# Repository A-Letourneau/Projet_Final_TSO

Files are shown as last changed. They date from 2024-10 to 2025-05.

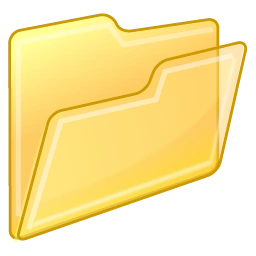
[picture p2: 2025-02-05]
Code/Mallette_GUI/Code de test/Folder.png

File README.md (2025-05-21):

# Projet de Mallette D'évasion 🎲🔐

Bienvenue dans notre projet de **jeu d'évasion** Pour le cours de *Planification de projet* de la *technique de système ordiné*! Ce jeu mettra à l'épreuve vos capacités de réflexion, de résolution d'énigmes,
et les matières vues en classe. Explorez une mallette remplit de mystère et découvrez des secrets pour vous échapper avant la fin du temps imparti !

---

## 🚀 Fonctionnalités principales
- **Scénarios immersifs** : Plongez dans des histoires captivantes, adaptées à tous les publics.
- **Énigmes variées** : Résolvez des casse-têtes mêlant logique, observation, et coordination.
- **Système de progression** : Sauvegardez votre progression et débloquez de nouveaux défis.
- **Grande Modularité** : Changez les énigmes ou encore provoquez des erreurs pour vos élèves.

---

## 🛠️ Technologies utilisées
- **Backend** : [Python3, C++]
- **Interface utilisateur** : Design intuitif avec [SimpleGUI]

---

## 📦 Installation

### Prérequis
- Les outils nécessaires : [Python, C++, SimpleGUI]
- Matériel physique : [Raspberry Pi4b, esp32C3 DevKit2, bouton, potentiomètre, switch]

---

📧 Contact
Pour toute question ou suggestion :

**Pour contacté Louis :**
- Email : A21.louis.boisvert@cegepsherbrooke.qc.ca
- GitHub : https://github.com/L3MMINGS

**Pour contacté Alexis :**
- Email : a22.alexis.letourneau@cegepsherbrooke.qc.ca
- GitHub : https://github.com/A-Letourneau

Bon jeu et amusez-vous à vous échapper ! 🚪✨

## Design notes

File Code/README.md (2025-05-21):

# 📂 Code

Ce dépôt regroupe 4 ensembles de fichiers essentiels pour le fonctionnement du prototype. 

## 📂 I2C et JSON pour ESP32  
Ce dossier contient le code en C++ chargé dans les ESP32.  
Il permet à ces derniers d’envoyer des messages JSON en I2C contenant l'état des objets interactifs au Raspberry PI.  

---

## 📂 Interface Graphique (Mallette GUI)  
Ce dossier contient :
- Le code Python nécessaire pour afficher les données i2c reçues sous forme de JSON dans une interface.  
- L’affichage à l’écran est réalisé à l’aide de la bibliothèque **PySimpleGUI**. 

---

## 📂 Clavier esp32
Ce dossier contient :  
- Le code "main.py" qui va dans un clavier esp32 qui utilise la librairie kmk_firmware .  

---

### 🛠️ Notes
Chaque dossier est structuré pour permettre une utilisation autonome des fonctionnalités qu’il contient. Consultez les fichiers README individuels dans chaque dossier pour plus de détails.

Correction

28 oct 5/5 

4 nov 5/5

11 nov 5/5 

24 nov 5/5 (Bravo pour le beau readme.md du dossier principal).

3 déc 5/5

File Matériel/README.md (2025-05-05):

# Dossier pour les schémas Altium
Ce document contient les schémas électriques et le schéma des PCB.

---
## 📂Fichier de fabrication 
Les fichiers de fabrication à envoyer au fabricant de PCB

## 📂PCB mallette Altium
Les fichier Altium pour le schéma électrique et le PCB

## 📂Fichier la clé du savoir logo
Les fichiers contenant l'espace de travail et quelques version du logo de la mallette.
Le logo à été fait par Alexis Desainde.

## Schema_MalletteDevasion_BOM REV 1.00 (BOM)
Liste des composants du PCB

## Plan de test PCB mallette
Les tests pour le bon fonctionnement du PCB et les améliorations possibles

## Équerre 2 inserts 
Fichier stl qui contient les supports pour tenir la vitre dans la mallette
---

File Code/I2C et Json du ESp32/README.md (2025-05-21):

# Programme de Communication I2C avec JSON pour ESP32

Ce fichier contient tous les codes fait en rapport avec les esp32 en c++

Les programmes de CODE_ESP32_POT, CODE_ESP32_SW et CODE_ESP32_CROCO permet d’envoyer les états des objets interactifs (interrupteur, potentiomètre et fils banane/croco) dans un JSON via communication I2C à un maître.  
Le maître utilisé dans notre projet est un **Raspberry Pi 4**.  
Les sub (esclaves) utilisés dans notre projet est le **esp32 c3 devkit 02**

## Configuration d’un Nouveau Module d’Énigme avec un ESP32  

Pour ajouter un nouveau module, suivez ces étapes :  

1. **Définir une adresse différente pour chaque module :**  
   Attribuez une valeur unique à **`SLAVE_ADDR`**, différente de celles des autres ESP32 connectés au Raspberry Pi.  

2. **Configurer les broches I2C (si nécessaire) :**  
   - Modifiez la ligne **`Wire.setPins()`** pour définir les broches I2C souhaitées.  
   - Si l’ESP32 utilise déjà des broches par défaut, cette ligne peut être supprimée.  
   - Les pattes arbitraires pour le i2c que nous avons choisi est le 6 pour SDA et 7 pour SCL.

3. **Personnaliser l’identifiant du module :**  
   Changez la valeur de la variable **`ESP32_NAME`** pour identifier le module.  

4. **Adapter le fichier `platformio.ini` :**  
   - Vérifiez que le fichier **`platformio.ini`** correspond à la carte ESP32 utilisée.  
   - Si vous utilisez une carte différente (par ex. **ESP32-WROOM** ou **ESP32C3 DevKit2**), adaptez les configurations en conséquence.  

---

### Remarque  
Assurez-vous que tous les modules sont correctement configurés pour éviter les conflits d’adresse sur le bus I2C.
Utilisez i2cdetect -i 0 sur le cmd du pi pour détecter les connections i2c

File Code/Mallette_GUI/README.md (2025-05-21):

# Dossier de Tests pour l'interface GUI du PI

Ce dossier contient plusieurs répertoire de test et un répertoire du prototype fonctionnel.

# Contient
- "Code de test" : Dossier de code de test pour développer l'interface 
- "Prototype Fonctionnel sur PI" : Les fichiers de code fonctionnel sur le PI

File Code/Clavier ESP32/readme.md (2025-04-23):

Pour entrer dans le mode programmation du clavier esp32 :
Appuyer sur le bouton RESET
En restant appuyé, appuyer sur le potentiomètre
Puis relacher le bouton RESET
Un répertoire devrait s'ouvrir sur l'ordinateur

Pour programmer votre clavier esp32:
Remplacer le fichier code.py dans le répertoire avec le fichier code.py sur le git
Le fichier important est code.py qui peut être modifié selon les informations sur : https://github.com/KMKfw/kmk_firmware

La souris est déjà configuré, mais voici comment configurer la souris avec le clavier esp32:
Dans le fichier code.py
1 - Ajouter la ligne "from kmk.modules.mouse_keys import MouseKeys" dans "# Keys"
2 - Ajouter la ligne "mouse = MouseKeys()" dans "#KEYBOARD SETUP"
3 - Ajouter "mouse" dans la liste de module "keyboard.modules = [encoder_handler, tapdance, mouse]"
Optionnel - mettre :
"mousekeys = MouseKeys(
    max_speed = 10,
    acc_interval = 20, # Delta ms to apply acceleration
    move_step = 1
)" pour ajuster la vitesse

La configuration actuelle des 12 touches:
[A]         [MS_UP]     [MS_UP]     [BSPACE]
[MS_LEFT]   [MB_LMB]    [MS_RIGHT]  ['+']
[MS_DOWN]   [MS_DOWN]   [keypad_3]  ['-']

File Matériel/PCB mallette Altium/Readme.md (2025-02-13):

# Mallette d'Évasion

## Description du Projet
La **Mallette d'Évasion** est un projet réalisé dans le cadre du cours **247-67P-SH Projet de fin d'études** en génie électrique. Il s'agit d'un système électronique basé sur un **Raspberry Pi 4** et plusieurs **ESP32-C3**, intégrant divers capteurs et composants pour résoudre des énigmes interactives.

## Concepteurs
- **Louis Boisvert**
- **Alexis Letourneau**

## Date
- **30 janvier 2025**

## Technologies Utilisées
- **Raspberry Pi 4 Model B (4GB)**
- **ESP32-C3-DEVKITC-02**
- **I2C (SDA/SCL)**
- **Boutons et interrupteurs**
- **Bandes de DEL**
- **Potentiomètres**
- **Pinces crocodiles**
- **PCB personnalisé**

## Schémas Principaux
1. **Raspberry_Pi** : Gestion centrale du système
2. **Schéma_Bloc** : Vue d'ensemble des connexions
3. **Énigme1_Interrupteur** : Activation d'un mécanisme via interrupteurs
4. **Énigme2_Pince_Banane** : Détection de contacts avec pinces crocodiles
5. **Énigme3_Potentiomètre** : Réglage d'une valeur par potentiomètres

## Fonctionnalités
- **Communication entre Raspberry Pi et ESP32 via I2C**
- **Gestion des entrées/sorties GPIO pour les énigmes**
- **Alimentation 3.3V et 5V pour les composants**
- **Intégration de multiples résistances et condensateurs pour stabilisation**
- **Utilisation de buffers 74HC1G125GV pour sécuriser les signaux**

## Instructions d'Utilisation
1. **Alimenter le système** : Assurez-vous que le Raspberry Pi et les ESP32 sont correctement branchés.
2. **Vérifier les connexions I2C** : Assurez-vous que les broches SDA et SCL sont bien connectées.
3. **Démarrer les énigmes** : Interagir avec les boutons, interrupteurs, pinces et potentiomètres pour progresser.

## Développement et Déploiement
- **Code source** : À stocker sur le Raspberry Pi
- **Configuration des GPIO** : À vérifier dans le script de contrôle
- **Tests** : Vérifier chaque énigme séparément avant l'intégration complète

## Améliorations Possibles
- Ajout d'un affichage LCD ou OLED pour des indices visuels
- Intégration de modules audio pour une meilleure immersion
- Optimisation du code pour améliorer la réactivité

## Licence
Ce projet est réalisé dans le cadre académique et son utilisation est limitée à des fins éducatives.

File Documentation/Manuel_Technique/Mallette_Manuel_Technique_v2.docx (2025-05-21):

Louis Boisvert

Alexis Létourneau

Groupe : 2317

La clé du savoir

Manuel technique présenté à :

Benoit Beaulieu

Nicolas Huppé

Louis-Philippe Gauthier

Étienne Desbiens

Département du génie électrique

Pour le cours :

247-67P-SH PROJET DE FIN D'ÉTUDES

Cégep de Sherbrooke

Mai 2025

# 1 Description générale du projet:

InXtremis est un centre d'évasion situé au cœur du centre-ville de Sherbrooke, dirigé par un ancien étudiant en Technologie de Systèmes Ordinés (TSO). Le propriétaire aspire à concevoir une nouvelle salle intégrant des éléments interactifs électronique grâce à des dispositifs électroniques dissimulés dans les énigmes. Plusieurs de ses salles actuelles utilisent déjà un ou deux dispositifs électroniques permettant d'ouvrir des portes et de suivre le progrès des joueurs. Cependant, il souhaite aller encore plus loin en créant une salle entièrement interconnectée, sans cadenas pour rythmer la progression.

Si les mécanismes simples, comme l'ouverture d'une énigme après la résolution de la précédente, sont faciles à mettre en place, le propriétaire ambitionne d'offrir une expérience encore plus impressionnante avec une énigme finale particulièrement spectaculaire. Pour concrétiser cette vision, il fait appel aux finissants du programme TSO.

L'objectif est de concevoir un module sous la forme d’une mallette renfermant une série de plusieurs énigmes. Le temps nécessaire pour résoudre ces énigmes devra être compris entre 5 et 10 minutes. Le module devra également offrir une remise en court pour accueillir rapidement la prochaine équipe.

La mallette devra être robuste pour résister à une mauvaise manipulation ou à une utilisation intensive. Le circuit électronique devra être facilement accessible pour les interventions de maintenance, de dépannage ou de démonstration. De plus, il devra pouvoir communiquer avec les autres éléments de la salle pour suivre la progression des joueurs et détecter des problèmes éventuels, comme la tentative de contourner une énigme.

Voici une photo de la mallette assemblée :

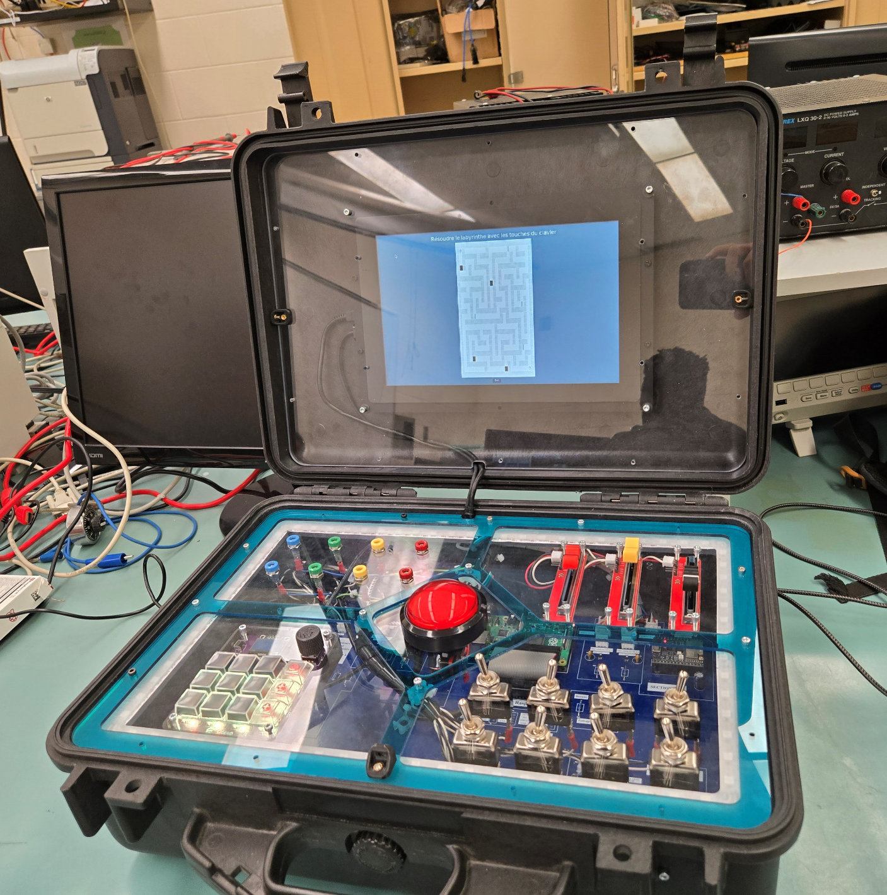
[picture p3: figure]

Figure 1 : Mallette assemblée

# 2 Fonctionnement de la mallette:

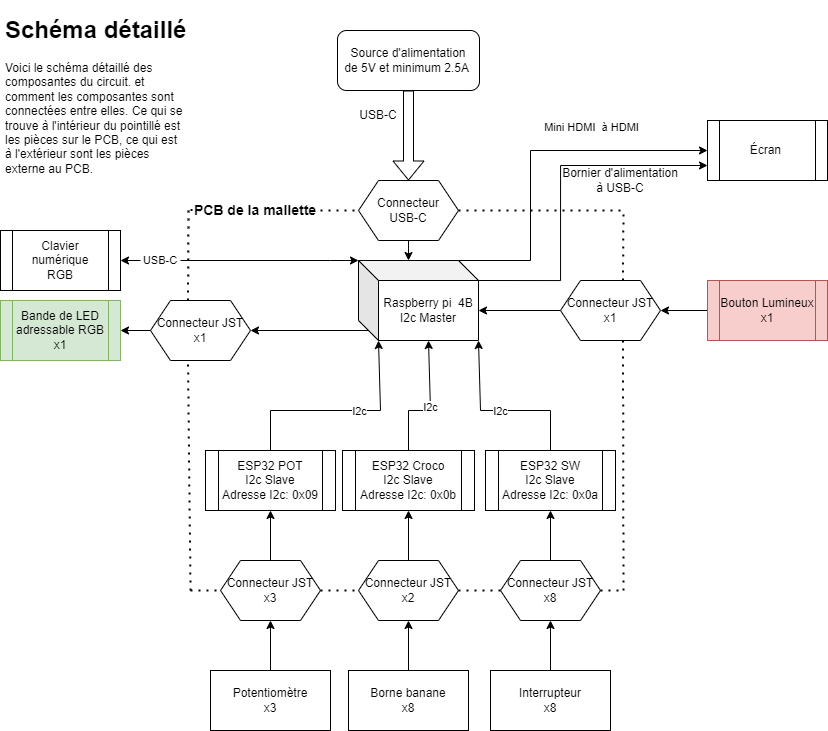
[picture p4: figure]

3.5 A

Figure 2 : Schéma de connections des composantes

## 2.1 Descriptions générales du schéma :

La mallette est composée d’un Raspberry Pi connecté en I2C en «Main» avec 3 esp32 en mode «Sub» et d’un clavier esp32 connecté au port USB du Pi. Les 3 esp32 sont connectés à des « éléments interactifs » comme des boutons, des interrupteurs, des potentiomètres et des bornes bananes avec des connecteurs JST.

Présentement, un des esp32 est connecté avec 8 interrupteurs, un autre esp32 avec 3 potentiomètres coulissant et un esp32 avec 8 bornes bananes. Dans cette architecture, le Pi fait des requêtes I2C au esp32 à chaque intervalle en secondes fixé dans le code et reçoit un JSON contenant les valeurs des éléments interactifs des esp32. Ces valeurs sont ensuite intégrées dans une énigme créée en python qui s’affiche sur un mini écran connecté au Pi.

Le clavier esp32 utilise une librairie spéciale qui permet de s’en servir en clavier et en souris. Le clavier esp32 vient pré assemblé avec 12 touches programmables.

Le PI contrôle aussi des bandes de DEL adressable pour illuminer la mallette et indiquer la réussite des énigmes.

Le PI est aussi connecté à un bouton lumineux. Le Pi détecte l’état du bouton et peut contrôler sa DEL interne.

Comme un des buts principales de la mallette est d’être modulable, elle n’a pas de programmation prédéterminée, par exemple : Le bouton lumineux pourrait tant allumer les bandes de DEL qu’être un élément de réponse dans une des énigmes. Les bandes de DEL pourrait illuminer la mallette, être un indice ou indiquer le temps avec des clignotements de plus en plus rapidement. Cependant, la mallette contient un exemple d’une série de d’énigme en python qui utilise tous les éléments interactifs de la mallette.

## 2.2 Raspberry Pi :

- Le Pi est le « Main » dans la communication I2C et envoie des requêtes d’informations au ESP32 très fréquemment (50 ms de base). Il reçoit un JSON comportant le nom du esp32 et l’état de ses éléments interactifs.
- Le Pi reçoit ces informations et intègre ces informations dans des énigmes. Les énigmes sont affichées sur une interface utilisateur qui utilise la librairie PySimpleGUI. Chaque énigme intègre différents éléments interactifs.
- Lors du démarrage du Pi, le programme « autostart » ouvre automatiquement le programme de série d’énigme.
- Le Pi prend en charge un clavier esp32 qui se connecte sur un port USB pour contrôler des lettres et la souris
- Le Pi reçoit l’état d’un bouton lumineux et peut faire allumer sa DEL.

## 2.3 Esp32 :

- Chaque ESP32 lit l’état des éléments interactifs et l’envoi en JSON au Pi via i2c. Les ESP32 sont des « Sub » attendant les requêtes du Raspberry Pi.
- Voici un exemple de JSON envoyé au PI :

{ «NomEsp32 »: « I2C _SW », « JsonData » : {« SW1 »: « 0 » , « SW2 »: « 1 » , « SW3 »: « 0 » } }

Dans ce cas, le nom du esp32 est le « I2C _SW », donc celui avec des interrupteurs, et le Pi reçoit que le bouton numéro 2 est appuyé. Le JsonData pourrait aussi contenir des valeurs analogues comme avec le esp32 « I2C _POT » qui s’occupe des potentiomètres.

- Le code de chaque esp32 est en c++ Arduino.
- Chaque esp32 est codé avec un « battement de cœur » sur sa DEL Neopixel qui montre que le esp32 est actif au démarrage et durant la communication I2C entre le esp32 et le Pi.

## 2.4 Connecteurs JST :

- Les connecteurs JST permettent de faire la connexion rapide et interchangeable entre la carte électrique (PCB) et le matériel externe tel que les éléments interactifs et les bandes de DEL.

## 2.5 Mini écran :

- Le mini écran est le moniteur du Pi et affiche la série l’énigmes.
- Le mini écran peut aussi servir à offrir des indices, un message de fin et de début ainsi qu’une mise en situation.
- Le mini écran possède aussi des haut-parleurs intégrés permettant de jouer différents sons selon les actions effectuées par l’utilisateur. Cependant cette fonctionnalité n’est pas utilisée.

## 2.6 Bandes de DEL adressable :

- Les bandes de DEL adressable permettent d’ajouter un élément visuel à la mallette.
- Les bandes de DEL adressable sont contrôlées par le Raspberry Pi et permettre présentement de signaler à l’utilisateur la réussite d’une énigme par la couleur verte ou l’échec de l’énigme par la couleur rouge. Les bandes de DEL adressable pourrait aussi illuminer la mallette, être un indice ou indiquer le temps qui découle avec des clignotement de plus en plus rapidement.

## 2.7 Rôle du bouton lumineux :

- Le Pi détecte l’état du bouton lumineux et peut contrôler la DEL interne bouton lumineux .
- Le bouton lumineux pourrait permettre d’arrêter le décompte mettant fin à la série d’énigmes. Pour l’instant, il active uniquement la fonction Rainbow() des DEL.

## 2.8 Alimentation :

- Un bloc d’alimentation murale fournira une tension de 5V par USB-C au circuit électrique (PCB). Il sera possible de connecter un chargeur portatif (pile de 5V avec prise USB-C) au lieu de le brancher au mur lors de démonstration où les prises murales ne sont pas facilement accessibles.
- Avec un mesureur de courant USB, nous avons déterminé que le courant maximale de toute la mallette est de 3.2 ampères.
- Les esp32 et le Raspberry Pi, seront alimentés par le circuit électrique (PCB).
- Le mini écran ne peut pas être alimenté par le Raspberry Pi, car le Pi ne peut pas sortir assez de courant pour alimenter l’écran et tout le reste du PCB. Le mini écran par le bloc d’alimentation murale directement via un dédoubleur de câble USB-C.

# 3 Procédure d’installation et d’opération :

## 3.1 Procédures pour installer

1 Brancher une source d'alimentation sur le port USB extérieur à l’arrière de la mallette. Vous pouvez prendre un bloc d'alimentation ou une batterie.

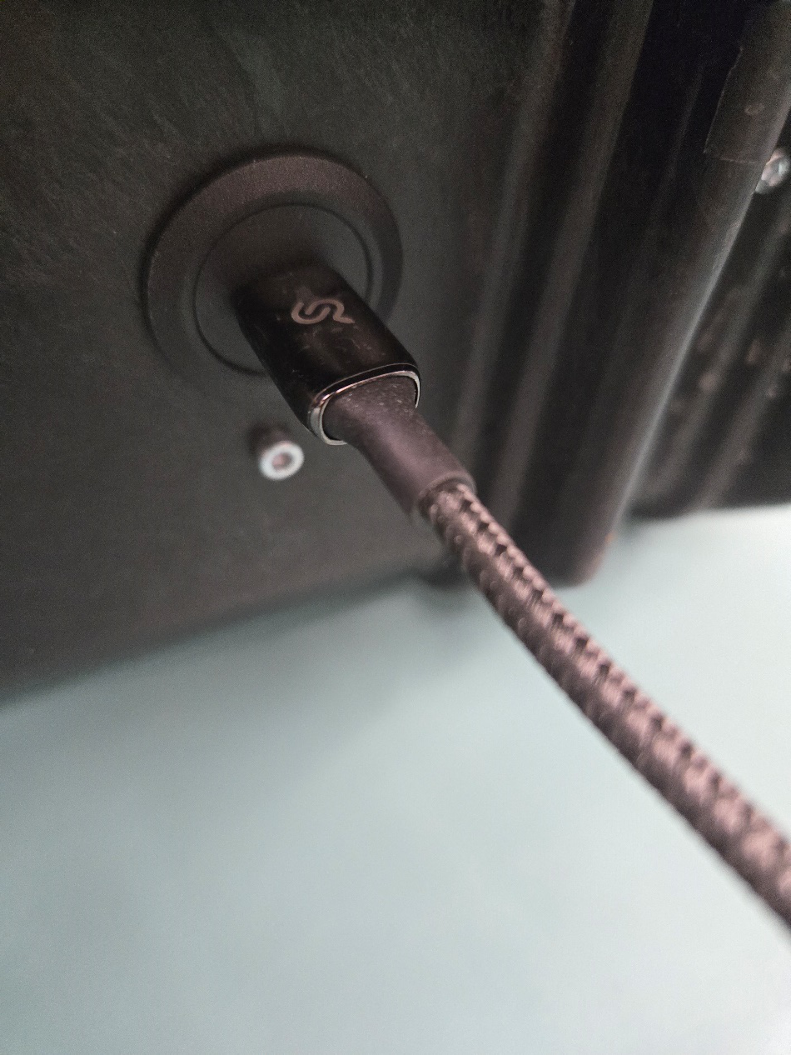
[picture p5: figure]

Figure 3 Connection alimentation USB-C

2 Attendre que l'ordinateur s'ouvre

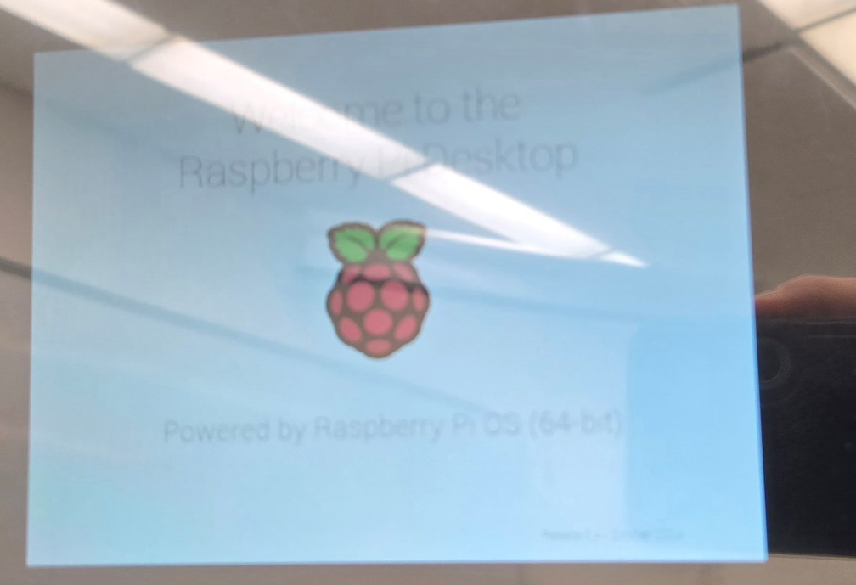
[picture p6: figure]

Figure 4 Écran de démarrage

3 Vous devriez voir le programme d'énigme s'ouvrir automatiquement sur une des énigmes.

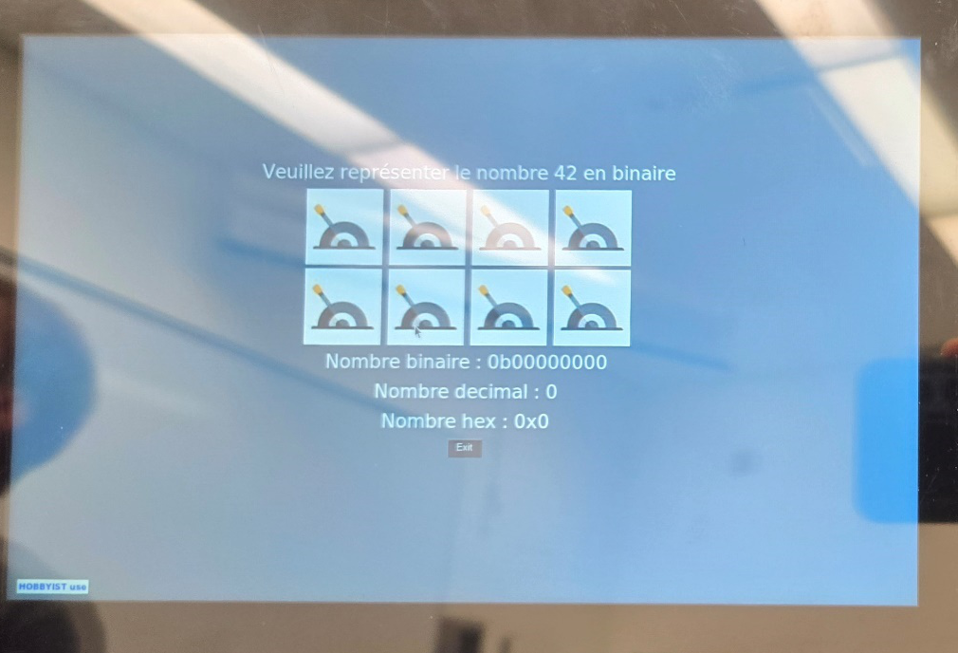
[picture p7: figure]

Figure 5 Énigme des interrupteurs

Pour recommencer la série d’énigme, il faut débrancher la mallette et la rebrancher.

# 4 Mise en route, validation du fonctionnement, dépannage :

Si tout est bien configuré, lors du démarrage de la mallette, une fenêtre devrait s’ouvrir sur le mini écran vous permettant de sélectionner une énigme. Les trois énigmes devraient fonctionner comme dans la section « fonctionnement de la mallette ».

## 4.1 Bug et dépannage

Si l’énigme se ferme automatiquement, alors une exception est arrivée. Pour avoir plus d’information sur l’exception, il faut faire exécuter le code manuellement dans Thonny comme décrit plus haut et essayer de répéter les mêmes étapes qui ont mené à l’exception.

Si le titre d’une énigme devient rouge et qu’elle ne répond plus, cela veut dire que la communication I2C a été interrompu. Vérifier que le esp32 est bien branché selon les indications sur le silkscreen. Vous pouvez utiliser un multimètre en mode résistance pour vous assurer de la connexion entre les pattes I2C du esp32 et du Pi.

# 5 Contenu matériel :

## 5.1 Énigme interrupteur:

Chaque interrupteur est connecté à une GPIO d’un esp32 en mode entrée et sont tous équipés de pull-up. Les GPIO 6 et 7 sont le SDA et le SCL respectivement pour la communication i2c. La patte de reset du esp32 est connecté au Pi pour pouvoir commencer la communication i2c lors du démarrage du programme.

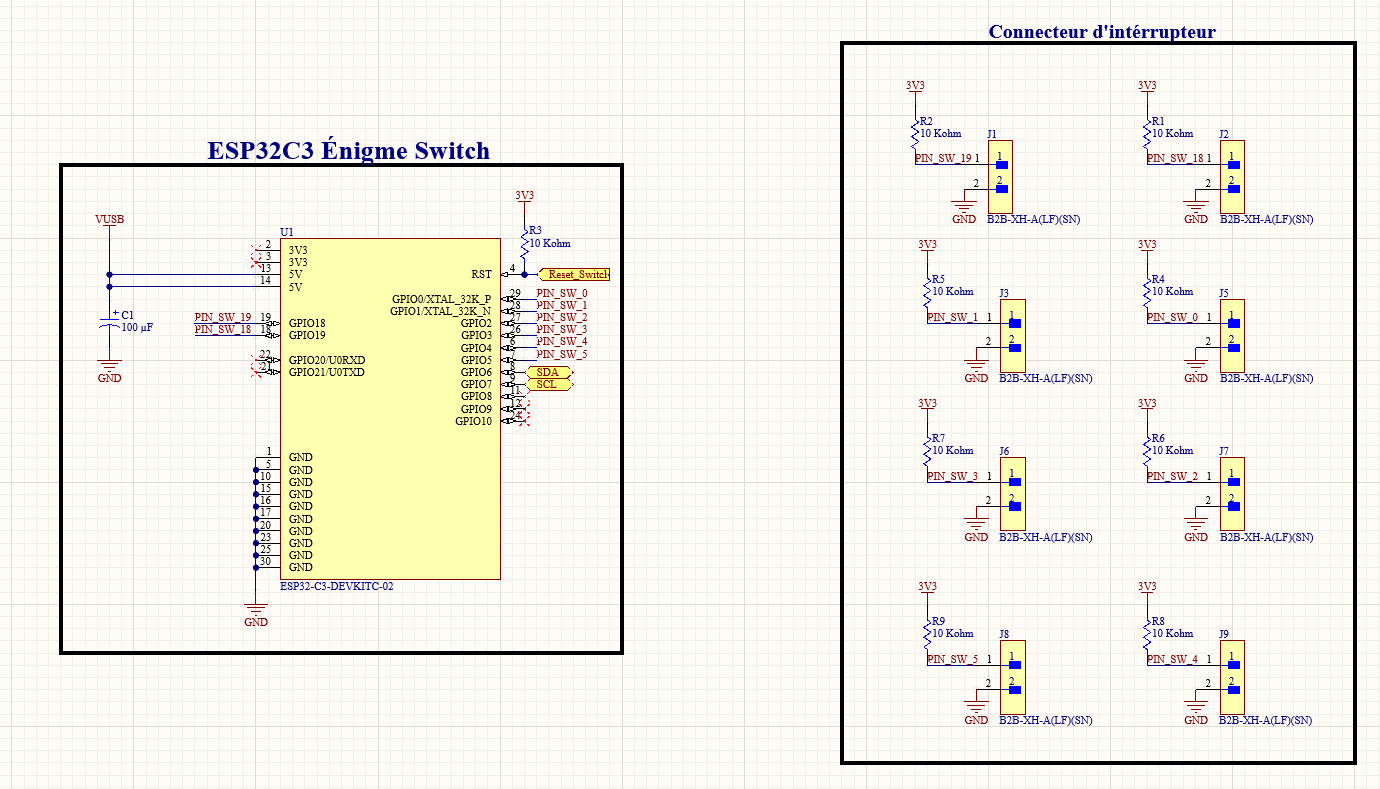
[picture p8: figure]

Figure 6 : Schéma électrique interrupteur

## 5.2 Énigme bananes:

Chaque bornes bananes est connecté à une GPIO d’un esp32. Cela permet le changement rapide entre entrée pull-down qui écoute pour un signal haut et sortie qui envoi le signal haut, dans le but de savoir quelle bornes sont interconnectées. Les GPIO 6 et 7 sont le SDA et le SCL respectivement pour la communication i2c. La patte de reset du esp32 est connecté au Pi pour pouvoir commencer la communication i2c lorsque le Pi est prêt à initier la communication.

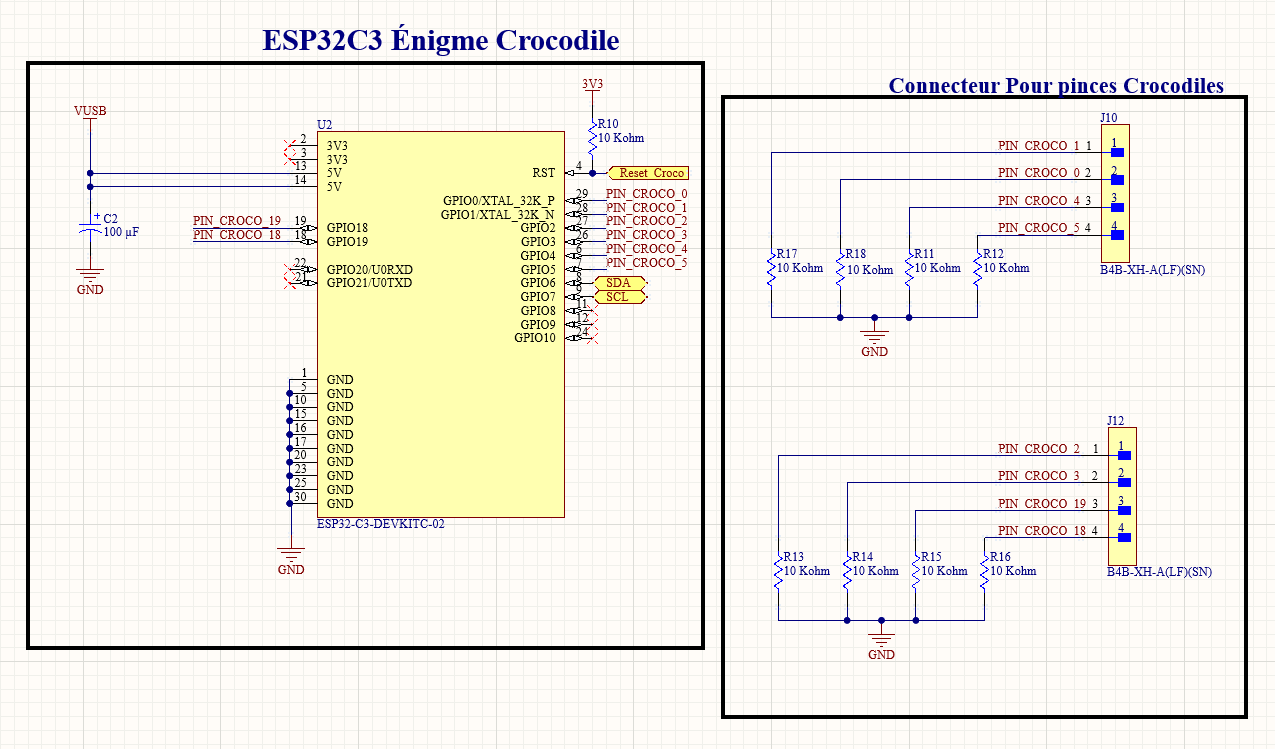
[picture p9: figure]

Figure 7 : Schéma électrique banane

## 5.3 Énigme Potentiomètre:

Chaque potentiomètre est connecté à une GPIO du esp32 en mode entrée analogique et sont tous équipés avec une pull-down. Les GPIO 6 et 7 sont le SDA et le SCL respectivement pour la communication i2c. La patte de reset du esp32 est connecté au Pi pour pouvoir commencer la communication i2c lorsque le Pi est prêt à initier la communication.

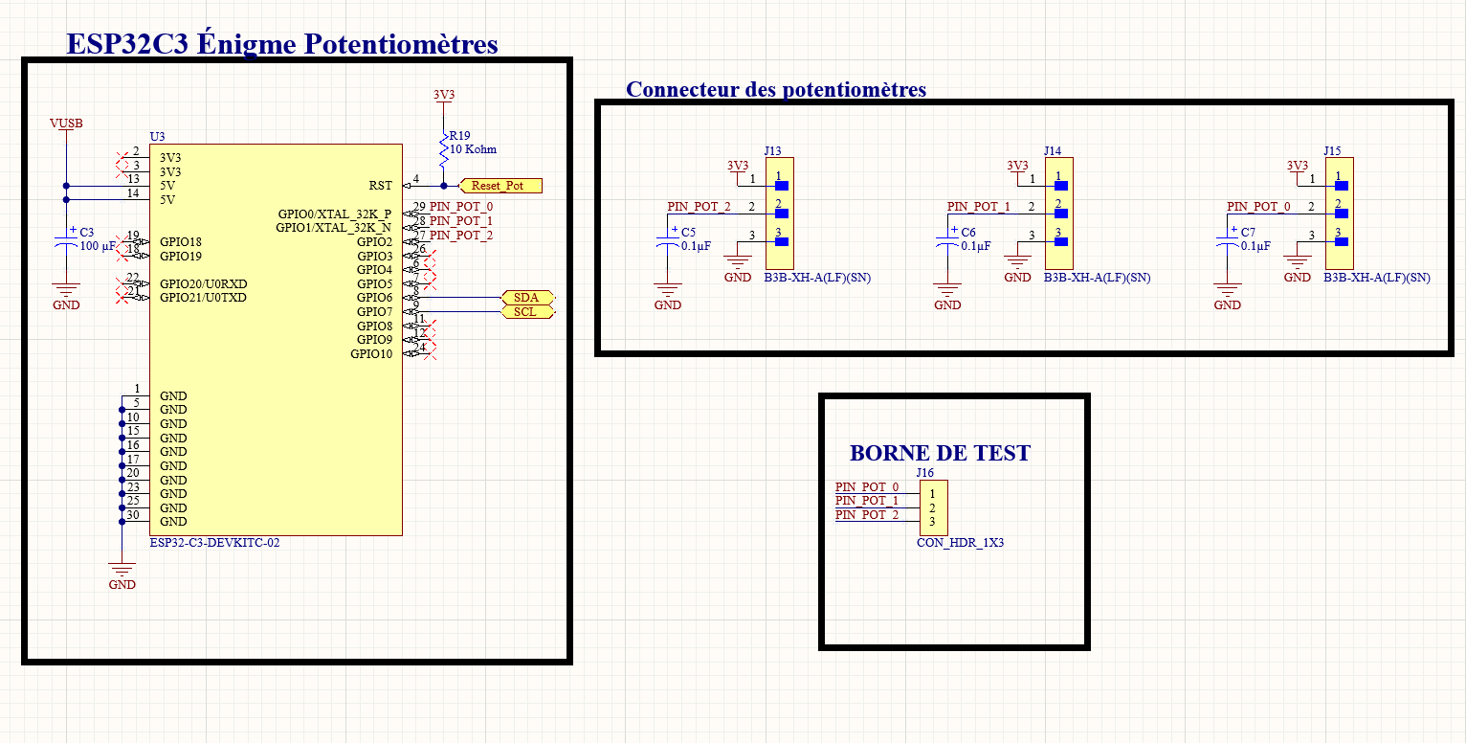
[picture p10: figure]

Figure 8 : Schéma électrique potentiomètre

## 5.4 Bouton lumineux :

Le bouton lumineux a deux fonctions contrôlées par le Pi. Il allume une DEL au centre du bouton et il donne l’état du bouton normalement ouvert.

Les pattes 1 est la cathode et la patte 2 est l’anode de la DEL. Lorsque PIN_PI_26 est haut, la DEL est éteinte, Lorsque PIN_PI_26 est bas, la DEL est allumée.

Les pattes 3 et 4 sont pour l’interrupteur, PIN_PI_5 est en entrée avec une pull-up.

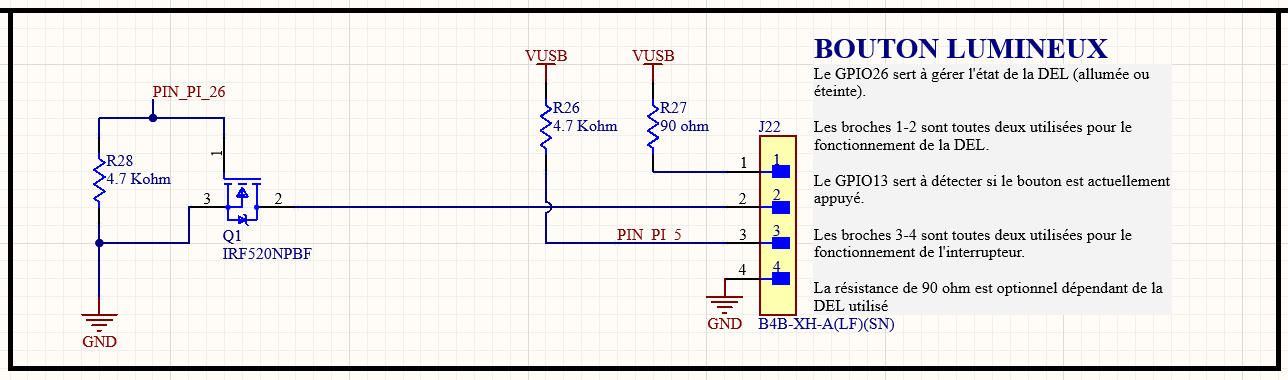
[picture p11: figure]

Figure 9 : Schéma électrique bouton lumineux

Les pattes du connecteur JST sont dans l’ordre suivant.

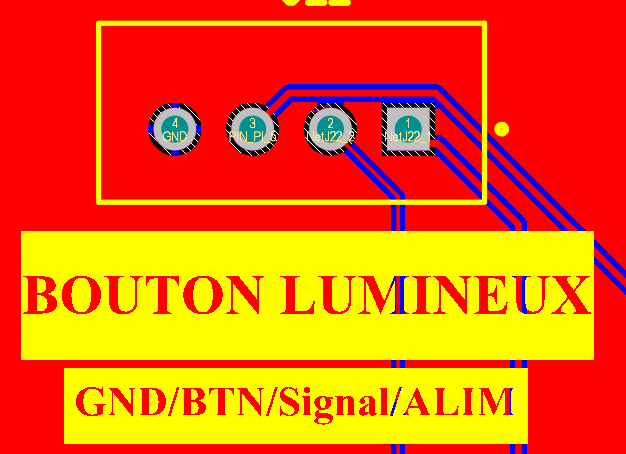
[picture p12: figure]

Figure 10 Ordre des patte du JST du bouton lumineux

## 5.5 Connecteur pour les bandes de DEL adressable:

Comme on utilise une bande de DEL adressable alimenté à 5v, on utilise un level-shifter pour envoyer une signal de 5v sur la patte de signal de la bande de DEL au lieu de 3.3v du Pi.

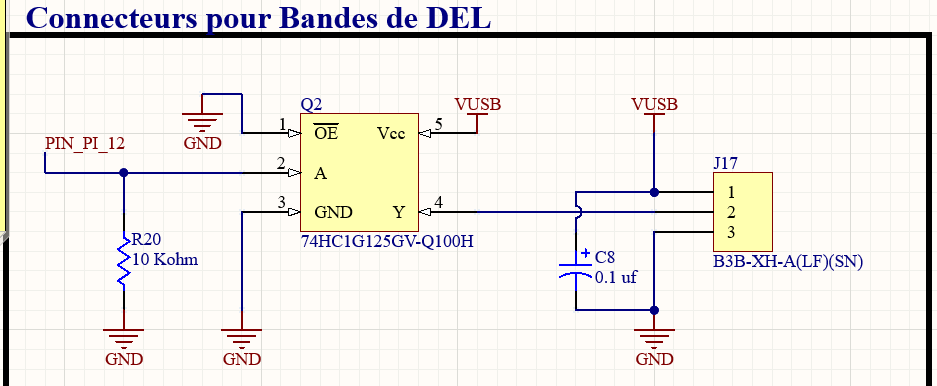
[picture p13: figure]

Figure 11 : Schéma électrique bande de DEL ADR

# 6 Contenu logiciel :

Liens vers le GitHub qui contient tous les codes commentés et autres composants nécessaires au fonctionnement de la mallette:

https://github.com/A-Letourneau/Projet_Final_TSO

Veuillez-vous référer à tous les Readme.md sur GitHub pour plus d’information

## 6.1 Programme de série d’énigme de base:

- La mallette contient un programme en python qui part lors du démarrage du PI. Ce programme reçoit les états des objets interactifs dans un JSON via i2c puis l’intègre dans une énigme.
- Le programme affiche sur le mini écran l’énigme avec la librairie PySimpleGUI.
- Le programme contrôle les bandes de DEL adressable et le bouton lumineux.
- Le programme est constitué de plusieurs fichiers :
- « main.py » est le point d’entrée du programme qui permet de démarrer les énigmes dans les autres modules ci-dessous.
- « Class_Croco.py » contient une énigme qui demande à l’utilisateur de connecter des bornes bananes numérotées ensemble pour compléter une équation. Exemple, la borne numéro 2 et la borne numéro 6 sont connectées ensemble et le programme veut une multiplication de deux chiffres qui égale 12, dans ce cas l’énigme est réussie car 12 = 2 x 6.
- « Class_POT.py » contient une énigme qui demande à l’utilisateur de manipuler des potentiomètres pour changer les paramètres d’amplitude, de période et de position en y d’un sinus dans le but de recopier un autre sinus généré aléatoirement.
- « Class_SW.py » contient une fenêtre de débogage qui affiche l’état des interrupteurs.
- « I2c_Comm.py » contient la communication i2c.
- Voici l’ordinogramme de « main.py », « Class_Croco.py » et « Class_POT.py » :

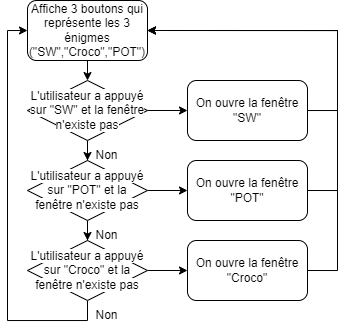
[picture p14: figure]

Figure 12 Ordinogramme du main.py

- Figure 13 Ordinogramme énigme équation

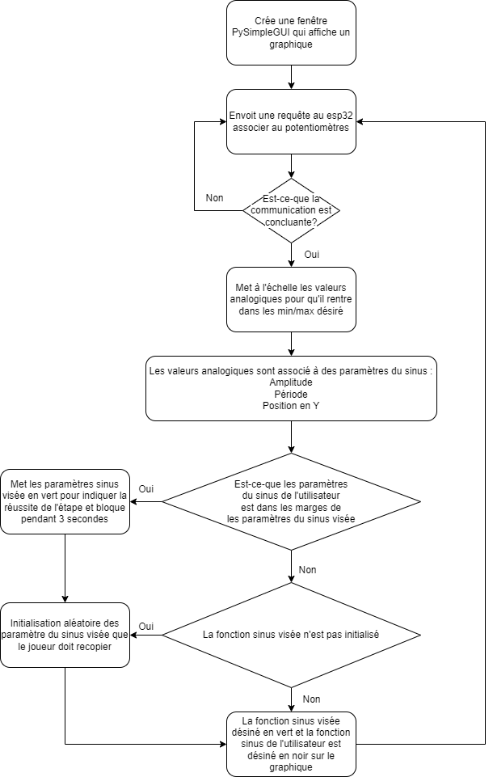
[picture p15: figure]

Figure 14 Ordinogramme énigme Sinus

# 7 Procédure de développement :

## 7.1 Branchement du PCB :

Brancher un bloc d’alimentation murale sur le port USB-C à l’extérieur de la mallette. Ce port USB-C extérieur est connecté au port USB-C vertical du PCB qui alimente le circuit. Ce même port USB-C extérieur sert à alimenter le mini écran. Les esp32 et le Pi sont alimenté par le port USB-C vertical via le PCB.

Ensuite, connecter le port micro-HDMI du Pi au port HDMI du mini écran.

Ensuite, il faut connecter les connecteurs JST des éléments interactifs, des bandes de DEL adressable et du bouton lumineux sur le PCB. Les indications sur le PCB indiquent où mettre chaque composant. Veuillez mettre un indicateur à chaque bout des fils JST, cela facilitera le débogage quand tous les fils seront en couette.

## 7.2 Initialisation du Raspberry PI :

### 7.2.1 Initialisation d'une nouvelle carte microSD pour un Raspberry Pi :

Veuillez initialiser votre Raspberry Pi avec le système d’opération Raspbian avec la documentation officiel suivante : https://www.raspberrypi.com/documentation/computers/getting-started.html

### 7.2.2 Créer, initialiser et utiliser l’environnement virtuel sur le Pi :

Un environnement virtuel permet d’installer seulement les librairies pythons nécessaire au projet et de le rendre exclusif au fichier. L’alternative est de les installer de manière Global, mais certaine librairies peuvent rentrer en conflit.

Vous pouvez prendre l’environnement virtuel déjà fait disponible sur le GitHub dans la section « \Code\Mallette_GUI\Proto_Fonct_PI » du projet, mais si vous voulez faire votre propre environnement virtuel voici la procédure :

1. Créez votre environnement virtuel avec la commande « python3 -m venv votre/chemin/de/fichier ».
2. Activez votre environnement virtuel avec la commande « source ./venv/bin/activate »
3. Ajouter des librairies avec la commande « python3 -m pip install XYZ ». XYZ est le nom de librairies voulu, voici la liste des librairies du projet :
- 'smbus2' Pour la communication I2C .
- 'PySimpleGUI' Pour l’interface utilisateur.
- 'rpi_ws281x' Pour la communication avec les DEL adressable.
- 'Adafruit-Blinka' Pour pouvoir accéder au GPIO du Pi.
- Les autres librairies sont installées par défaut.

À des fins de débogage, si vous voulez exécuter le programme des énigmes, il faut activer l’environnement virtuel dans votre éditeur de code Python. L’éditeur de python de base dans Raspbian est Thonny, pour activer l’environnement virtuel, appuyer sur « Configure interpreter » et sélectionner le fichier « venv/bin/python3 » dans votre environnement virtuel.

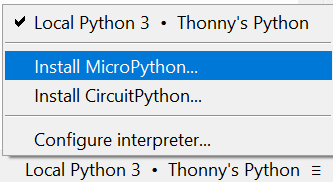
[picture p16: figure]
Getting started with Raspberry Pi Pico

Figure 15 Configurer l'interpréteur python

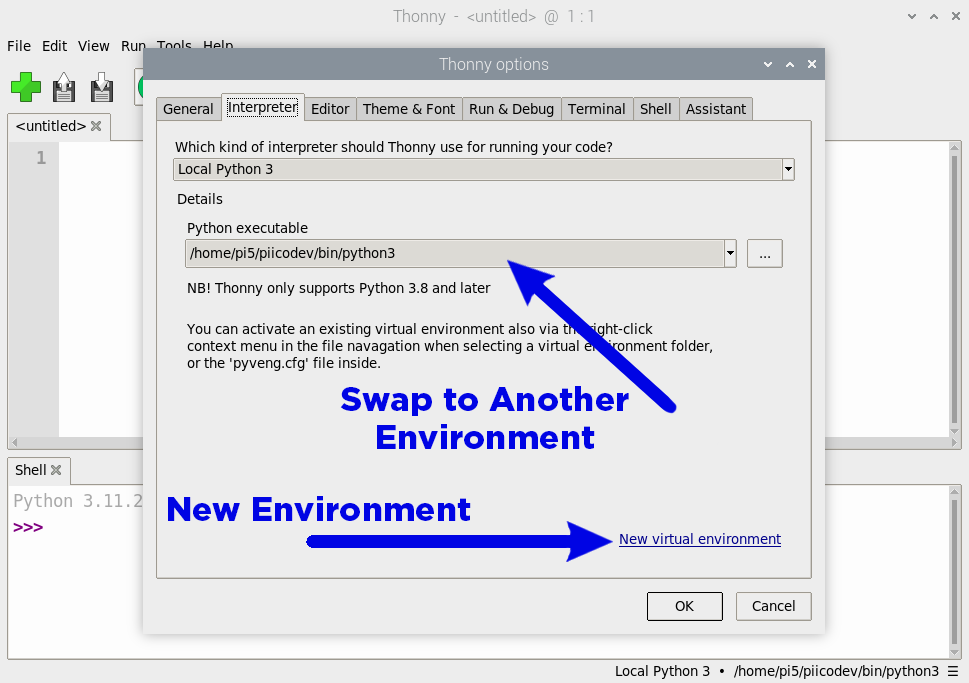
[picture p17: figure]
Using Virtual Environments in Thonny on a Raspberry Pi - Tutorial Australia

Figure 16 Configurer l'interpréteur python

### 7.2.3 Les fichiers et l’exécution du programme de série d’énigme de base :

Tous les fichiers pour le programme de série d’énigme de base sont sur le GitHub dans le fichier CODE_POUR_PI_FONCTIONNEL. Veuillez sélectionner tous les fichiers et le mettre dans un répertoire de votre Pi. Assurez-vous que les 4 librairies spécifiques au projet soit installé dans le même répertoire que le fichier main.py.

Pour exécuter le programme manuellement, il faut démarrer Thonny en mode administrateur avec la ligne « sudo Thonny » dans le CMD. La librairie pour les DEL adressables demande une autorisation administrateur pour accéder à la puce qui peut contrôler les DEL adressables.

### 7.2.4 Activer le « autostart » d’un programme :

Pour activer le départ automatique d’un programme dans le Pi, le Pi à besoin d’un fichier de configuration .desktop dans le répertoire /etc/xdg/autostart/.

Dans la section \Code\Mallette_GUI\Proto_Fonct_PI du GitHub, vous avez un fichier nommé monautostart.desktop qui va dans le répertoire /etc/xdg/autostart/.

Voici le contenu du fichier :

[Desktop Entry]

Name=monautostart

Exec=sudo /home/Pi/path/to/venv/bin/python3 /home/Pi/Desktop/Git/Projet_Final_TSO/Code/Mallette_GUI/Prototype_Fonctionnel_sur_PI/main.py

Type=Application

X-GNOME-Autostart-enabled=true

La partie importante est la ligne « Exec » :

« Sudo » est pour mettre le programme en administrateur pour la librairie qui contrôle les bande de DEL adressables.

« /home/Pi/path/to/venv/bin/python3 » doit changer selon l’emplacement de votre environnement virtuel.

« /home/Pi/Desktop/Git/Projet_Final_TSO/Code/Mallette_GUI/Prototype_Fonctionnel_sur_PI/main.py » doit changer selon le chemin absolu de votre programme de série d’énigme python.

### 7.2.5 Activer la communication I2C du Pi :

- Exécutez sudo raspi-config.
- Utilisez la flèche vers le bas pour sélectionner « 5 Interfacing Options».
- Utilisez la flèche vers le bas pour sélectionner « P5 I2C ».
- Sélectionnez « yes » lorsque l'option « I2C » est demandée.
- Sélectionnez également « Oui » si l'option « Chargement automatique du module du noyau » est demandée.
- Utilisez la flèche vers la droite pour sélectionner le bouton « Finish».
- Sélectionnez « yes » lorsque l'option « Redémarrer » est demandée.

Pour des image de l’activation: https://learn.sparkfun.com/tutorials/raspberry-Pi-spi-and-I2C -tutorial/all

Pour détecter la présence d’une communication I2C, il faut exécuter la ligne i2cdetect -y 1 dans le CMD, ce qui devra vous donner le résultat suivant :

Si vous n’avez pas les 3 adresses, assurez-vous d’avoir bien téléchargé les code des esp32 dans la section « \Code\I2C et Json du ESp32 » du GitHub dans les esp32 et de les avoir redémarrés avec leurs bouton « reset ».

## 7.3 Configurer les esp32 :

Pour configurer les esp32 il faut ouvrir un des dossier CODE_ESP32_XYZ dans la section « \Code\I2C et Json du ESp32 » du GitHub dans vscode. Il faut s’assurer d’avoir l’extensions c++ et platform.io. Pour les installer, dans vscode, aller dans l’onglet extension et chercher les extensions dans la barre de recherche.

Connectez votre ordinateur et un des esp32 avec un fil USB-C puis upload le main.cpp de chaque CODE_ESP32_XYZ dans le esp32 correspondant.

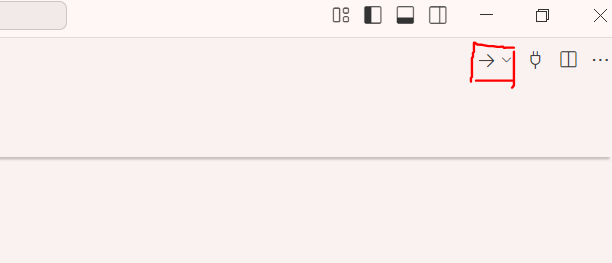
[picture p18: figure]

Figure 17 Téléchargement d'une code dans platform.io

Si le téléchargement est réussi, vous devriez voir ceci :

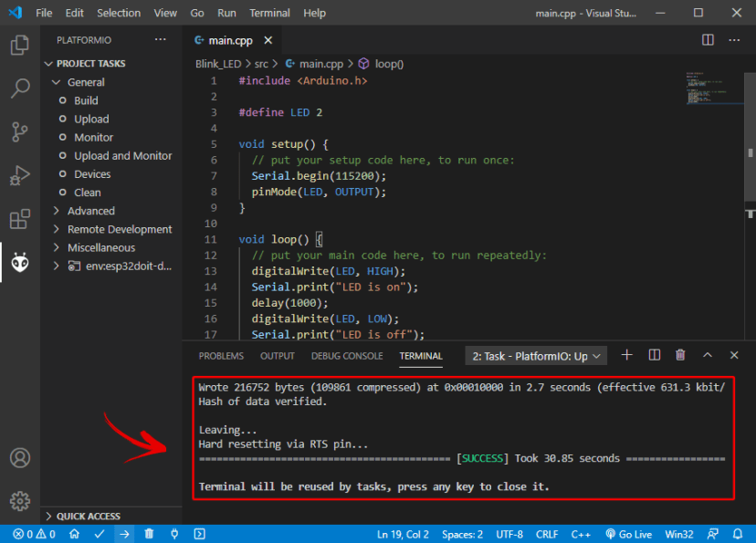
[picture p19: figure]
Upload Code to ESP32 PlatformIO VS Code Success

Figure 18 Téléchargement réussi du code

## 7.4 Mode programmation du clavier:

Le clavier esp32 agit comme un clavier et une souris, mais il ne contient que 12 touches. Il se connecte en USB directement au Pi. Pour modifier son fonctionnement, veuillez le connecter à votre ordinateur et entrer en mode programmation :

- Appuyer sur le bouton RESET
- En restant appuyé, appuyer sur le potentiomètre
- Puis relâcher le bouton RESET
- Un répertoire devrait s'ouvrir sur l'ordinateur contenant des fichiers.

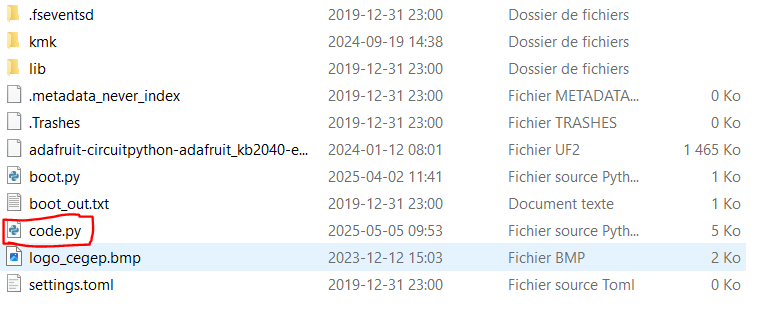
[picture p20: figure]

Figure 19 Répertoire du clavier esp32

Le fichier important est code.py qui peut être modifié selon les informations sur : https://github.com/KMKfw/kmk_firmware, mais vous pouvez prendre le code.py dans la section « \Code\Clavier ESP32 » du GitHub.

Voici la partie à modifier pour changer le fonctionnement des touches.

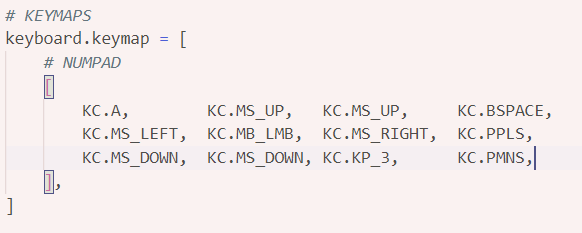
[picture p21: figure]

Figure 20 keymap du clavier esp32

## 7.5 Ajout d’un module esp32 en c++ :

Prenez un des CODE_ESP32_XYZ et modifier les éléments suivants selon vos besoins.

1. Choisir une adresse I2C unique au esp32.
2. Associer les pattes et le noms des esp32 à vos éléments interactifs et initialiser les entrée des esp32.

La liste des pattes des éléments interactifs.

L’initialisation des éléments interactifs en entrée.

3. Dans « loop() », récolter les données de vos éléments interactifs.

Dans le cas d’un élément interactif avec une sortie digital :

Dans le cas d’un élément interactif avec un sortie analogue :

Il est possible que la récolte de donnée soit plus complexe, comme avec notre module esp32 de bornes bananes qui détecte l’interconnexion entre chaque bornes:

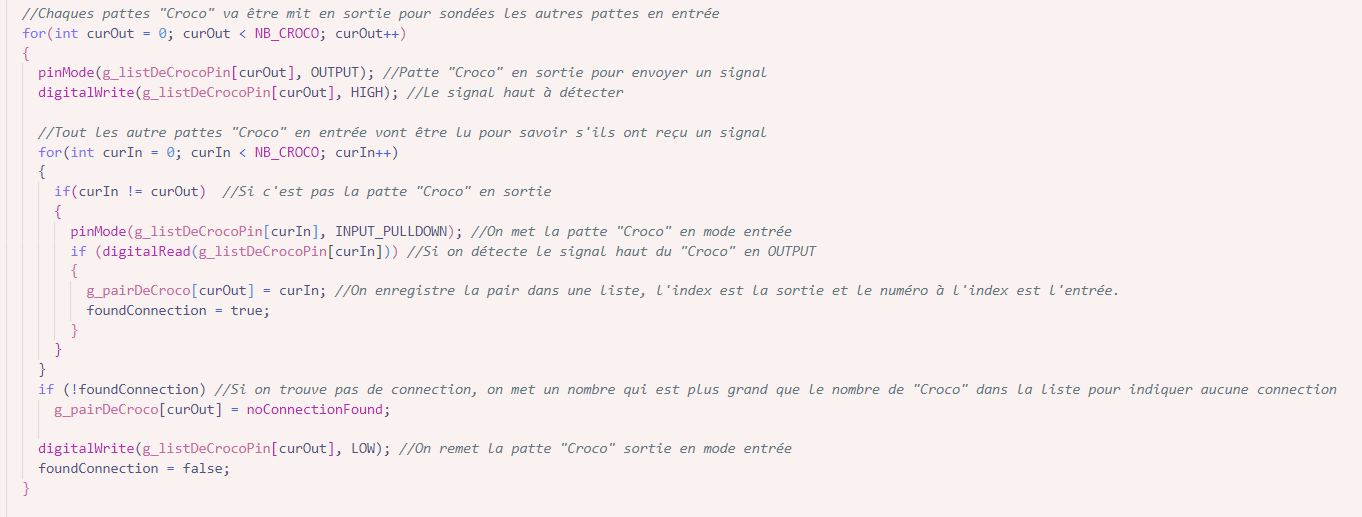
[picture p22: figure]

L’important est de mettre les données dans une liste ordonné pour la prochaine étape

4. Mettre les données dans un JSON :

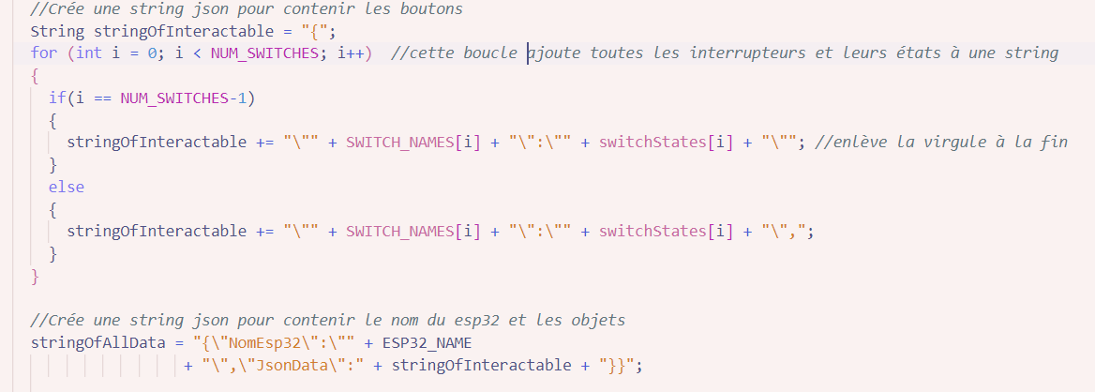
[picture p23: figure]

Noter que le JSON ne doit pas dépasser 125 caractères,

Dans ce cas, le JSON résultant est :

{ «NomEsp32 »: « I2C _SW », « JsonData » : {« SW1 »: « 0 » , « SW2 »: « 0 » … « SW8 : « 0 » } }

Votre JSON doit suivre la même logique :

{ «NomEsp32 »: NOM_DU_ESP32 « JsonData » : { NOM_DE_L’ÉLÉMENT : VALEUR_EN STRING, …} }

## 7.6 Création d’une énigme en python :

Nos énigmes sont mises dans des classe pour faciliter leurs intégrations

Voici un schéma simplifié d’une classe énigme :

Figure 21 Schéma simplifié d'une énigme

La première étape de chaque énigme est d’ouvrir une fenêtre d’interface utilisateur, avec PySimpleGUI dans notre cas, pour afficher l’énigme.

La deuxième étape est de faire la communication i2c entre le Pi et le esp32 correspondant à l’énigme. Vous pourriez faire des requêtes pour plus qu’un esp32 si votre énigme demande plusieurs éléments interactifs différents.

Noter que vous devez avoir un système de prévention d’exception sinon une mauvaise communication i2c va faire planter le code.

Finalement, vous devez intégrer les états des objets interactifs dans une énigme. Vous pouvez vous inspirer de nos énigmes dans le GitHub.

Si vous voulez continuer avec PySimpleGUI, nous vous conseillons de lire le PySimpleGUI cookbook pour mieux comprendre comment cette librairie fonctionne.

https://docs.pysimplegui.com/en/latest/cookbook/original/

## 7.7 Ajout d’une énigme en python :

Maintenant que la classe contenant l’énigme est créé, il faut l’importer dans main.py avec la ligne « from NOM_DU_MODULE import NOM_DE_LA_CLASSE » au début du fichier.

Premièrement, initialiser votre classe dans le main avec les paramètres nécessaires, exemple :

my_Croco = Croco(SLAVE_ADDRESS_Croco, LIST_OPERATIVE, DEBUG, strip1)

Deuxièmement, ajouter un « sg.Button("NOM_DE_L’ÉNIGME") » dans le « layout_winSelect », cela rajoute un événement qui permettra de démarrer votre énigme.

Troisièmement, ajouter un événement après :

qui démarre votre énigme lorsque le bouton est appuyé. Exemple :

Et un événement qui détecte que la fenêtre a été fermé.

# 8 Listes de matériel et coûts :

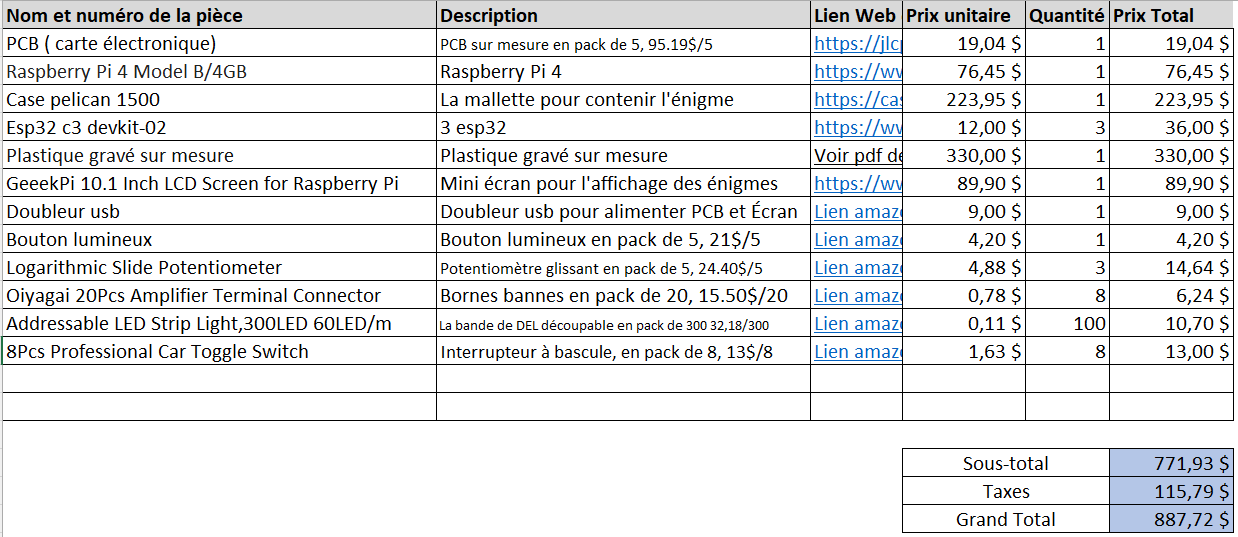
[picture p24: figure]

Figure 22 : Liste des coût de la mallette

Le fichier excel est dans le répertoire \Documentation\Manuel_Technique du GitHub.

# 9 Modifications et améliorations :

## 9.1 Modification :

Pour faire fonctionner la v1, il faut faire les modification suivante :

Percer un trou dans les points de montage du port USB-C.

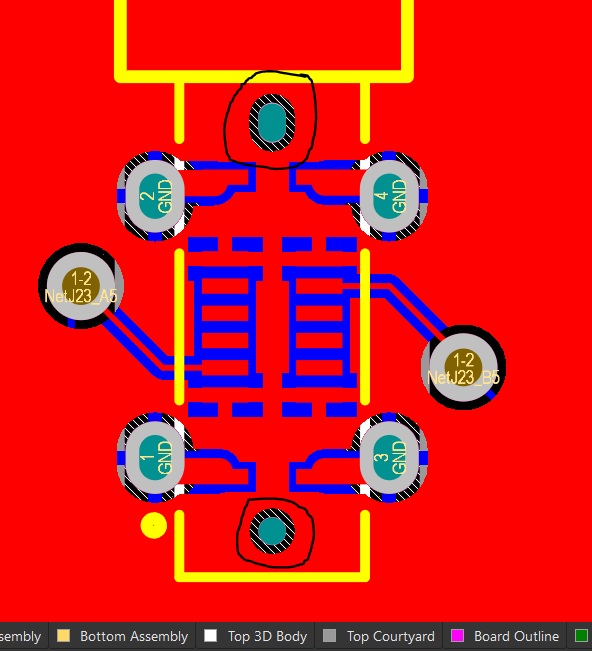
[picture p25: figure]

Souder des fils entre les pattes GPIO 9 et 0, les pattes GPIO 8 et 1, les pattes GPIO 5 et 2 du esp32 des potentiomètres.

## 9.2 Amélioration :

Ajouter une dead zone autour des points de montage du port USB-C, car il cause un court-circuit.

Spécifier au fabricant d'ajouter l'espace vide dans le PCB pour servir de poignée ergonomique.

Les patte GPIO 9, GPIO 8 et GPIO 5 du esp32 POT devrait être au gpio0, gpio1 et gpio2 car ces pattes ont un port analogue.

Changer le connecteur USB-C surface mount pour un câble plus facile à souder.

Les GPIO 12 et 18 tout comme 13 et 19, partage le même PWM, ce qui provoque que les bandes de DEL vont avoir exactement le même signal. Il est donc uniquement possible d'avoir 3 bandes de DEL différentes en même temps.

Il serait plus simple d’utiliser une seule bande de DEL adressable au lieu de 4.

Le pi n'a pas assez de courant pour alimenter tous et l'écran avec les ports USB-C du pi, il faut donc ajouter un dédoubleur de fils USB-C pour alimenter le mini écran directement avec la prise mural.

Les l’identification des résistance sur le silkscreen des SW ne sont pas dans le bon ordre, ils sont dans l'ordre 2,1,4,3,6,5,8,7 au lieu de 1,2,3,4,5,6,7,8.

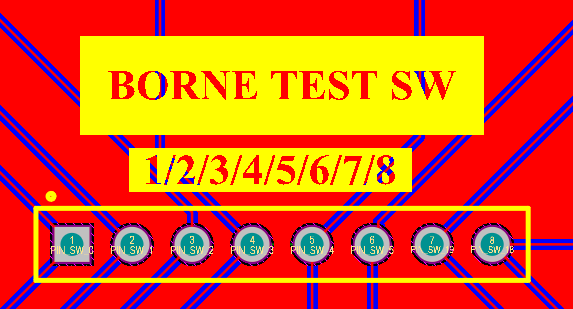
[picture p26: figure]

Figure 23 Ordre corrigé des pattes du connecteur JST

# 11 Annexe

## 11.1 Schéma

La clé du savoir Manuel Technique

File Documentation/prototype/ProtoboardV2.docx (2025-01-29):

Documentation Protoboard Version 2


# Alimentation du circuit :

## Alimentation Raspberry Pi :

- Pour ce qui est de l’alimentation du Raspberry Pi, il a été décidé qu’il sera alimenté par son port USB-C

## Alimentation circuits :

- L’alimentation du circuit sera alimentée à l’externe via leur PIN 5V, leur connecteurs USB standard seront accessible uniquement pour la programmation des ESP32-C3-Devkit-2.

## Alimentation Clavier numérique :

- Je n’ai personnellement pas assez d’information sur ce module présentement, donc j’estime qu’il sera alimenté par son port USB-C aussi

# Usage des ESP32 :


## ESP32 Orange :

Le ESP32 dans le rectangle Orange est celui qui va s’occuper de l’énigme des potentiomètres coulissant. L’énigme devrait marcher comme ceci : l’utilisateur glisse les potentiomètres jusqu’à une certaine valeurs, puis appuie sur le bouton (à ajouter) pour confirmer leurs choix.

GPIO utilisé:

- GPIO 4 (fil bleu) et 5 (fil mauve) sont présentement utilisé pour le « même » potentiomètre
- GPIO (non définit) est présentement utilisé pour le bouton

## ESP32 Vert :

Le ESP32 dans le rectangle Vert est celui qui va s’occuper de l’énigme des fils bananes. L’énigme devrait marcher comme ceci : l’utilisateur branche des bornes ensembles grâce à des fils bananes, puis le ESP32 va ensuite vérifier les fils associés avant de le comparé avec sa solution.

GPIO utilisé:

- GPIO 9 est le fil de couleur brun qui est brancher à la borne rouge
- GPIO 8 est le fil de couleur gris qui est brancher à la borne Jaune
- GPIO 5 est le fil de couleur mauve qui est brancher à la borne noire
- GPIO 4 est le fil de couleur bleu qui est brancher à la borne verte

## ESP32 Rose :

Le ESP32 dans le rectangle Rose est celui qui va s’occuper de l’énigme des interrupteurs. L’énigme devrait marcher comme ceci : l’utilisateur change les états des interrupteurs jusqu’à une certaine valeurs, puis appuie sur le bouton (à ajouter) lorsqu’il est certain de sa réponse.

GPIO utilisé:

- GPIO 19 est le fil orange
- GPIO 18 est le fil gris sur l’interrupteur jaune
- GPIO 9 est le fil Jaune
- GPIO 8 est le fil gris sur l’interrupteur noir
- GPIO 5 est le fil mauve
- GPIO 4 est le fil bleu
- GPIO 3 est le fil brun
- GPIO 2 est le fil vert
- GPIO 1 n’est pas encore définit
- PIN 0 n’est pas encore définit (probablement bouton)

# Communication I2C


La communication I2C sur le Raspberry Pi sera par les pins suivantes :

- SDA orange (Pi: GPIO2 pin3 ESP32: GPIO 7 couleur jaune)
- SCL rouge (Pi: GPIO3 pin5 ESP32: GPIO 6 couleur vert)

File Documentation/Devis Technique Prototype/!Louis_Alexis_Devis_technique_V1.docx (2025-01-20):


Louis Boisvert

Alexis Letourneau

Groupe : 2317

Devis technique du projet

de jeu d’évasion pédagogique

Devis technique présenté à :

Benoit Beaulieu

Département du génie électrique

Pour le cours

Planification de projet

Cégep de Sherbrooke

2024-12-09

## Mise en situation

InXtremis est un centre d'évasion situé au cœur du centre-ville de Sherbrooke, dirigé par un ancien étudiant en Technologie des Systèmes Ordinés (TSO). Le propriétaire aspire à concevoir une nouvelle salle intégrant des éléments interactifs grâce à des dispositifs électroniques dissimulés dans les énigmes. Plusieurs de ses salles actuelles utilisent déjà un ou deux dispositifs électroniques permettant d'ouvrir des portes et de suivre le progrès des joueurs. Cependant, il souhaite aller encore plus loin en créant une salle entièrement interconnectée, sans cadenas pour rythmer la progression.

Si les mécanismes simples, comme l'ouverture d'une énigme après la résolution de la précédente, sont faciles à mettre en place, le propriétaire ambitionne d'offrir une expérience encore plus impressionnante avec une énigme finale particulièrement spectaculaire. Pour concrétiser cette vision, il fait appel aux finissants du programme TSO.

L'objectif est de concevoir un module sous la forme d’une mallette renfermant une série de quatre énigmes. Le temps nécessaire pour résoudre ces énigmes devra être compris entre 5 et 10 minutes. Le module devra également offrir une remise en état quasi-instantanée (temps de réinitialisation de 5 à 10 secondes) pour accueillir rapidement la prochaine équipe.

La mallette devra être robuste pour résister à une mauvaise manipulation ou à une utilisation intensive. Le circuit électronique devra être facilement accessible pour les interventions de maintenance, de dépannage ou de démonstration. De plus, il devra pouvoir communiquer avec les autres éléments de la salle pour suivre la progression des joueurs et détecter des problèmes éventuels, comme la tentative de contourner une énigme.

## Schéma synoptique


Figure 1 : Schéma synoptique

Le projet consiste à développer une mallette interactive contenant 4 à 6 énigmes, dotée d’un écran et d’un temps de réinitialisation réduit à moins de 5 secondes. Si l'idée semble simple en théorie, sa réalisation pratique demande une intégration soignée des technologies embarquées. Chaque ESP32 doit être correctement alimentés et capable de communiquer via le protocole I2C avec un Raspberry Pi, qui centralise les informations et affiche ces informations sur une interface usagée. Le Raspberry Pi analyse les données reçues des ESP32 et les transmet à une base de données SQLite via MQTT, permettant un suivi précis de la progression des joueurs dans les énigmes. Cette architecture garantit une expérience fluide tout en offrant un système robuste et réactif. Voici leurs fonctionnalités plus en détail :

Rôles des Esp32 :

- Chaque ESP32 reçoit les actions que l’utilisateurs effectues sur sa propre énigme. Donc l’état des boutons, des interrupteurs et les valeurs des potentiomètres.
- Les ESP32 utilises une communication I2c pour envoyer leurs données au Raspberry Pi, dans ce type de communication, les ESP32 sont des « Sub» écoutant les demandes du Raspberry Pi.

Rôles du Raspberry Pi :

- Le PI est le « Main » dans la communication I2c et envoie des demandes d’informations au ESP32. Il reçoit un JSON comportant toutes les informations du ESP32 telle que son nom et l’état de ses capteurs.
- Le PI décrypte les JSON et établie son nombre d’essai, l’étape auquel il est rendu et si l’étape est réussie.

Écran :

- Interface usagée pour afficher les énigmes et l’état des capteurs, boutons et potentiomètre.
- Interface usagée peut aussi servir à offrir des indices, un message de fin et de début ainsi qu’une mise en situation.

Alimentation :

- Un bloc d’alimentation connecté au 120V ou 240V fournira une tension de 5V par USB-C au Raspberry Pi et à l’écran. Il sera possible de connecter un chargeur portatif au lieu de le brancher au mur lors de démonstration où les prises murales de 120V à 240V ne sont pas facilement accessibles.
- Les ESP32, seront alimentés par le Raspberry Pi

## Schéma électrique du prototype de jeu d’évasion


Figure 2 : Schéma électrique du prototype de jeu d’évasion

## Interface usagée


Figure 3 : affichages des pièces physiques

L’interface usagée que l’on va utiliser pour le déverminage et les tests va ressembler à celle-ci. Chaque fenêtre comportera les informations d’une énigme. Par exemple dans la figure 3, il est montré 2 énigmes. La première est une qui possède 2 interrupteurs et 3 potentiomètres ce qui est démontré par une image possédant 2 états et des barres se remplissant selon les valeurs actuelles des potentiomètres. Dans ce cas, ce qui serait montré à l’usager serait une onde sinusoïdale où les interrupteurs effectueraient un grand décalage et déphasage fixe, tandis que les potentiomètres permettraient d’effectuer des changements plus minces sur l’amplitude, le décalage et le déphasage.

## Échéancier


Figure 5 : Échéancier

## Évaluation des coûts


Figure 6 : Coûts

Jeux d’évasion devis technique

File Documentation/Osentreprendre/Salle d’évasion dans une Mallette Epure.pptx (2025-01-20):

## Salle d’évasion dans une Mallette

Par Alexis Létourneau et Louis Boisvert

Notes: Louis

## Résumé du projet

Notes: -Louis

## Notre client

- La compagnie de salle d’évasion inXtremis
- Compagnie locale ici à Sherbrooke
- Étienne Desbiens, le patron est un ancien de TSO
- En partenariat avec Benoit Beaulieu et Louis-Philippe Gauthier


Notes: Louis

## Le projet


- Une mallette qui contient l’équivalent d’une salle d’évasion.
- Portable
- Modulaire
- Qui marche à batterie
- Similaire à ceux en ligne mais avec un écran

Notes: Louis

## Le prototype


- Présentement avec deux modules énigmes
- Le esp32 communique ses prises de données en i2c au PI
- Le PI communique cette prise de donnée en MQTT pour la collecte de données
- Le PI affiche ces données avec un interface PySimpleGUI
- Un ordinateur reçoit les données MQTT, ajoute des données utiles et le met dans une base de données SQL
- On peut voir ces données avec Grafana

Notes: Louis

## Interface PySimpleGUI


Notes: Louis

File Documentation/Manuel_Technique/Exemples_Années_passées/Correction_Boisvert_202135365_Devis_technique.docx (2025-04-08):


Louis Boisvert

Alexis Letourneau

Groupe : 2317

Devis technique du projet

de jeu d’évasion pédagogique

Devis technique présenté à :

Benoit Beaulieu

Département du génie électrique

Pour le cours

Planification de projet

Cégep de Sherbrooke

2024-12-09

Présentation, propreté, mise en page (respect des normes méthodologiques, numérotation, images, alignement, page titre, table des matières, etc.) | 4,5 | 5
Qualité de l'expression française (orthographe, structure de l'écriture, cohérence de l'écriture) | 8 | 10
Mise en contexte | 10 | 10
Schéma synoptique et explications | 33 | 35
Schéma électrique | 5 | 5
Interface usagé | 13 | 15
Échéancier | 8 | 10
Évaluation des coûts | 9 | 10
Total: | 90,5 | 100

## Mise en situation

InXtremis est un centre d'évasion situé au cœur du centre-ville de Sherbrooke, dirigé par un ancien étudiant en Technologie des Systèmes Ordinés (TSO). Le propriétaire aspire à concevoir une nouvelle salle intégrant des éléments interactifs grâce à des dispositifs électroniques dissimulés dans les énigmes. Plusieurs de ses salles actuelles utilisent déjà un ou deux dispositifs électroniques permettant d'ouvrir des portes et de suivre le progrès des joueurs. Cependant, il souhaite aller encore plus loin en créant une salle entièrement interconnectée, sans cadenas pour rythmer la progression.

Si les mécanismes simples, comme l'ouverture d'une énigme après la résolution de la précédente, sont faciles à mettre en place, le propriétaire ambitionne d'offrir une expérience encore plus impressionnante avec une énigme finale particulièrement spectaculaire. Pour concrétiser cette vision, il fait appel aux finissants du programme TSO.

L'objectif est de concevoir un module sous la forme d’une mallette renfermant une série de quatre énigmes. Le temps nécessaire pour résoudre ces énigmes devra être compris entre 5 et 10 minutes. Le module devra également offrir une remise en état quasi-instantanée (temps de réinitialisation de 5 à 10 secondes) pour accueillir rapidement la prochaine équipe.

La mallette devra être robuste pour résister à une mauvaise manipulation ou à une utilisation intensive. Le circuit électronique devra être facilement accessible pour les interventions de maintenance, de dépannage ou de démonstration. De plus, il devra pouvoir communiquer avec les autres éléments de la salle pour suivre la progression des joueurs et détecter des problèmes éventuels, comme la tentative de contourner une énigme.

## Schéma synoptique


Figure 1 : Schéma synoptique

Le projet consiste à développer une mallette interactive contenant 4 à 6 énigmes, dotée d’un écran et d’un temps de réinitialisation réduit à moins de 5 secondes. Si l'idée semble simple en théorie, sa réalisation pratique demande une intégration soignée des technologies embarquées. Chaque ESP32 doit être correctement alimentés et capable de communiquer via le protocole I2C avec un Raspberry Pi, qui centralise les informations et affiche ces informations sur un interface usagé. Le Raspberry Pi analyse les données reçues des ESP32 et les transmettent à une base de données SQLite via MQTT, permettant un suivi précis de la progression des joueurs dans les énigmes. Cette architecture garantit une expérience fluide tout en offrant un système robuste et réactif. Voici leurs fonctionnalités plus en détail :

Rôles des Esp32 :

- Chaque ESP32 reçoit les actions que l’utilisateurs effectues sur sa propre énigme. Donc l’état des boutons, des interrupteurs et les valeurs des potentiomètres.
- Les ESP32 utilises une communication I2c pour envoyer leurs données au Raspberry Pi, dans ce type de communication, les ESP32 sont des « Sub» écoutant les demandes du Raspberry Pi.

Rôles du Raspberry Pi :

- Le PI est le « Main » dans la communication I2c et envoie des demandes d’informations au ESP32. Il reçoit un JSON comportant toutes les informations du ESP32 telle que son nom et l’état de ses capteurs.
- Le PI décrypte les JSON et établie son nombre d’essai, l’étape auquel il est rendu et si l’étape est réussie.

Écran :

- Interface usagée pour afficher les énigmes et l’état des capteurs, boutons et potentiomètre.
- Interface usagée peut aussi servir à offrir des indices, un message de fin et de début ainsi qu’une mise en situation.

Alimentation :

- Un bloc d’alimentation connecté au 120V ou 240V fournira une tension de 5V par USB-C au Raspberry Pi et à l’écran. Il sera possible de connecter un chargeur portatif au lieu de le brancher au mur lors de démonstration où les prises murales de 120V à 240V ne sont pas facilement accessibles.
- Les ESP32, seront alimentés par le Raspberry Pi

## Schéma électrique du prototype de jeu d’évasion


Figure 2 : Schéma électrique du prototype de jeu d’évasion

## Interface usagée


Figure 3 : affichages des pièces physiques

L’interface usagée que l’on va utiliser pour le déverminage et les tests va ressembler à celle-ci. Chaque fenêtre comportera les informations d’une énigme. Par exemple dans la figure 3, il est montré 2 énigmes. La première est une qui possède 2 interrupteurs et 3 potentiomètres ce qui est démontré par une image possédant 2 états et des barres se remplissant selon les valeurs actuelles des potentiomètres. Dans ce cas, ce qui serait montré à l’usager serait une onde sinusoïdale où les interrupteurs effectueraient un grand décalage et déphasage fixe, tandis que les potentiomètres permettraient d’effectuer des changements plus minces sur l’amplitude, le décalage et le déphasage.

## Échéancier


Figure 5 : Échéancier

## Évaluation des coûts


Figure 6 : Coûts

Jeux d’évasion devis technique

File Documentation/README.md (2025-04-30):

# Collection des Documentations Pertinentes  

Les fichiers présents dans ce dossier ne contiennent pas de code, mais restent des éléments importants pour la poursuite du projet.  

## 📂 Osentreprendre  
Ce dossier regroupe les documents nécessaires pour soumettre notre participation à la compétition **Osentreprendre**.  
Il contient principalement des fichiers texte décrivant les raisons pour lesquelles nous avons choisi de réaliser ce projet.  

---
## 📂 Devis Technique Prototype
Ce dossier contient : 
    - Le devis technique est le plan de base que nous avons suivi pour faire le projet. 

## 📂 Fiche technique 
Ce dossier contient : 
    - Une collection de fichier technique pour les composants de la mallette.

## 📂 Manuel_Technique
Ce dossier contient :  
    - Le manuel technique contient les informations pertinent pour le fonctionnment et la continuation du projet.

## 📂 Prototype  
Ce dossier contient :  
- Des images illustrant les débuts du projet.  
- Certaines idées initiales qui n’ont pas été retenues dans les versions ultérieures du prototype.  

---

### 🛠️ Notes  
Bien que ces dossiers ne soient pas essentiels au fonctionnement technique du projet, ils seront précieux pour les rapports finaux et la documentation du processus.

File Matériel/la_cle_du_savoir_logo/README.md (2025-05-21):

# Environnement de travail du logo
Fait par: Alexis Desainde

Liens vers sont portfoillo: https://www.behance.net/alexisdesainde
---

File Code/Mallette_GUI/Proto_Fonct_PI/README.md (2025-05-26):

# Dossier de Tests pour le Prototype Modulable  

Ce dossier contient les fichiers de code python pour faire fonctionner les énigmes de la mallette avec la librairie PySimpleGUI. 
Pour faire fonctionner le programme, il faut activer l'application de programmation python 'thonny' en mode sudo avec la commande 'sudo thonny', puis faire rouler le fichier 'main.py'. 
Le fichier 'main.py' dépend des librairies dans l'environnement virtuel de 'venv'.

Voici comment créer cette environnement virtuel et ajouter les librairies:

Créer un environnement virtuel avec la commande 'python3 -m venv path/to/venv.'
Activé l'environnement virtuel avec la commande 'source .venv/bin/activate' dans CMD
Ajouter une librairie à l'environnement virtuel avec la commande 'python3 -m pip install XYZ' dans CMD (XYZ est la librairie désiré)
Répéter la commande précédente avec la liste de librairie suivante :

'smbus2'

'rpi_ws281x'

'Adafruit-Blinka'

pour l'installation de la dernière version de PysimpleGUI : 'python -m pip install --upgrade --extra-index-url https://PysimpleGUI.net/install PySimpleGUI'

Le reste des import du main.py est des librairie de base ou des librairie fait par nous.
Voici la liste des librairies custom qui faut mettre dans le même répertoire de main.py :
'moduleDEL'
'Class_Croco'
'Class_SW'
'Class_POT'
'MazeModule'

# Contient
- 'venv' l'environnement virtuel
- 'Class_Croco.py' le module d'énigme d'équation
- 'Class_SW.py' le module d'affichage de l'état des switches
- 'Class_POT.py' le module d'énigme de sine wave
- 'I2c_COMM.py' le module de communication i2c entre le pi et le esp32
- 'main.py' le programme principale (On choisit les différentes fenêtres d'énigmes comme on veut (avec la souris)
- 'suiteEnigmes.py' programme principale de la démo finale lors de l'Expotech.
- 'MazeModule.py' le module d'énigme du labyrinthe (NON FONCTIONNEL)
- 'moduleDEL.py' le module de controle des DEL
- 'monautostart.desktop' fichier qui permet l'ouverture du programme lors du boot, doit être placé dans /etc/xdg/autostart/
- 'README.md'

# Création d'un fichier exécutable
Activer votre environnement virtuel si ce n'est pas déjà fait :

'source path/to/venv/bin/activate'

Assurez-vous que votre environnement virtuel est à jour :

'sudo apt update'
'sudo apt install python3-venv'

Essayez d’installer PyInstaller :

'pip install -U pyinstaller'

Installer les bibliothèques nécessaires :

- 'pip install zmq flask requests'
- 'pip install paho-mqtt'
- 'pip install pyzmq'

Créer l'exécutable pour chacun des programmes que vous voulez compiler :

- 'pyinstaller --onefile mon_programme.py'

Note 1 : Si vous avez oublié d’ajouter une librairie, il suffit de l’installer puis de relancer la commande pyinstaller --onefile.

Note 2 : il est à noter qu'après que le fichier exécutable soit créer, il peut être placer à n'importe quel endroit et encore être fonctionnel. Ceci peut aider si les chemins sont trop longs.

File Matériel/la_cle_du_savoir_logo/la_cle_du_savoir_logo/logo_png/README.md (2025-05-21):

# logo_png
ce dossier comprend deux formats supplémentaires, cmjn et rvb.
- cmjn (fichier pnj idéale pour la production)
- rvb (fichier pnj pour afficher à l'écran)

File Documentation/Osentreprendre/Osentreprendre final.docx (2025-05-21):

InXtremis est un centre de salle d’évasion situé au centre-ville de Sherbrooke, dont le propriétaire est un ancien de technique de Technologie en Système Ordiné (TSO). Il cherche à créer une nouvelle salle avec des éléments interactifs à l’aide d’électronique cachés dans ses énigmes. Plusieurs de ses salles utilisent déjà une ou deux éléments électronique qui lui permette d’ouvrir des portes et de suivre le progrès de ses joueurs. Cependant, il désire pousser cette vision jusqu’au bout avec une salle qui est complétement interconnecté sans cadenas pour dicter la progression. Les éléments les plus simples comme ouvrir une énigme après que la précédente fut complété est simple, mais pour une énigme finale particulièrement épatante, le propriétaire cherche l’aide des finissant en TSO.

Notre équipe est composée de deux étudiants finissant en TSO qui veulent fournir le propriétaire d’inXtremis une mallette contenant un écran et différentes petites énigmes modulaires selon les besoins du client. Cette mallette servira de point culminant à la salle d’évasion en utilisant un mixte entre l’électronique et les éléments réels de la salle.

Dans un premier temps, nous développons un prototype avec les éléments hors de la mallette pour tester les différentes fonctionnalités et améliorer l’expérience des joueurs. Le but est de peaufiner les problèmes qui pourraient sur survenir avant de créer le système complet de la mallette. En plus, nous voulons rajouter un système de récolte de donnée pour chaque interaction de la mallette. Cela permettra de collecter le temps moyen de résolution des énigmes et quels boutons ont été appuyés dans le but de déterminer la difficulté des énigmes.

Par ailleurs, l’écran nous sert d’interface graphique pour bonifier l’expérience des joueurs et du client. L’écran permet ainsi de faciliter le débogage lors de panne et en facilitant la programmation pour changer les énigmes selon les besoins du client.

De plus, la modularité de la mallette permet la réparation et la modification de la mallette. Les différentes énigmes seront dans des caisses rectangulaires imprimées en 3D et pourront être insérées et enlevées librement, que ce soit pour remplacer une énigme brisée ou remplacée une énigme complètement.

Ensuite, la mallette au complet est complétement libre d’accès pour le client. Le hardware des énigmes ainsi que leurs programmations peuvent être changé sans problème. La mallette appartient complétement au client.

Parallèlement, nous pouvons aller plus loin avec la mallette. Nos professeurs de TSO veulent intégrer un côté d’apprentissage actif dans leur cours avec l’introduction de la mallette et d’énigme personnalisé selon le cours. Un cours d’interface pourrait simuler une panne de site web, un cours de réseautique pourrait simuler des problèmes de communication entre deux appareils, etc.

Il y a beaucoup de « mallettes d’évasion » sur le marché, mais 4 éléments nous distinguent des compétiteurs. L’interface graphique que procure l’écran, la collecte de données pour une meilleure gestion, la modularité des énigmes et le libre d’accès de la mallette, tout ça dans un emballage compact et durable. La plupart des autres « mallettes d’évasions » sur le marché contiennent une seule série d’énigme inchangeable, n’incluent pas d’écran et sont généralement juste une série de documents papier. Notre mallette permet une infinité d’énigmes ainsi qu’une fusion du monde électronique et du monde réel de la salle d’évasion.

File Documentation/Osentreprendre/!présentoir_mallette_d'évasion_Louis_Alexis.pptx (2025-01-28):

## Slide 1


Malette d’évasion

- Un jeu d’évasion modulable à but pédagogique

Louis
Boisvert


Alexis Letourneau


Clavier


Microcontrôleur


victoire


Interrupteur


En collaboration avec :


potentiomètre


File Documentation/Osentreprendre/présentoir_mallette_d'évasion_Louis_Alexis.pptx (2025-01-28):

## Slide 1


Malette d’évasion

- Un jeu d’évasion modulable à but pédagogique

Louis
Boisvert


Alexis Letourneau


Énigmes


Microcontrôleur


victoire


En collaboration avec :


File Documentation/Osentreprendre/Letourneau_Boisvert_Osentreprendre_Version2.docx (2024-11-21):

Alexis Létourneau et Louis Boisvert : Un jeu d’évasion Pédagogique

InXtremis est un centre de salle d’évasion situé au centre-ville de Sherbrooke, dont le propriétaire est un finissant de la technique de Technologie de Systèmes Ordinés (TSO). Nous lui avons demandés de l’aide pour la conception des énigmes dans l’objectif de créer un module de jeux d’évasion pédagogique. En effet, des professeurs de génie électrique désirs un jeu d’évasion modulaire pouvant servir à l’apprentissage, à des buts publicitaires et à la création d’une nouvelle salle chez InXtremis. Ce défit de taille est ce qui nous as fait choisir ce projet pour conclure nos études dans le programme.

Notre équipe est composée de deux étudiants finissant en TSO qui veulent fournir au propriétaire d’inXtremis et au département de génie électrique, une mallette contenant un écran montrant la question à une énigme, une horloge montrant le temps restant et différentes petites énigmes modulaires selon les besoins du client ou du cours. Cette mallette servira de point culminant à la salle d’évasion D’InXtremis en utilisant un mixte entre l’électronique et les éléments réels de la salle. Aussi, elle permettra d’attirer l’attention sur le programme lors des portes ouvertes et de matériel pédagogique offrant de la pratique dans la théorie

Commençons par l’utilisations de la mallette dans un objectif pédagogique. Soyez honnête, qui n’a jamais eu envie de dormir lors d’un cours tôt le matin où la seule action présente est les monotones paroles d’un enseignant? Maintenant imaginé si votre cours était remplacé par un jeu d’évasion où vous êtes en compétition avec le temps d’une autre classe, ne serait-ce pas merveilleux? Peut importe la matière, la mallette pourra être modifier pour respecter les critères voulus. Que ce soit les nombres complexes en mathématique, la modification de code pour les cours de programmation ou encore la réparation de système électrique pour les cours de dépannage de système ordiné.

Ensuite, l’utilisation de la mallette en but publicitaire. La meilleure façon d’attirer l’intérêt d’autrui est de présenté un jeu au lieu d’un bout de papier. Donc pour des évènements tel que les portes ouvertes ou les présentations dans les écoles secondaires, apporter une mallette interactive, puis montrer son fonctionnement interne permettrait de remplir une partie de la curiosité de tous ceux qui ont déjà briser une calculatrice pour voir son fonctionnement.

Enfin, l’utilisation de la mallette pour les énigmes d’InXtremis peut apporter une nouvelle dimension à l’expérience des participants. L’idée est de proposer des énigmes qui ne se contentent pas d’être ludiques, mais qui demandent également des compétences en résolution de problèmes et en logique, tout en intégrant des éléments interactifs et technologiques. Par exemple, une énigme pourrait nécessiter de reprogrammer un microcontrôleur pour ouvrir une serrure, ou encore de déchiffrer un code binaire pour désactiver un piège fictif. Ces concepts ajoutent une profondeur supplémentaire, attirant une clientèle curieuse et passionnée par la technologie, tout en offrant une expérience unique qui se démarque des autres salles d’évasion traditionnelles.

En conclusion, Ce projet de mallette d’évasion pédagogique et publicitaire représente une convergence réussie entre l’éducation, la technologie et le divertissement. Grâce à la collaboration entre notre équipe et InXtremis, nous avons pu concevoir une solution innovante, à la fois utile et captivante, qui répond aux besoins variés des enseignants, des étudiants et des amateurs de salles d’évasion. Nous espérons que cette initiative inspirera d’autres projets similaires et continuera de démontrer comment la technologie peut être utilisée pour transformer des expériences éducatives en moments mémorables et enrichissants.

Correction : 15/20

De l’idée au projet : L’histoire ou le projet se démarque. Le projet est clairement défini et vise à répondre avec pertinence à un besoin ou un enjeu d’une (ou de) clientèle(s) distincte(s) des personnes qui initient le projet.

3536 caractères / 4000 permis

3839 caractères / 4000 permis

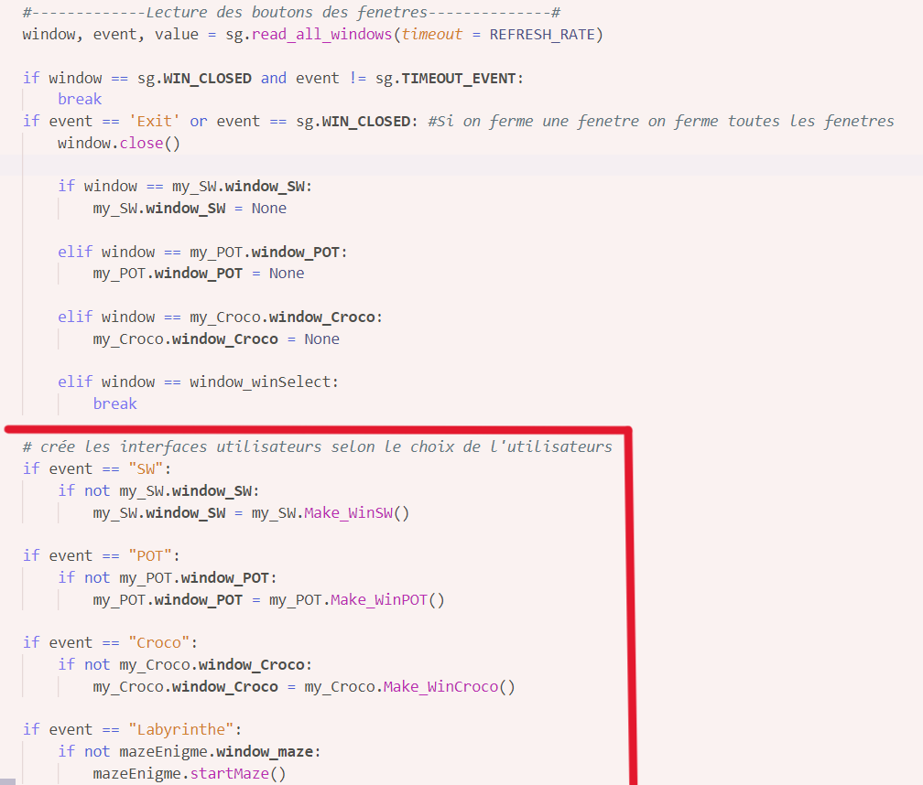
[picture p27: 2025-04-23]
Documentation/Manuel_Technique/mallette PIC/windowManagementCreateWindow.PNG

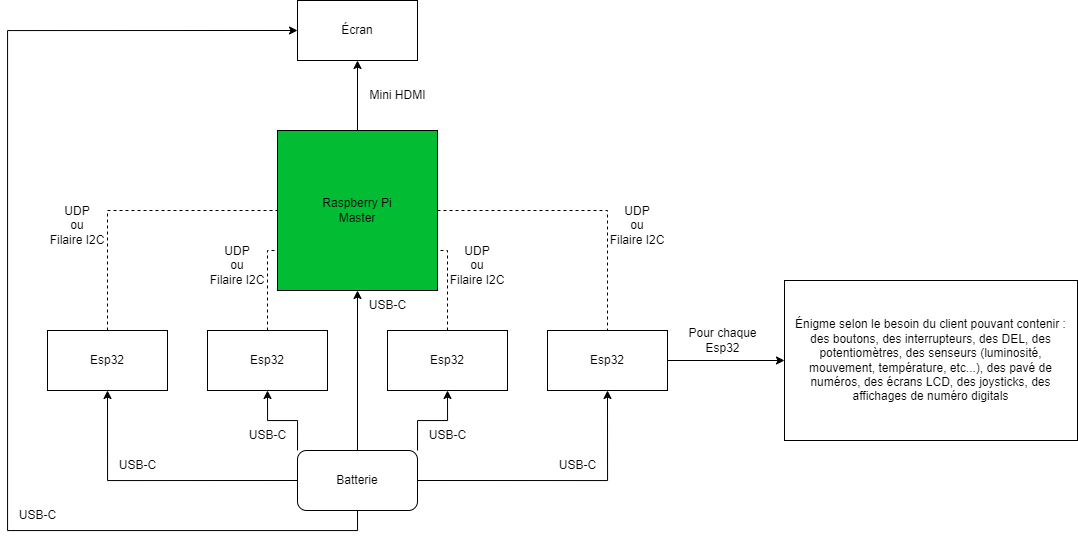
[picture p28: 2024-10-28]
Documentation/prototype/Schema du prototype.png

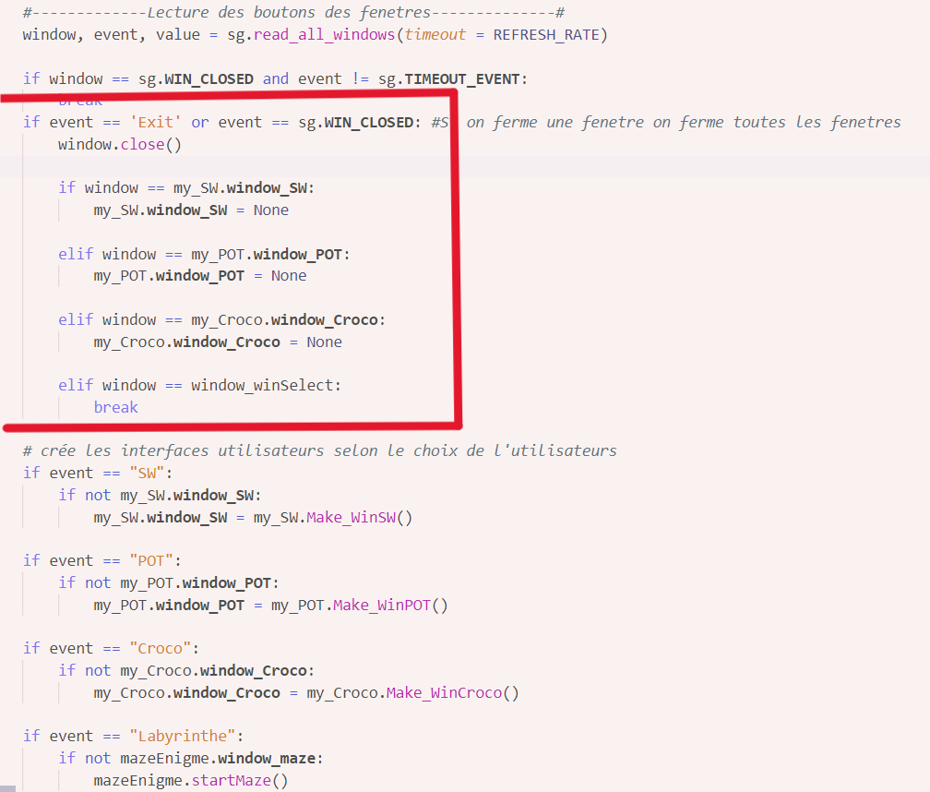
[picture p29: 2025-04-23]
Documentation/Manuel_Technique/mallette PIC/windowManagementDeleteWin.PNG

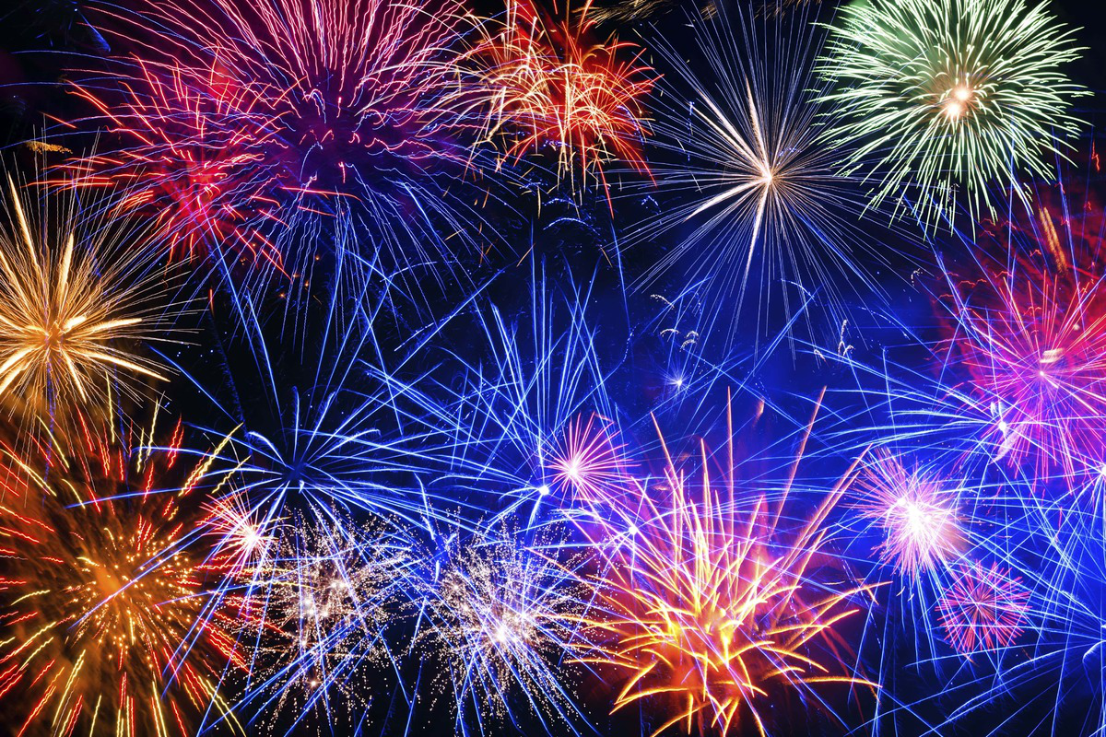
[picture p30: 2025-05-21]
Code/Mallette_GUI/Proto_Fonct_PI/Fireworks.png

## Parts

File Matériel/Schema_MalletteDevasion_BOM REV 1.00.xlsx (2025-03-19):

Designator | Description | Comment | Package / Case | Quantity | Layer | Supplier 1 | Supplier Part Number 1 | Note
C1, C2, C3 | CAP ALUM 100UF 20% 50V RADIAL | 100 µF | Radial, Can | 3 | Top | DigiKey | 732-8861-1-ND
C4 | CAP ALUM POLY 470UF 20% 25V T/H | 470 µF |  | 1 | Top | DigiKey | 399-A759MS477M1EAAE020-ND
C5, C6, C7 | CAP ALUM 0.1UF 10% 100V RADIAL | 0.1µF | Radial, Can | 3 | Top | DigiKey | 493-16876-ND
C8, C9, C10, C11 | ALUMINUM CAPACITOR | 0.1 uf |  | 4 | Top | DigiKey | 565-APSG160ELL152MH20S-ND
J1, J2, J3, J5, J6, J7, J8, J9 | CONN HEADER VERT 2POS 2.5MM | B2B-XH-A(LF)(SN) |  | 8 | Top
J4, J11 | CON - Header 1X8 pins, 100Mils - TH-8 | CON_HDR_1X8 |  | 2 | Top
J10, J12, J22, J24, J25, J26, J27, J28 | CONN HEADER VERT 4POS 2.5MM | B4B-XH-A(LF)(SN) |  | 8 | Top
J13, J14, J15, J17, J18, J20, J21 | CONN HEADER VERT 3POS 2.5MM | B3B-XH-A(LF)(SN) |  | 7 | Top | [NoParam], DigiKey | [NoParam], 455-2248-ND
J16 | CON - Header 1x3 pins-100Mils - TH | CON_HDR_1X3 |  | 1 | Top
J19 | CONN HEADER VERT 4POS 2.54MM | 0022272041 |  | 1 | Top
J23 | USB4120-03-C 16 Position 48 VDC USB Type C Vertical USB 2.0 Receptacle Connector | USB4120-03-C |  | 1 | Top
J29 |  | TSW-120-25-G-D |  | 1 | Top
Q1 | MOSFET N-CH 100V 9.7A TO-220AB | IRF520NPBF |  | 1 | Top
Q2, Q3, Q4, Q5 | Bus Driver, HC/UH Series, 1-Func, 1-Bit, True Output, CMOS, PDSO5 | 74HC1G125GV-Q100H |  | 4 | Top
R1, R2, R4, R5, R6, R7, R8, R9, | Resistor | Switch 10k |  | 8 | Top
R3, R10, R19 | Resistor | Reset 10k |  | 3 | Top
R11, R12, R13, R14, R15, R16, R17, R18 | Resistor | Banane 10k |  | 8 | Top
R20, R21, R24, R25 | Resistor | DEL 10k |  | 4 | Top
R26 | Resistor | Pull up SW 4,7k |  | 1 | Top
R27 | Resistor | Alim DEL 90ohm |  | 1 | Top
R28 | Resistor | Pull down 4,7k |  | 1 | Top
R22, R23 | Resistor | I2C 4,7k |  | 2 | Top
R29, R30 | Resistor | 5,1k |  | 2 | Top
U1, U2, U3 | Development Boards & Kits - Wireless (Engineering Samples) ESP32-C3 General-Purpose Development Board, embeds ESP32-C3-WROOM-02, 4 MB Flash, with Pin Header | ESP32-C3-DEVKITC-02 |  | 3 | Top

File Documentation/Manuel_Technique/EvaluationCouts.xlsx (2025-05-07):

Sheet: Liste
Nom et numéro de la pièce | Description | Lien Web chez le fournisseur | Prix unitaire | Quantité | Prix Total
PCB ( carte électronique) | PCB sur mesure en pack de 5, 95.19$/5 | https://jlcpcb.com/ | 19.04 $ | 1 | 19.04 $
Raspberry Pi 4 Model B/4GB | Raspberry Pi 4 | https://www.pishop.ca/product/raspberry-pi-4-model-b-4gb/ | 76.45 $ | 1 | 76.45 $
Case pelican 1500 | La mallette pour contenir l'énigme | https://caseplace.ca/products/pelican-1500-case | 223.95 $ | 1 | 223.95 $
Esp32 c3 devkit-02 | 3 esp32 | https://www.mouser.ca/ProductDetail/Espressif-Systems/ESP32-C3-DevKitC-02?qs=stqOd1AaK7%2F1Q62ysr4CMA%3D%3D | 12.00 $ | 3 | 36.00 $
Plastique gravé sur mesure | Plastique gravé sur mesure | Voir pdf de commision | 330.00 $ | 1 | 330.00 $
GeeekPi 10.1 Inch LCD Screen for Raspberry Pi | Mini écran pour l'affichage des énigmes | https://www.amazon.ca/-/fr/GeeekPi-Raspberry-moniteur-portable-gratuit/dp/B0CPLYD5GD?th=1 | 89.90 $ | 1 | 89.90 $
Doubleur usb | Doubleur usb pour alimenter PCB et Écran | Lien amazon (https://www.amazon.ca/Splitter-MOGOOD-Extension-Charging-Transfer/dp/B098L7WJ4C) | 9.00 $ | 1 | 9.00 $
Bouton lumineux | Bouton lumineux en pack de 5, 21$/5 | Lien amazon (https://www.amazon.ca/EG-STARTS-Illuminated-Buttons-Operated/dp/B01M7PNCO9) | 4.20 $ | 1 | 4.20 $
Logarithmic Slide Potentiometer | Potentiomètre glissant en pack de 5, 24.40$/5 | Lien amazon (https://www.amazon.ca/DAOKI-Logarithmic-Potentiometer-Arduino-Electronic/dp/B08SLPV4VD) | 4.88 $ | 3 | 14.64 $
Oiyagai 20Pcs Amplifier Terminal Connector | Bornes bannes en pack de 20, 15.50$/20 | Lien amazon (https://www.amazon.ca/Oiyagai-Amplifier-Terminal-Connector-Binding/dp/B07D3MMBJH) | 0.78 $ | 8 | 6.24 $
Addressable LED Strip Light,300LED 60LED/m | La bande de DEL découpable en pack de 300 32,18/300 | Lien amazon (https://www.amazon.ca/LOAMLIN-WS2812B-Individually-Addressable-Waterproof/dp/B09573HX4X) | 0.11 $ | 100 | 10.70 $
8Pcs Professional Car Toggle Switch | Interrupteur à bascule, en pack de 8, 13$/8 | Lien amazon (https://www.amazon.ca/FULARR-Professional-Toggle-Switch-Position/dp/B07M8WCTF5) | 1.62 $ | 8 | 13.00 $
 |  |  | Sous-total |  | 771.93 $
 |  |  | Taxes |  | 115.79 $
 |  |  | Grand Total |  | 887.72 $

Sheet: Infos
Les cellules en bleues doivent se calculer automatiquement (utiliser une formule).
Dans l'évaluation des coûts, ne pas oublier:
Les cartes de développements
Les PCB (prévoir 50$ comme frais de livraisons)
Les connecteurs
Les câbles ou fils si longues distances
Les boîtiers
Ne pas mettre les composants discrets (résistances, condensateurs, etc) de moins de $2.00

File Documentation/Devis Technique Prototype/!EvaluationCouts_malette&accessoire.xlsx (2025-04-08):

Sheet: Liste
Nom et numéro de la pièce | Description | Lien Web chez le fournisseur | Prix unitaire | Quantité | Transport | Total
pcb 2 couche | circuit imprimer | https://jlcpcb.com/?from=VGPCB2&utm_content&adgroupid&gad_source=1 | 18.80 $ | 2 | 24.94 | 62.54 $
910S-010SV-0A0 | mallette contenant le jeu d'évasion | https://nanukcases.ca/fr/products/nanuk-910?variant=38294651109557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 | 107.95 $ | 1 | 0 | 107.95 $
R16-503 | bouton lumineux | https://a.co/d/gLQzJxG | 60.50 $ | 1 | 5.54 | 66.04 $
DPDT 2 positions | Interrupteur | https://a.co/d/1r08j27 | 16.99 $ | 1 | 0 | 16.99 $
RV24YN20S | potentiomètre | https://a.co/d/3zwPCMx | 18.99 $ | 1 | 0 | 18.99 $
Lot de 32 connecteurs de fils à levier, assortiment de mini connecteurs électriques compacts pour 24-12 AWG | Borniers simples | https://a.co/d/gQmGtzr | 24.98 $ | 1 | 5.54 | 30.52 $
Module de carte de dérivation ultra-petit RPi GPIO LED et bornier pour Raspberry Pi | Borniers Raspberry Pi | https://a.co/d/j0eCrPj | 32.27 $ | 1 | 5.12 | 37.39 $
ESP32-C3-DevKitC-02 Development Board | ESP32 | https://a.co/d/2R5FRob | 8.00 $ | 1 | 10.52 | 18.52 $
Raspberry Pi 4 Model B/4GB | Raspberry Pi 4 | https://www.pishop.ca/product/raspberry-pi-4-model-b-4gb/ | 76.45 $ | 1 | 17.12 | 93.57 $
Écran tactile portable 7" HD 1024 x 600 - Petit moniteur double port HDMI - Mini moniteur pour Raspberry Pi ordinateur portable PC Xbox PS4/5 Switch haut-parleurs intégrés | Mini moniteur pour Raspberry Pi | https://a.co/d/8YKHyw0 | 78.99 $ | 1 | 0 | 78.99 $
 |  |  |  |  |  | 0.00 $
 |  |  | Sous-total |  |  | 531.50 $
 |  |  | Taxes |  |  | 79.59 $
 |  |  | Grand Total |  |  | 611.09 $

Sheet: Infos
Les cellules en bleues doivent se calculer automatiquement (utiliser une formule).
Dans l'évaluation des coûts, ne pas oublier:
Les cartes de développements
Les PCB (prévoir 50$ comme frais de livraisons)
Les connecteurs
Les câbles ou fils si longues distances
Les boîtiers
Ne pas mettre les composants discrets (résistances, condensateurs, etc) de moins de $2.00

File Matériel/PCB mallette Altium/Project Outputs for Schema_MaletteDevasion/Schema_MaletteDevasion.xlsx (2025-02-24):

Bill of Material
Board | Mallette d'évasion |  | Concepteur Principal |  | Louis Boisvert |  |  | 1
Cours | Cours: 247-67P-SH PROJET DE FIN D'ÉTUDES |  | Date du projet |  | 2025-01-30 |  |  | 00
Département | Technologies du génie électrique |  | Date de génération du BOM |  | 2025-02-22
Révision | 1.00 |  | Heure de génération du BOM |  | 14:28
Nombre de PCB | 1 |  | Variant |  | None
Item Number | Designator | #Column Name Error:' Layer | Description | Comment | Package / Case | Supplier 1 | Supplier Part Number 1 | Quantity | Quantity Total | Note
 | C1, C2, C3 |  | CAP ALUM 100UF 20% 50V RADIAL | 100 µF | Radial, Can | DigiKey | 732-8861-1-ND | 3 | 3
 | C5, C6, C7 |  | CAP ALUM 0.1UF 10% 100V RADIAL | 0.1µF | Radial, Can | DigiKey | 493-16876-ND | 3 | 3
 | J1, J2, J3, J5, J6, J7, J8, J9 |  | CONN HEADER VERT 2POS 2.5MM | B2B-XH-A(LF)(SN) |  |  |  | 8 | 8
 | J4, J11 |  | CON - Header 1X8 pins, 100Mils - TH-8 | CON_HDR_1X8 |  |  |  | 2 | 2
 | J10, J12, J22 |  | CONN HEADER VERT 4POS 2.5MM | B4B-XH-A(LF)(SN) |  |  |  | 3 | 3
 | J13, J14, J15 |  | CONN HEADER VERT 3POS 2.5MM | B3B-XH-A(LF)(SN) |  |  |  | 3 | 3
 | J16 |  | CON - Header 1x3 pins-100Mils - TH | CON_HDR_1X3 |  |  |  | 1 | 1
 | J17, J18, J20, J21 |  | CONN HEADER VERT 3POS 2.5MM | B3B-XH-A(LF)(SN) |  | DigiKey | 455-2248-ND | 4 | 4
 | J19 |  | CONN HEADER VERT 4POS 2.54MM | 22272041 |  |  |  | 1 | 1
 | J23 |  | CONN RCP USB2.0 TYP C 24P SMD RA | DX07S016JA1R1500 |  |  |  | 1 | 1
 | J24, J25, J26, J27, J28 |  | TERM BLK 4P SIDE ENT 2.54MM PCB | 282834-4 |  | DigiKey | A98335-ND | 5 | 5
 | M1, M2, M3, M4 |  | Bus Driver, HC/UH Series, 1-Func, 1-Bit, True Output, CMOS, PDSO5 | 74HC1G125GV-Q100H |  |  |  | 4 | 4
 | Q1 |  | MOSFET N-CH 100V 9.7A TO-220AB | IRF520NPBF |  |  |  | 1 | 1
 | R1, R2, R3, R4, R5, R6, R7, R8, R9, R10, R11, R12, R13, R14, R15, R16, R17, R18, R19, R20, R21, R24, R25 |  | Custom Semiconductor Resistor | 10 Kohm |  |  |  | 23 | 23
 | R22, R23, R26, R28 |  | Custom Semiconductor Resistor | 4.7 Kohm |  |  |  | 4 | 4
 | R27 |  | Custom Semiconductor Resistor | 90 ohm |  |  |  | 1 | 1
 | R29, R30 |  | Custom Semiconductor Resistor | 5.1 Kohm |  |  |  | 2 | 2
 | U1, U2, U3 |  | Development Boards & Kits - Wireless (Engineering Samples) ESP32-C3 General-Purpose Development Board, embeds ESP32-C3-WROOM-02, 4 MB Flash, with Pin Header | ESP32-C3-DEVKITC-02 |  |  |  | 3 | 3
 | U4 |  | BCM2711 Raspberry Pi 4 Model B 4GB - ARMÂ® CortexÂ®-A72 MPU Embedded Evaluation Board | RASPBERRY_PI_4B_4GB |  |  |  | 1 | 1
Commentaires ou instruction spécialies

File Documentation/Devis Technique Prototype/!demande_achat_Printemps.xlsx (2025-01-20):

Titre du projet
Projet TSO: Jeu d'évasion
Demandeur(s) : Prof responsabe et étudiants
Benoit Beaulieu, Louis Boisvert
Moment où le matériel est NÉCESSAIRE
d'ici la semaine de relache et d'encadrement
Identification des cours qui sont impactés
247-575-SH
Lien(s) vers document de soumission (si applicable)
Liste des éléments associés
Description | Prix unitaire | Taux change (1 par défaut $Can) | Quantité demandée | Total item | Fournisseur | # Modèle pour commande | Hyperlien pour commande (si disponible) ou soumission | Commentaires et/ou autres informations | Colonne réservée pour suivi des commandes
mallette contenant le jeu d'évasion? | 107.95 $ | 1.00 | 1 | 107.95 $ | Nanuk | 910S-010SV-0A0 | https://nanukcases.ca/fr/products/nanuk-910?variant=38294651109557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
bouton lumineux | 15.69 $ | 1.00 | 1 | 15.69 $ | Amazon ESUPPORT | R16-503 16mm | https://a.co/d/gLQzJxG
Interrupteur | 16.99 $ | 1.00 | 1 | 16.99 $ | Amazon Twidec | MTS-202 | https://a.co/d/1r08j27
potentiomètre | 18.99 $ | 1.00 | 2 | 37.98 $ | amazon Taiss | RV24YN20S | https://a.co/d/3zwPCMx | besoin de gros potentiomètre, car il faut que les utilisateurs puisse le tourner sans avoir besoin de tournevis ( ceci peut être une drôle d'énigme)
Borniers simples | 24.98 $ | 1.00 | 1 | 24.98 $ | amazon XALXMAW | connecteurs de fils à levier | https://a.co/d/gQmGtzr
Borniers Raspberry Pi | 32.27 $ | 1.00 | 1 | 32.27 $ | amazon OONO | carte de dérivation | https://a.co/d/1AAymhc
mini écran | 77.99 $ | 1.00 | 1 | 77.99 $ | amazon Kenowa | Écran tactile portable 7" HD 1024 x 600 | https://a.co/d/9c7FX2c
 |  |  | Total sans taxes | 313.85 $
 |  |  | Taxe 7% | 21.97 $
 |  |  | Total avec taxes | 335.82 $

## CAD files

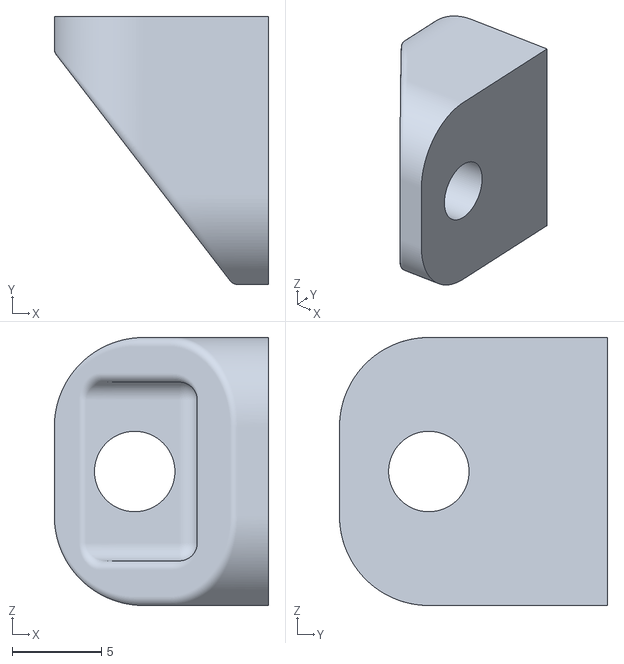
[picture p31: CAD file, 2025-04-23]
Matériel/Equerre_2_inserts.stl
12.0 x 15.0 x 15.0

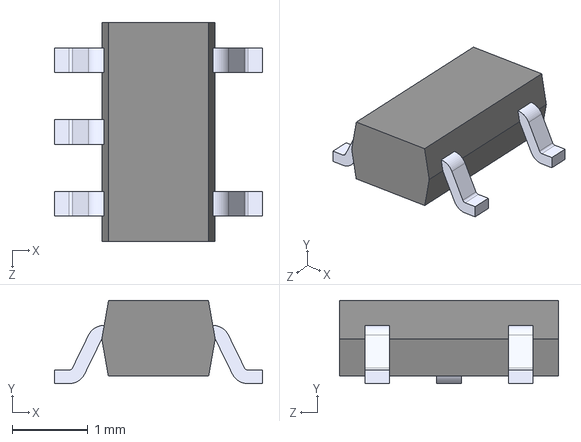
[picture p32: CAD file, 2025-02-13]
Matériel/PCB mallette Altium/74HC1G125GV-Q100H.STEP
2.75 x 1.10 x 2.90 mm

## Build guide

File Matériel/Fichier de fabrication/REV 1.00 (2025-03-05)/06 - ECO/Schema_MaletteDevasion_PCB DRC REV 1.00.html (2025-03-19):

Altium

# Design Rule Verification Report

Date: | | 2025-03-05
Time: | | 11:20:05
Elapsed Time: | | 00:00:02
Filename: | | C:\Users\mario\AppData\Local\TempReleases\Snapshot\3\MalletteV2_PCB_2L.PcbDoc

Warnings: | | 0
Rule Violations: | | 0
Waived Violations: | | 4

## Summary

Warnings | Count
Total | 0

Rule Violations | Count
Clearance Constraint (Gap=0.152mm) (All),(All) | 0
Short-Circuit Constraint (Allowed=No) (All),(All) | 0
Un-Routed Net Constraint ( (All) ) | 0
Modified Polygon (Allow modified: No), (Allow shelved: No) | 0
Width Constraint (Min=0.127mm) (Max=25.4mm) (Preferred=0.152mm) (All) | 0
Power Plane Connect Rule(Relief Connect )(Expansion=0.508mm) (Conductor Width=0.254mm) (Air Gap=0.254mm) (Entries=4) (All) | 0
Minimum Annular Ring (Minimum=0.1mm) (All) | 0
Hole Size Constraint (Min=0.3mm) (Max=6.3mm) (All) | 0
Hole To Hole Clearance (Gap=0.5mm) (All),(All) | 0
Minimum Solder Mask Sliver (Gap=0.1mm) (All),(All) | 0
Net Antennae (Tolerance=0mm) (All) | 0
Board Clearance Constraint (Gap=0mm) (All) | 0
Height Constraint (Min=0mm) (Max=25.4mm) (Prefered=12.7mm) (All) | 0
Total | 0

Waived Violations | Count
Short-Circuit Constraint (Allowed=No) (All),(All) | 4
Total | 4

## Rule Violations

## Waived Violations

Short-Circuit Constraint (Allowed=No) (All),(All)

Short-Circuit Constraint: Between Pad J23-(159.95mm,159.385mm) on Multi-Layer And Polygon Region (318 hole(s)) Top Location : [X = 0mm][Y = 0mm]
Waived by Alexis Létourneau at 2025-03-05 11:07:39
Probleme de silkcreen

Short-Circuit Constraint: Between Pad J23-(159.95mm,159.385mm) on Multi-Layer And Polygon Region (499 hole(s)) Bottom Location : [X = 0mm][Y = 0mm]
Waived by Alexis Létourneau at 2025-03-05 11:07:39
Probleme de silkcreen

Short-Circuit Constraint: Between Pad J23-(159.95mm,166.885mm) on Multi-Layer And Polygon Region (318 hole(s)) Top Location : [X = 0mm][Y = 0mm]
Waived by Alexis Létourneau at 2025-03-05 11:07:39
Probleme de silkcreen

Short-Circuit Constraint: Between Pad J23-(159.95mm,166.885mm) on Multi-Layer And Polygon Region (499 hole(s)) Bottom Location : [X = 0mm][Y = 0mm]
Waived by Alexis Létourneau at 2025-03-05 11:07:39
Probleme de silkcreen

Back to top

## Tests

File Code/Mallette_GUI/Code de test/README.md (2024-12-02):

# Dossier de Tests pour le Prototype Modulable  

Ce dossier contient plusieurs codes de test permettant de vérifier les fonctionnalités du circuit. Ces tests ont été conçus pour développer un prototype modulable.  

## Tests Disponibles  

1. **Test de bouton simple :**  
   Vérifie le fonctionnement de base des boutons.  

2. **Test de bouton avec contrôle utilisateur :**  
   Ignore les clics rapides ou involontaires pour donner un contrôle exclusif à l’utilisateur.  

3. **Test d’affichage de LED virtuel selon la position d’un interrupteur :**  
   Simule l’état d’une LED en fonction de la position d’un interrupteur virtuel.  

4. **Test d’affichage de LED virtuel selon la position réelle des interrupteurs :**  
   Affiche l’état des LEDs en fonction des positions physiques des interrupteurs connectés au circuit.  

5. **Code finale de l'interface graphique en pysimplegui et de la communication I2C et mqtt dans le pi**
---

### Remarque  
Ces tests permettent de valider et d’affiner les différents modules du prototype avant leur intégration finale.

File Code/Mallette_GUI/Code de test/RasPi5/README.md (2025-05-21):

# GPIO Init Library (Prototype) – Raspberry Pi 5

⚠️ **Les codes suivants sont des prototypes non fonctionnel.**

## IO_test.py
le code suivant est le code qui réussit à ce rendre le plus loin avant de donner une erreur.

## ouput_test.py 
le code suivant est un code pris d'un site internet, il n'est pas fonctionnel, mais est le plus prometteurs parmis les examples qui existe présentement sur internet.

## à savoir...
comme décris dans le pdf suivant "https://datasheets.raspberrypi.com/rp1/rp1-peripherals.pdf", le raspberry pi 5 possède une architecture différente des versions précédentes. il possède une chip gère toutes les entrés et sorties du board en même temps. ce qui est différent des versions précédentes qui possèdait 2 chip avec des configurations définit. Ce changement détruit le fonctionnement des libraries qui étaient typiquement utilisées.

## NE PAS FAIRE CONFIANCE AUX INTELLIGENCES ARTIFICIELS

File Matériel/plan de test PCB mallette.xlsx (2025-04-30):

 | Plan de tests
Nom du PCB | PCB mallette | Préparé par | Alexis Létourneau
Cours | 247-67P-SH PROJET DE FIN D'ÉTUDES | Testeur | Alexis Létourneau et Louis Boisvert
Département | Technologies du génie électrique | date | 2025-03-11
Révision | 1.00
Fonction | Test | Résultat | Commentaires
Alimentation | Tester pour les court-circuits avec un multimètre en mode résistance sur les pattes 5v et mise à terre | Échec | il y a un short-circuit entre le VUSB et le GND au niveau des via de support du connecteur usb-c. Problèeme réglé en perçant un trou dans le via dans les PCB.
Alimentation | Tester la résistance entre les pattes des composants énergivores avec un multimètre en mode résistance sur les pattes 5v et la patte des pattes des Vin des composantes pour éviter les court-circuit. | Réussi
Mécanique | Tester l'ergonomique de la poignée. Verifier s'il y a des angles coupants | Échec | Le fabricant n'a pas mis de poignée comme désigné sur le PCB. La poignée est bien là sur Altium. Une plainte a été lancé.
Position des trous de montage du PCB | En plaçant le PCB dans la mallette, voire si les trous de montage ne passe pas a travers les supports du dessous. | Réussi
Connecteur USB-C | Le PCB est fonctionnel du bon coté selon l'indication sur le silkcreen | Réussi
Dimension de la mallette et du PCB | Tester pour voir si le PCB rentre au fond de la mallette avec un peu d'espace entre les bords. | Réussi
Position des trous de montage pour le Raspberry pi 4 | Voir si les trou de montage du PI rentre dans les trous de montage du PCB | Réussi
Position des connecteurs | Tester s'il est possible d'ajouter et de retirer des fils facilements même si tous les autres connecteurs sont connectés. | Réussi
Alimentation des esp32 | Vérifier que les esp32 sont alimenté lorsqu'ils sont connecté au circuit et que le cable USB-C est connecté | Réussi
Communication i2c | Tester avec cmd sur le PI s'il voit les périphériques i2c (esp32) , quand ils sont connectés, avec la commande "i2cdetect -y 1" | Échec | Il faut que les esp32 boot après le PI pour activer le i2c des esp32
Mini écran | Tester la connection HDMI du mini écran avec le PI | Réussi
Alimentation intégrale | Tester si le câble USB-C fournit toute la puissance nécessaire | Échec | L'écran demande trop de courant si on l'alimente à l'aide du PI
Intégration | Avec le programme python "integrationTotal" vérifier que tout les esp32 et leurs objets interactifs transmettent leurs donnèes et les affichent sur le mini écran. | Échec | Les pots sont non fonctionnel. La DEL adressable au pin 10 est non fonctionnel. L'écran demande trop de courant si on l'alimente à l'aide du PI
Modifications / commentaires pour une deuxième version du PCB
1 | Ajouter une dead zone autour des points de montage du port USB-C, car il cause un court-circuit sinon
2 | Spécificier au fabricant d'ajouter l'espace vide dans le pcb pour servir de poigner permettant de prendre et de l'enlever sans difficultée ou blessure
3 | Les patte gpio 9, gpio 8 et gpio 5 du esp32 POT devrait être au gpio0, gpio1 et gpio2
4 | Changer le connecteur USB-C pour un cable plus facile a souder
5 | Utiliser une seule bande de DEL adressable au lieu de 4
6 | Le pi n'a pas assez de courant pour alimenter tous et l'écran avec les ports USB-C du pi
7 | Les resistance des SW ne sont pas dans le bon ordre, ils sont dans l'ordre 2,1,4,3,6,5,8,7 au lieu de 1,2,3,4,5,6,7,8
8 | Les GPIO 12 et 18 tout comme 13 et 19, partage le même PWM, ce qui provoque que les strip de dels vont avoir exactement le même signal. Il est donc uniquement possible d'avoir 3 strip de dels différentes en même temps
9
10

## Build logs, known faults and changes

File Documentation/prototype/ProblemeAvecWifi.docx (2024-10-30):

Le problème avec utilisation Wifi du esp32 pour le projet final de la mallette

- Le délai de connexion peut atteindre 5 secondes, se qui est un problème si le esp32 se déconnecte du wifi pour une raison ou une autre.
- L’esp32 ne semble pas capable de se connecter avec n’importe quelle réseau, il faut un réseau sans sécurité qui accepte les micro-processeurs. Le réseau du Cégep est un exemple d’un réseau qui n’accepte pas.
- Le code pour UDP ou TCP requiert une configuration du serveur qui est complexe.

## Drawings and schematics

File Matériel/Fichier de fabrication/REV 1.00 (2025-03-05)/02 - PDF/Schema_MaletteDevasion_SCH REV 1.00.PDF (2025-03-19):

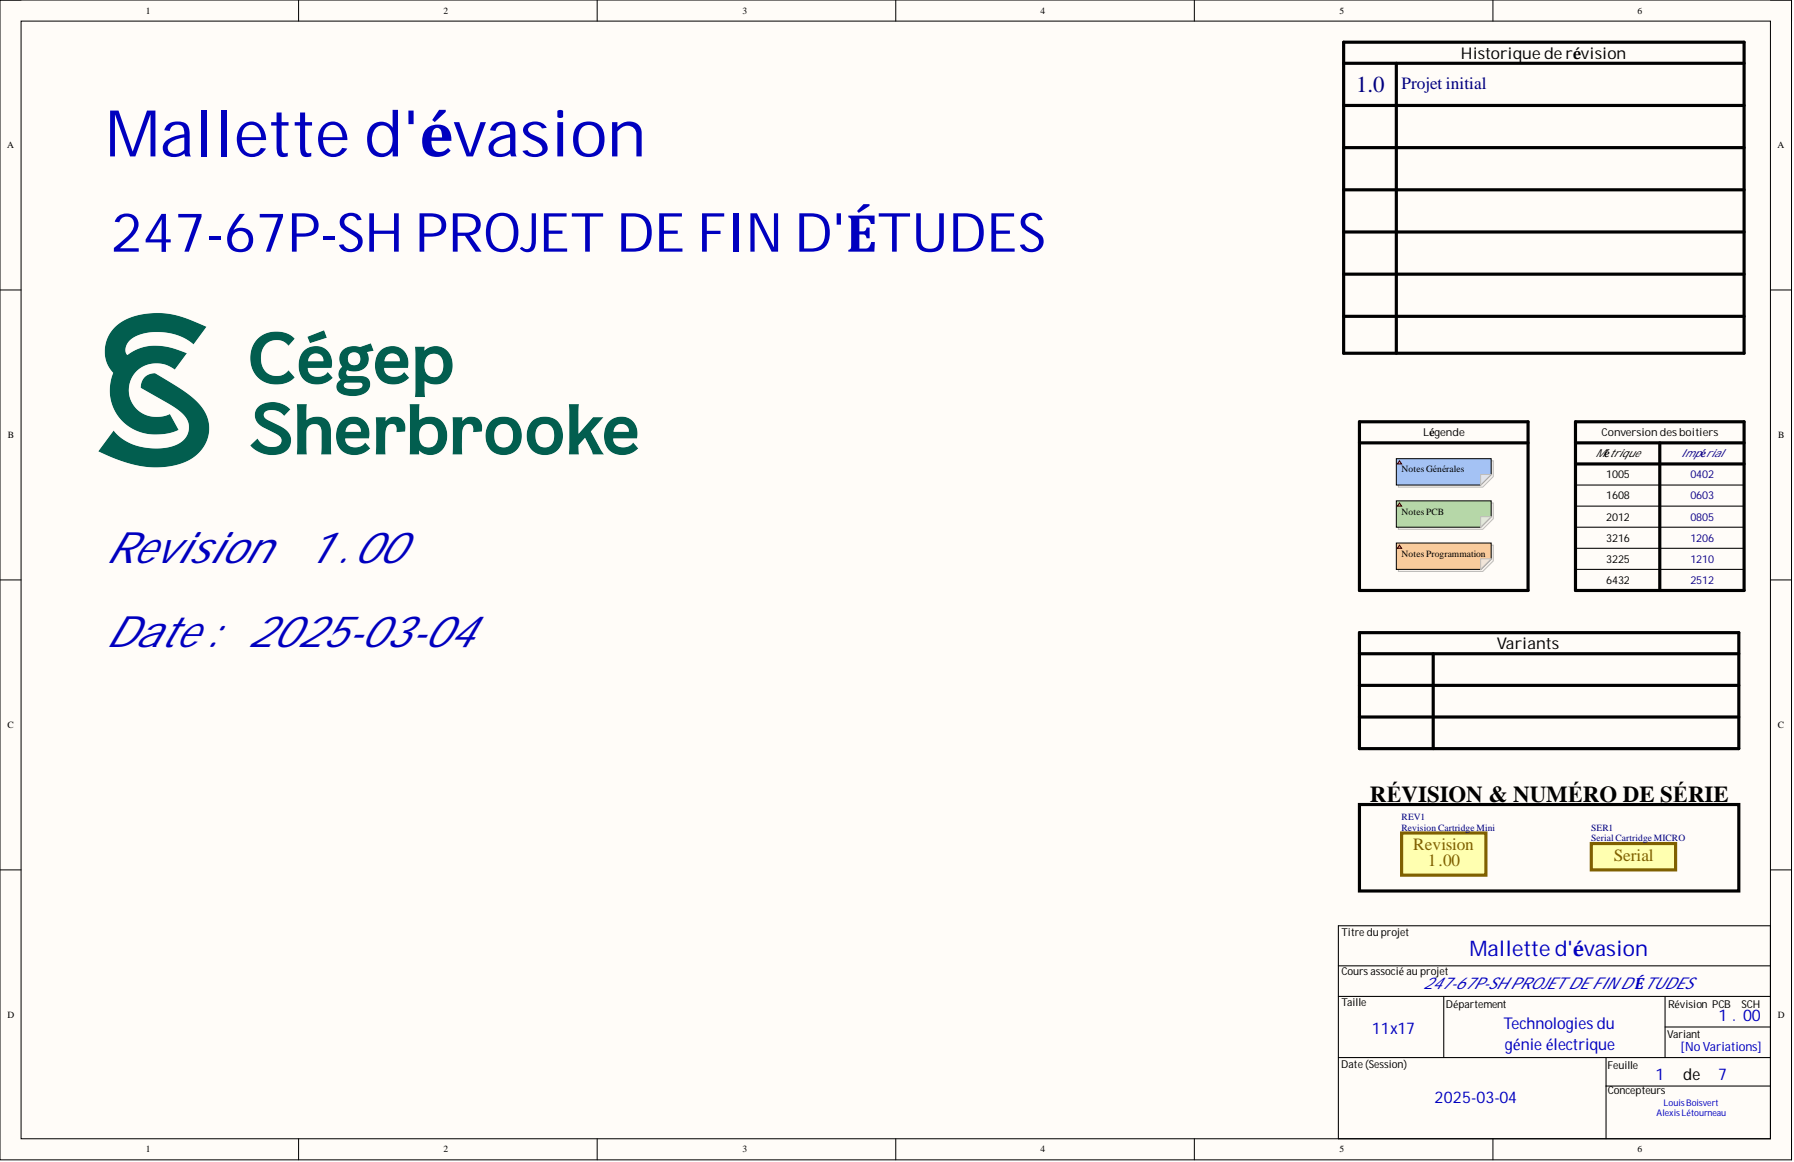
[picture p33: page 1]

-SH PROJET DE FIN

-SH PROJET DE FIN D

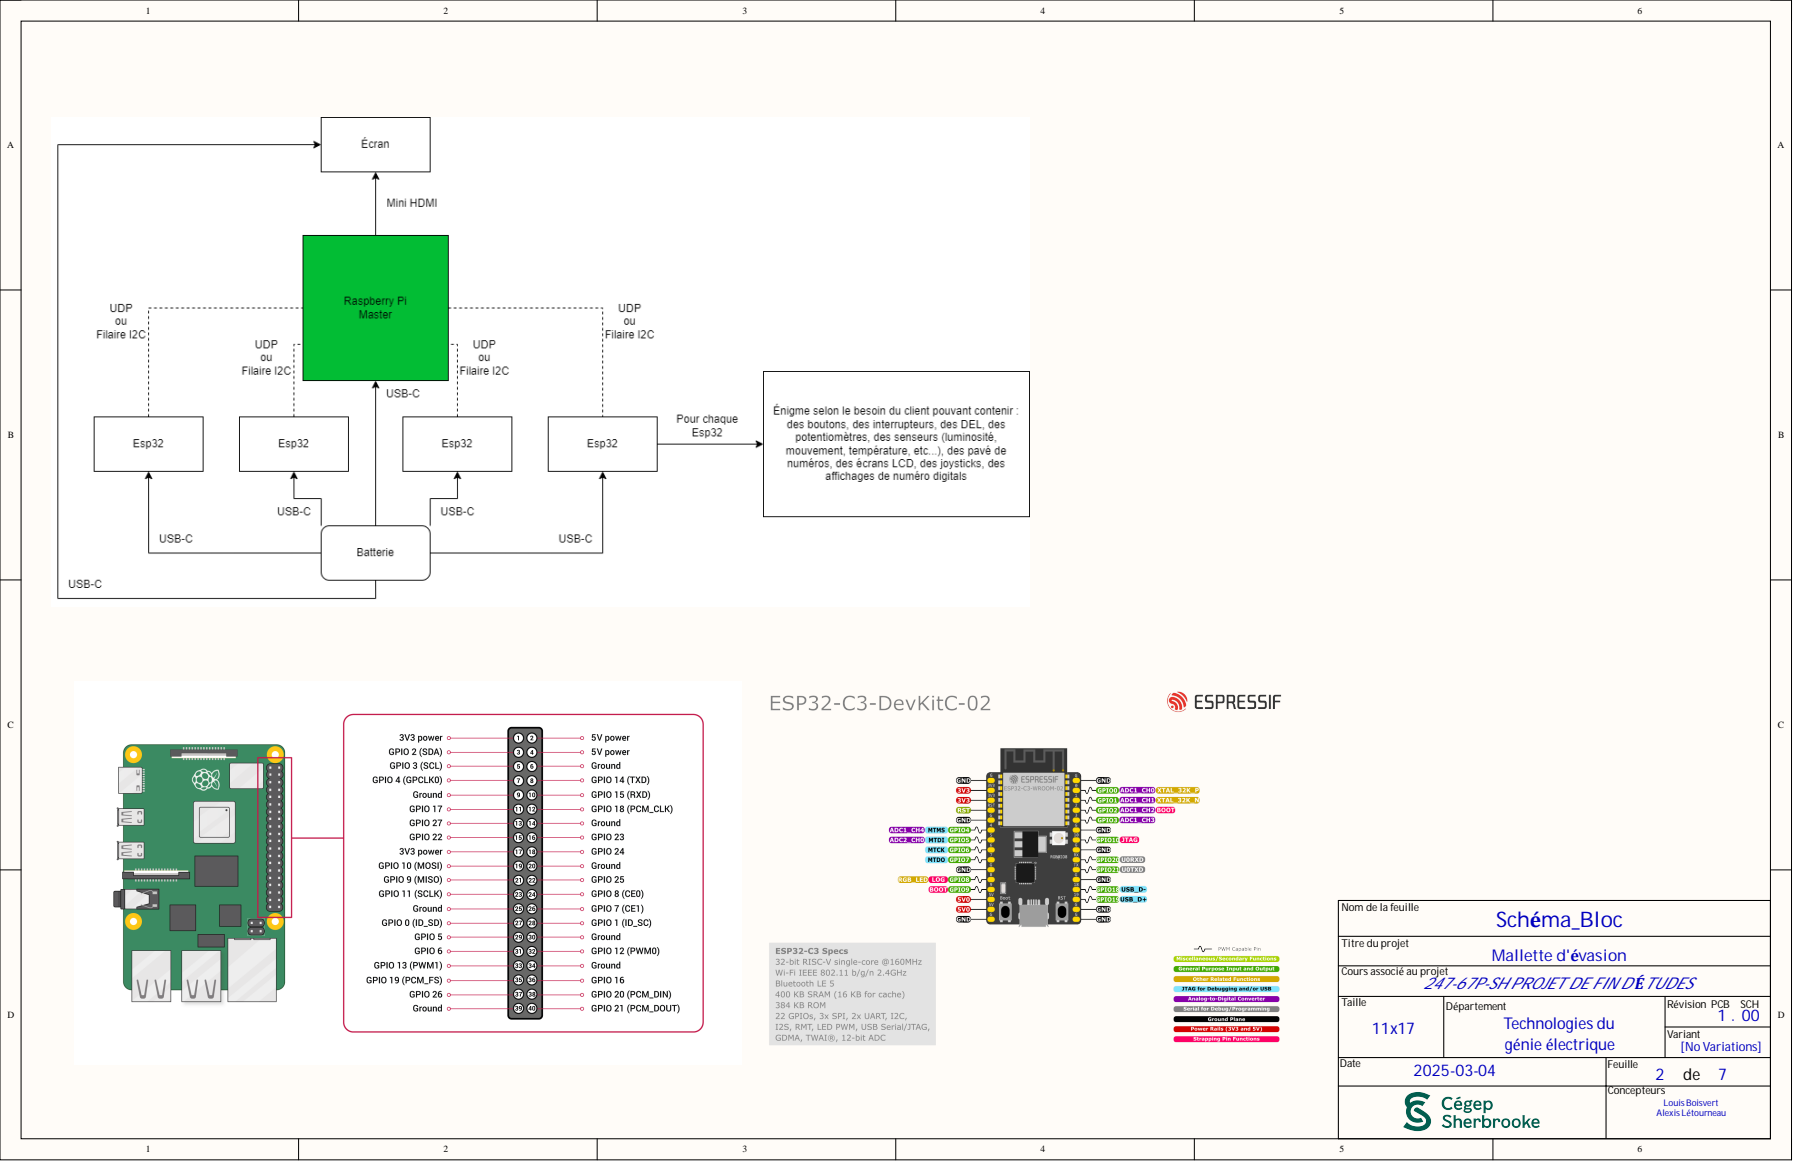
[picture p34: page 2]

Nom de la feuille

Cours associé au projet

247-67P-SH PROJET DE FIN D'ÉTUDES

Date 2025-03-04 | Feuille de

Concepteurs Louis Boisvert Alexis Létourneau

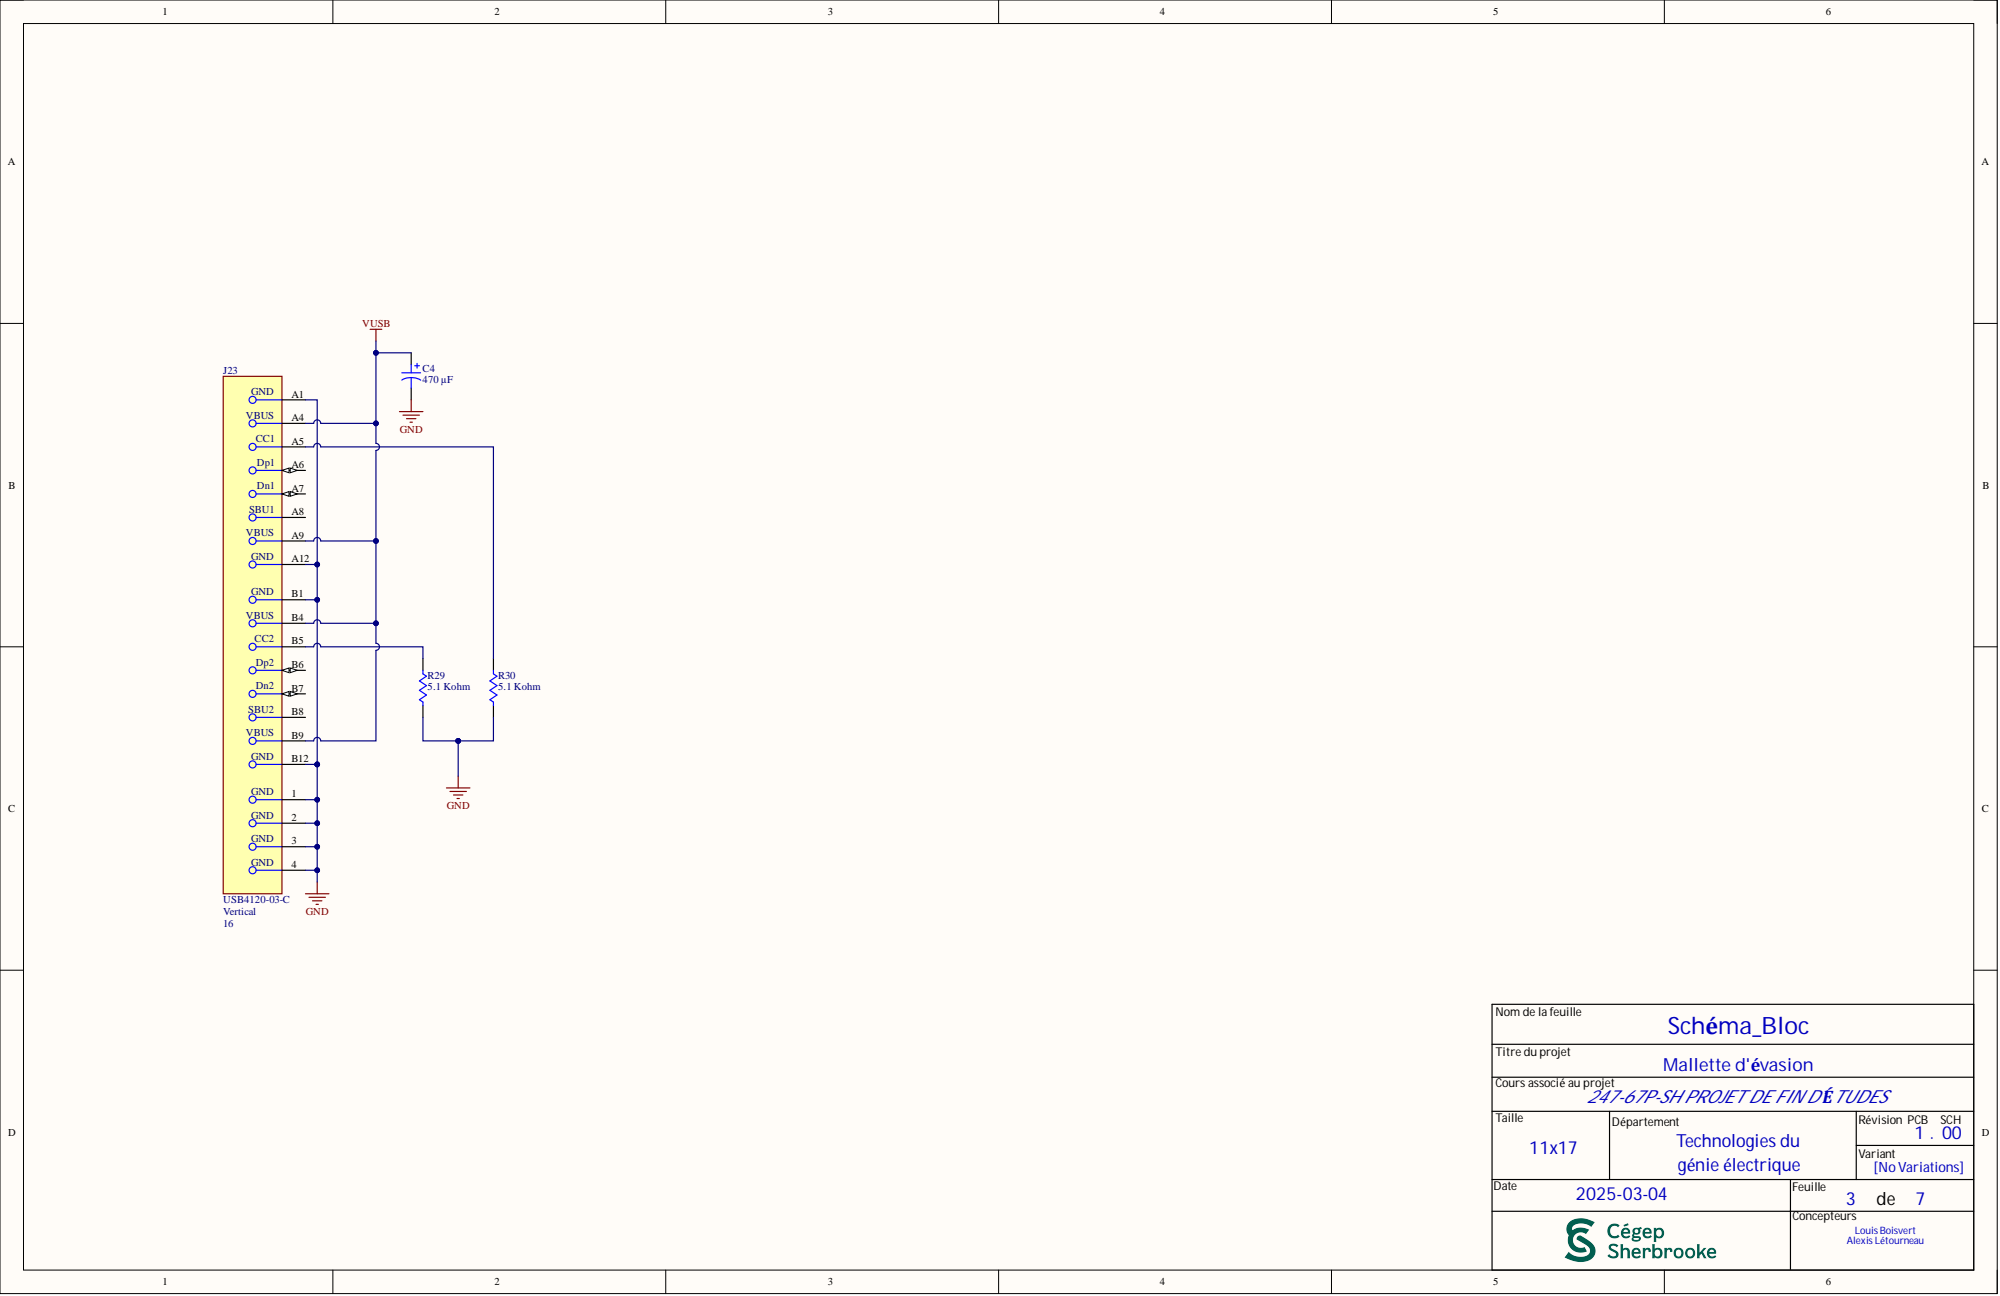
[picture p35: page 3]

Nom de la feuille

Cours associé au projet

247-67P-SH PROJET DE FIN D'ÉTUDES

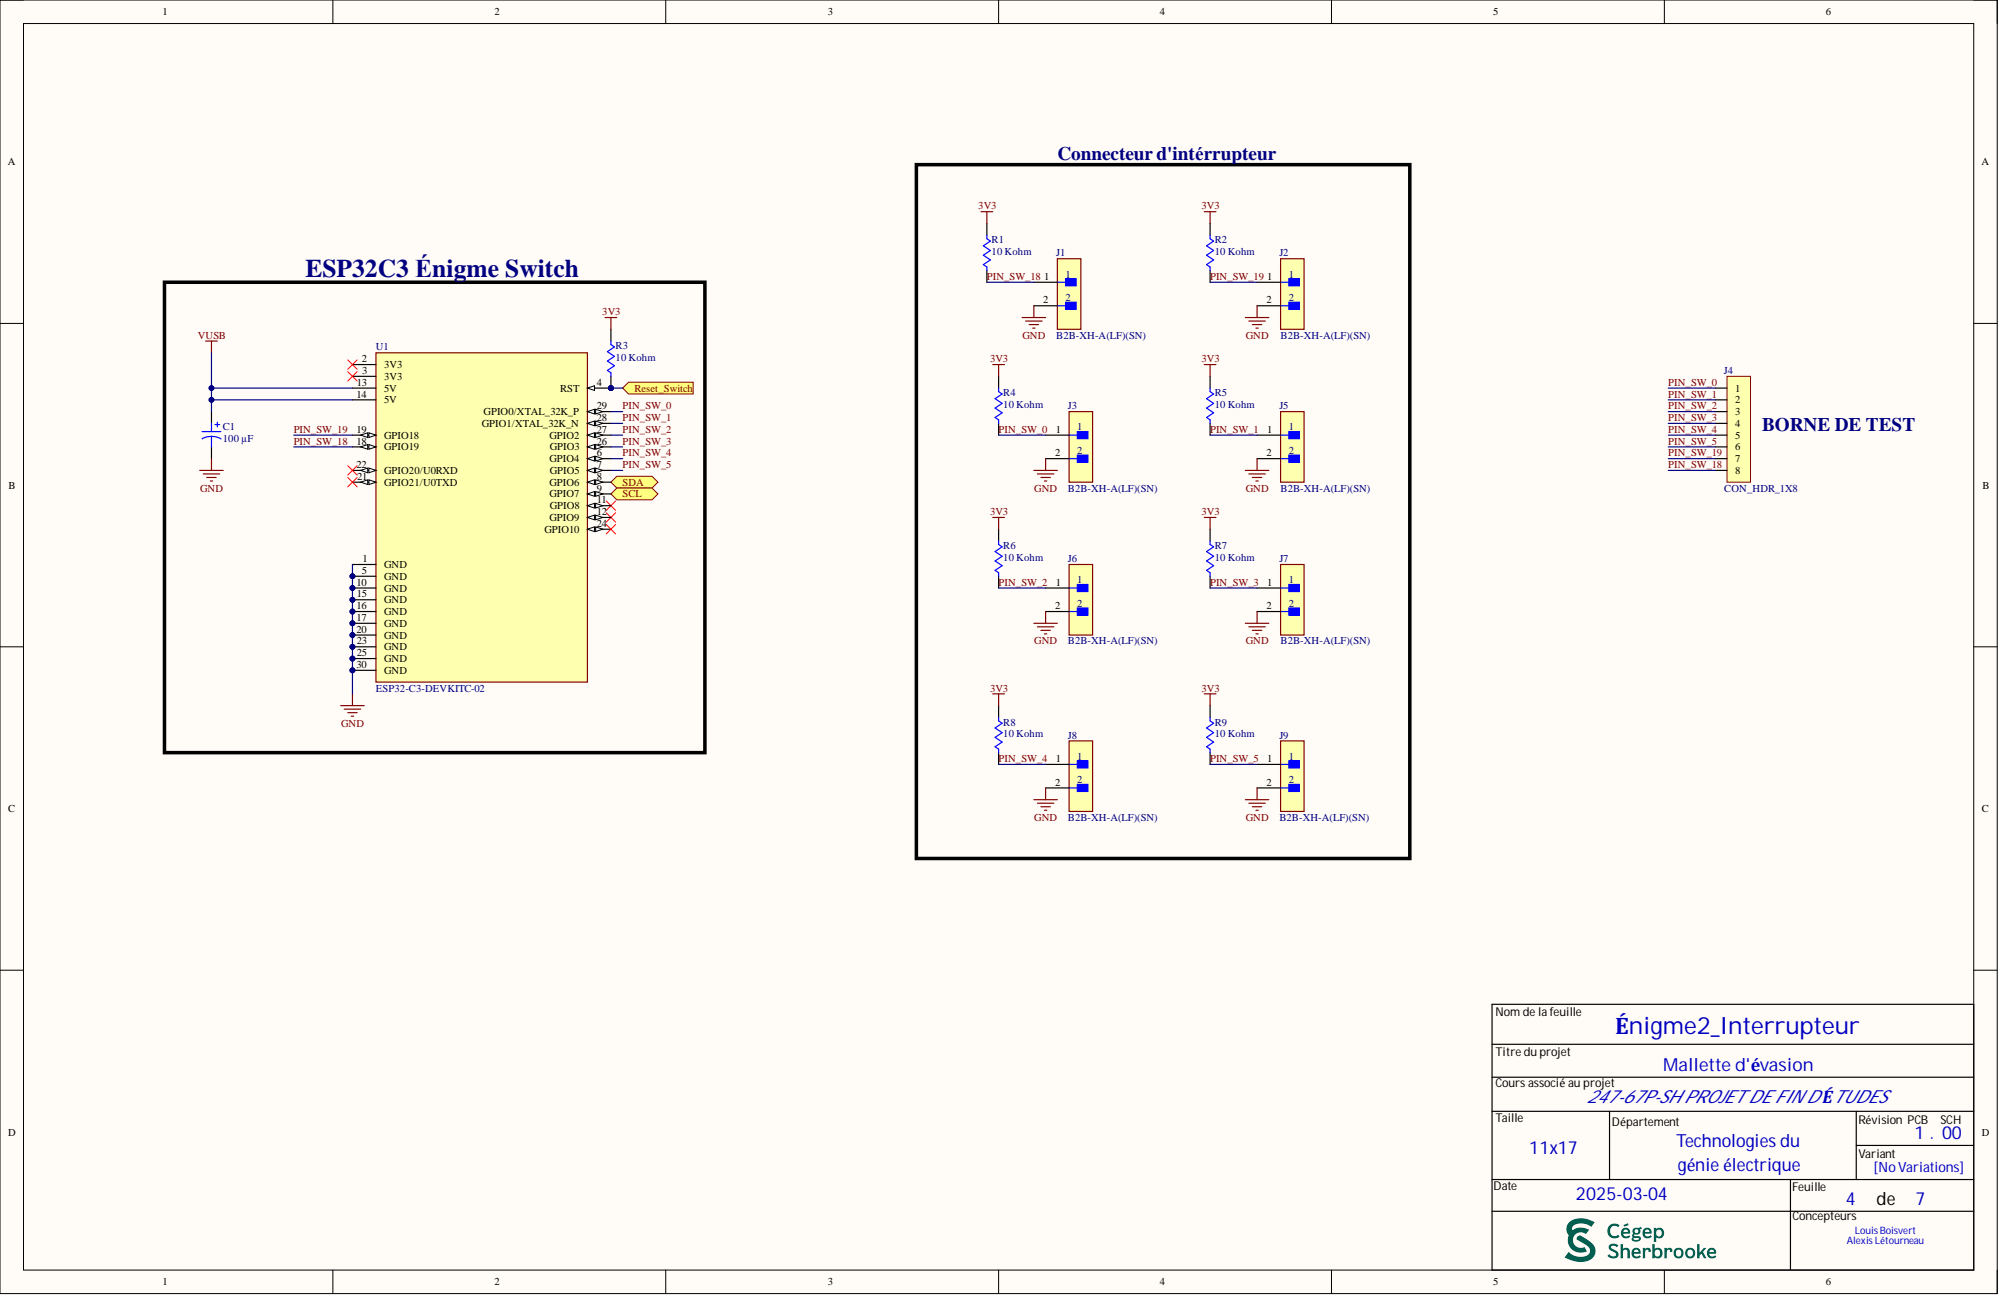
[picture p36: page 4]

Nom de la feui

Mallette d
-SH PROJET DE FIN D

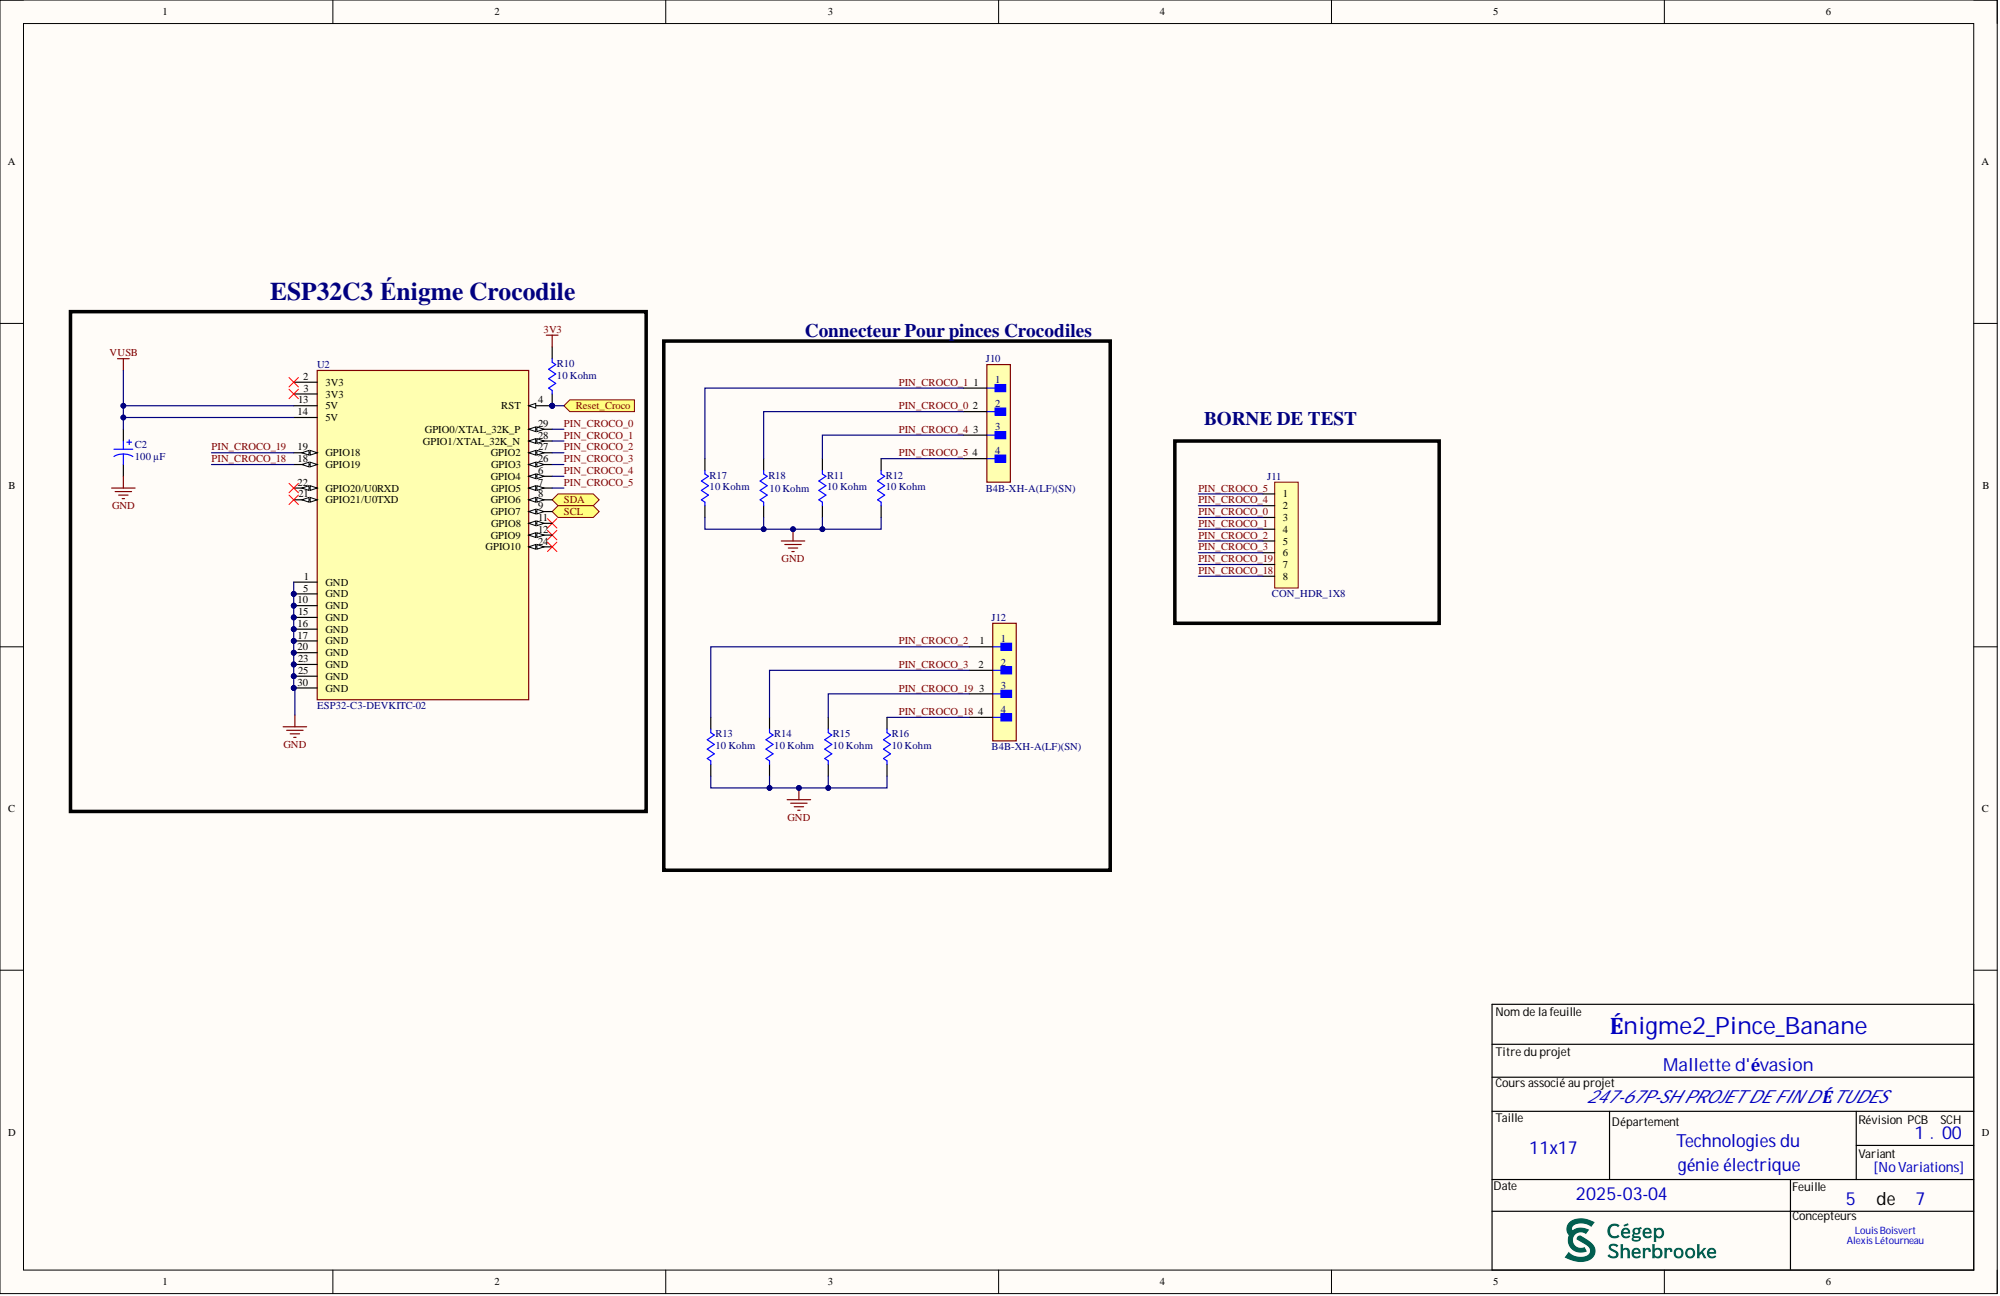
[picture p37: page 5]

Connecteur Pour pinces Cr

PIN _CROCO _ | 1234 0 | BORNE DE TEST Reset_Croco

PIN _CROCO _4

PIN _CROCO _ | 5

PIN _CROCO _ 3 | 1234

PIN _CROCO _ 1 | 9

PIN _CROCO _ 1 | 8

Nom de la feui

Mallette d
-SH PROJET DE FIN D

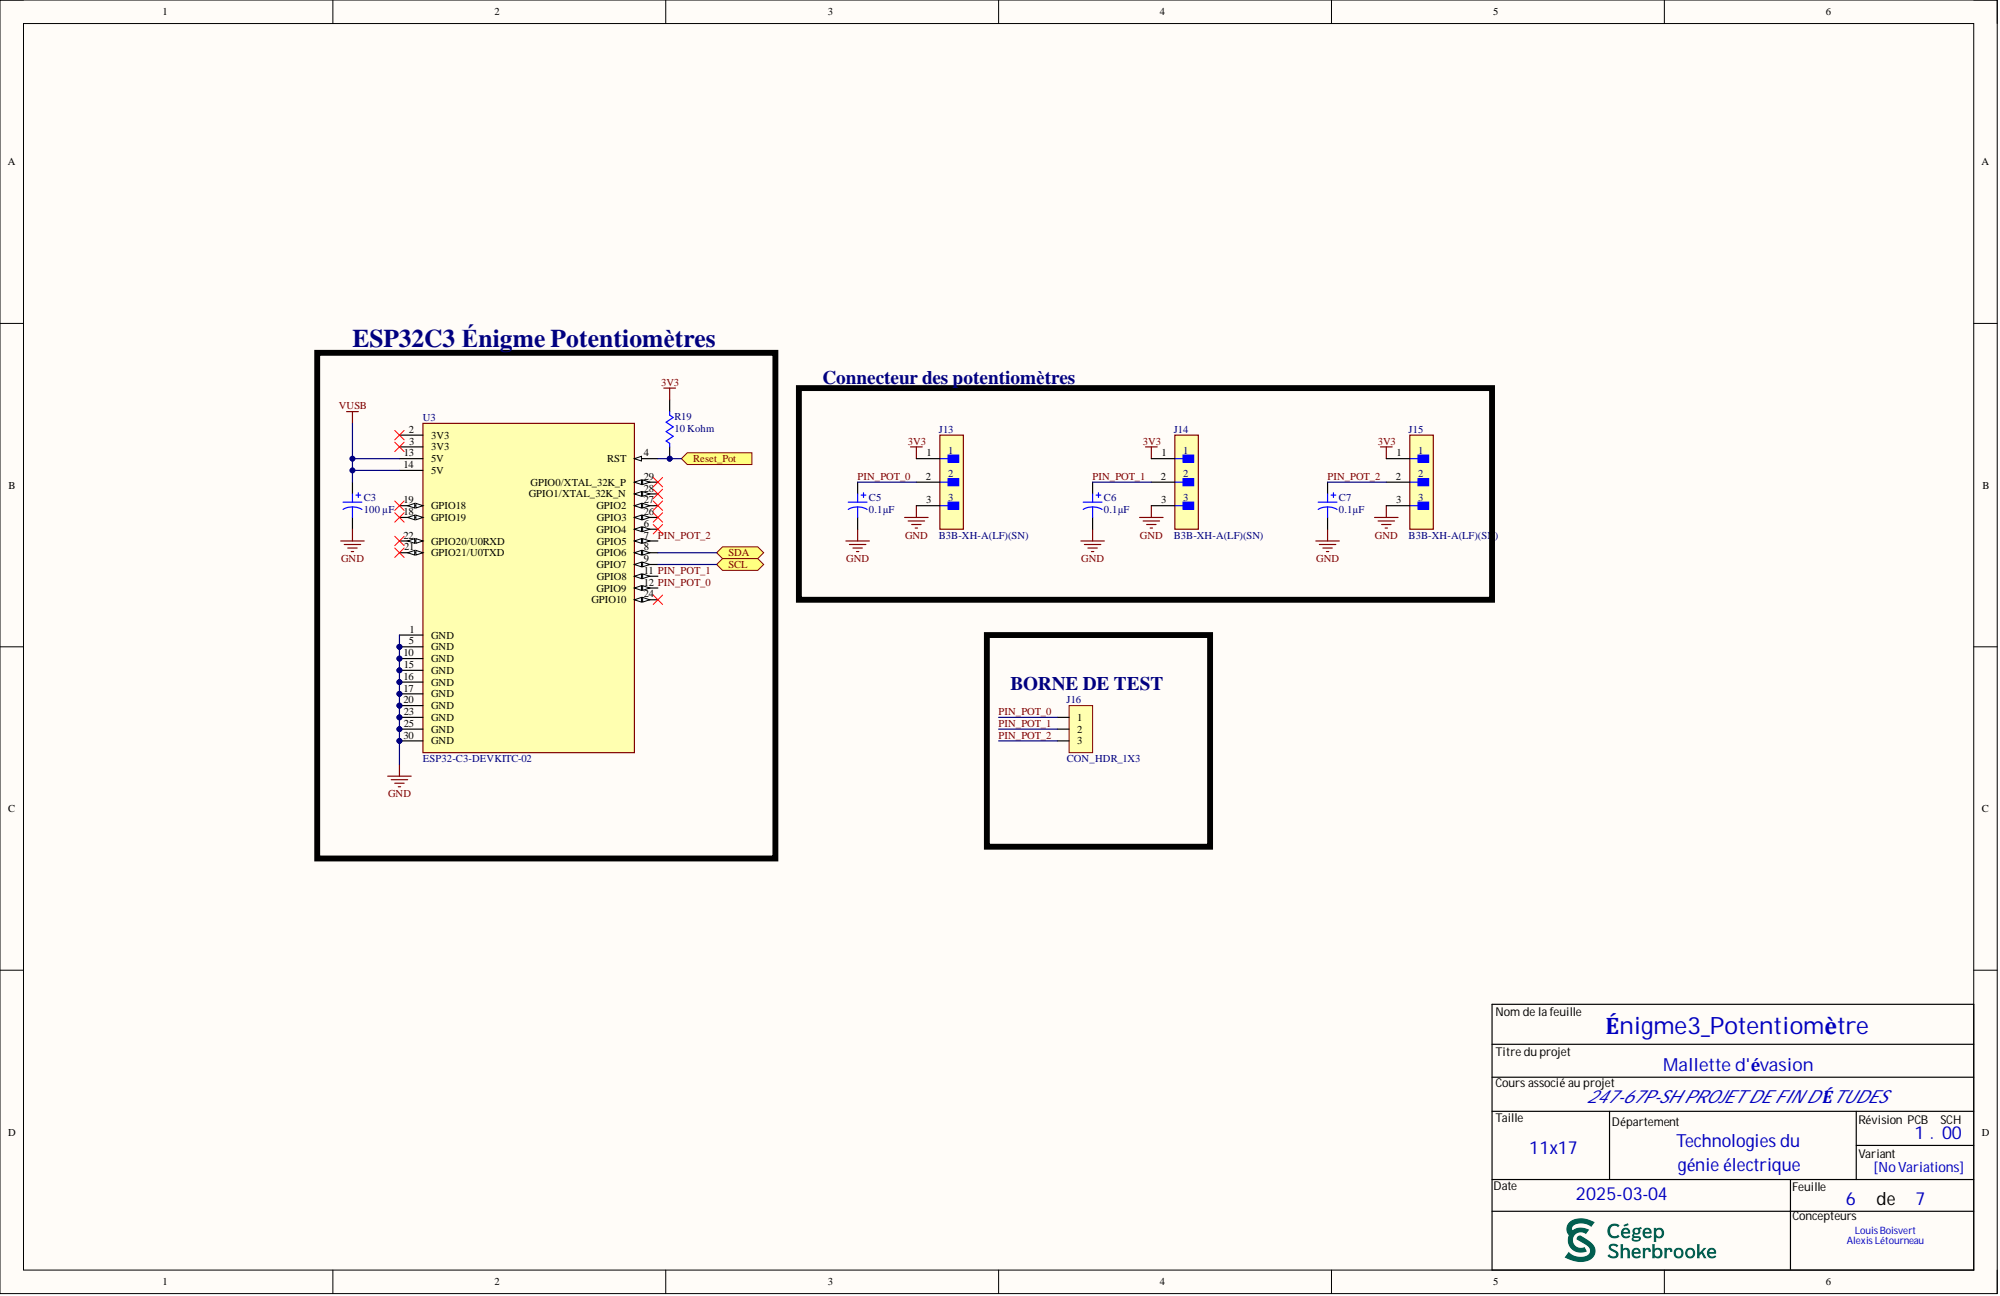
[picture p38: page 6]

Nom de la feui

Mallette d
-SH PROJET DE FIN D

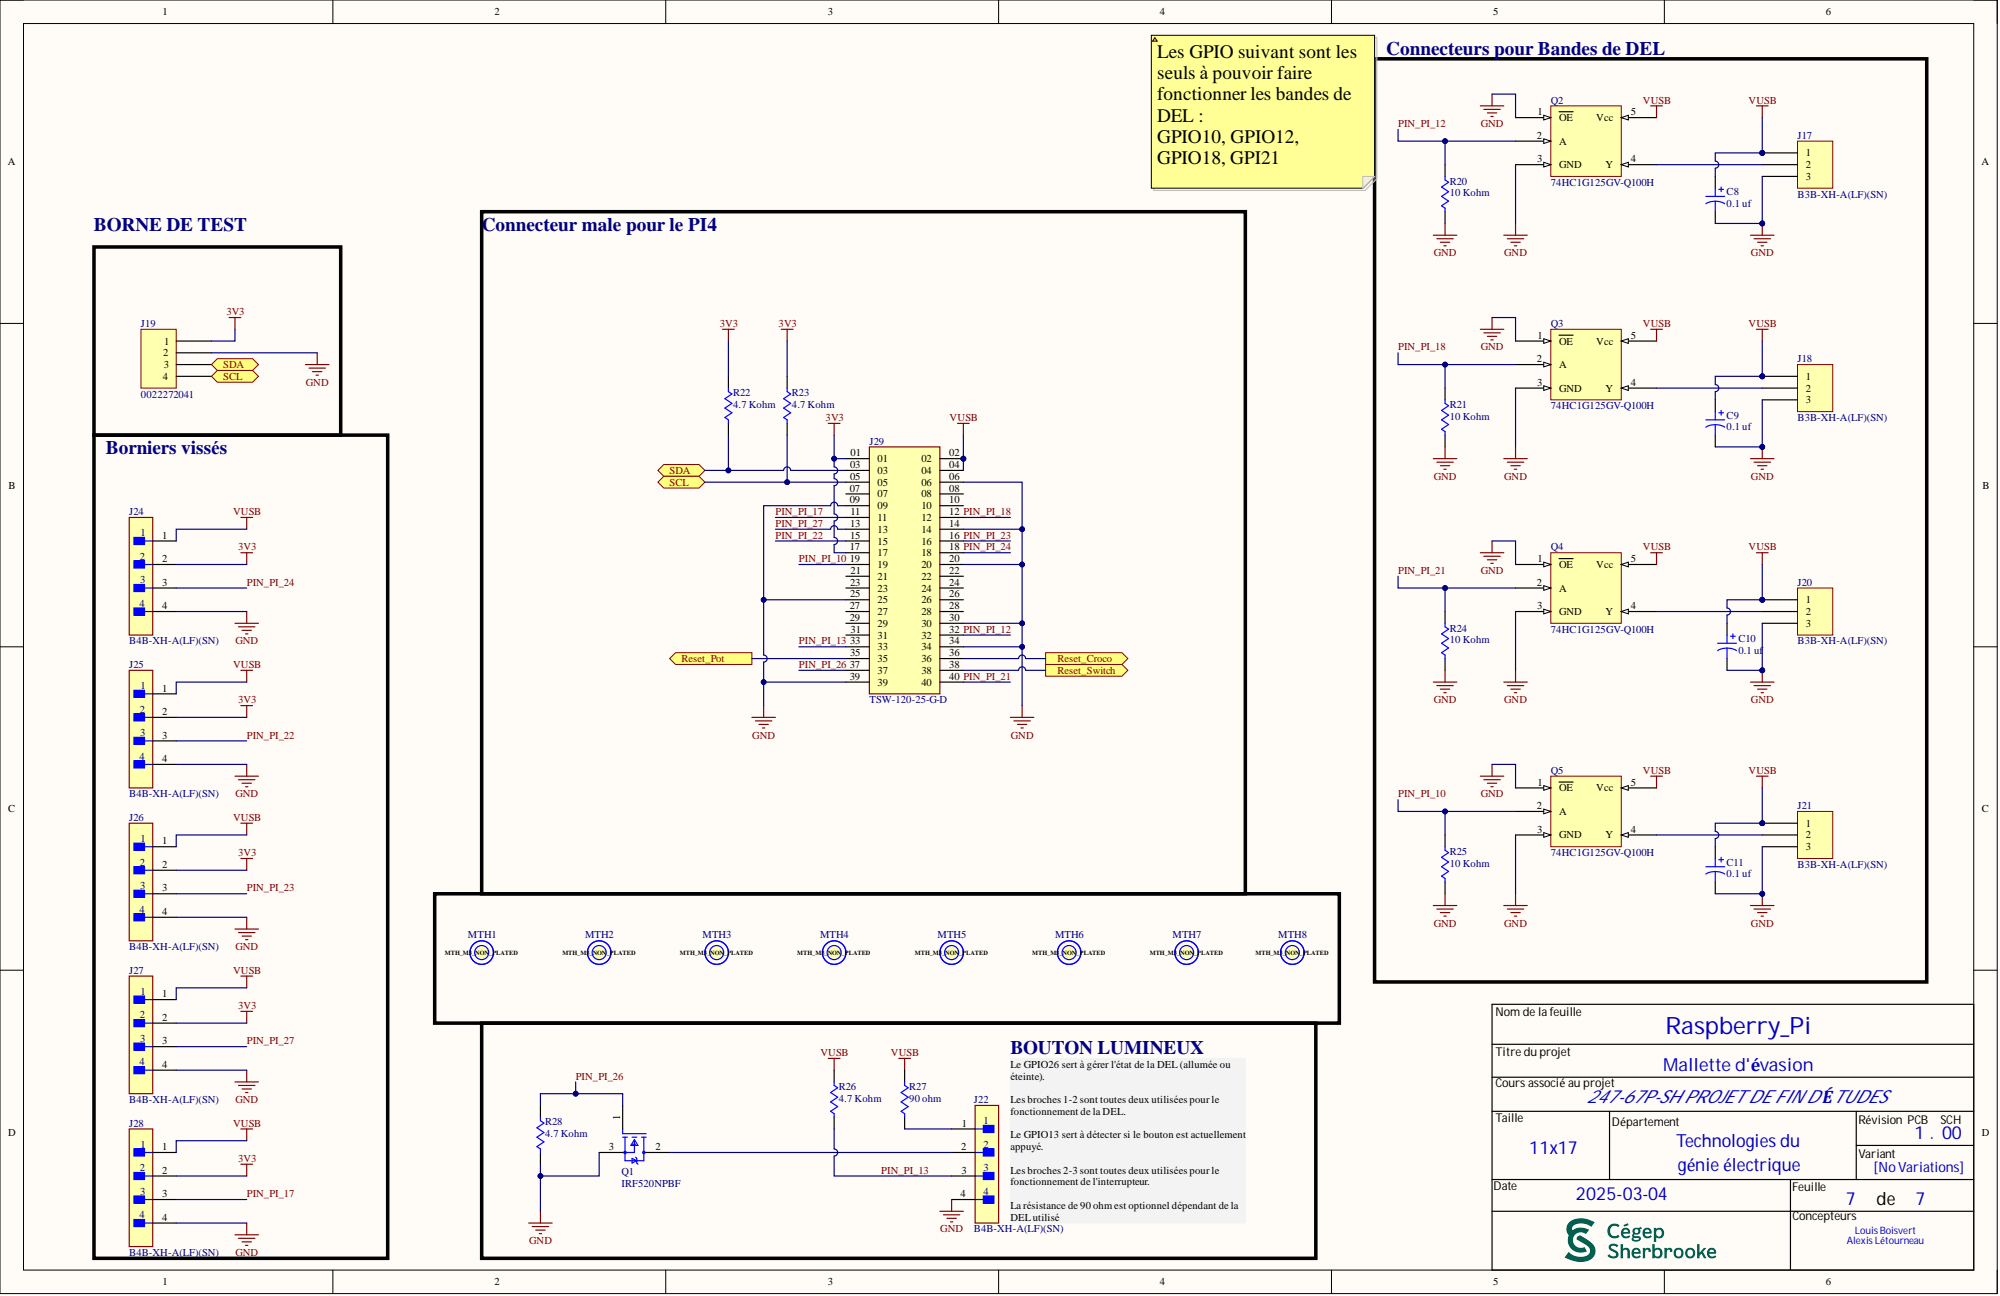
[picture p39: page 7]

Les GPIO suivant sont les
seuls à pouvoir faire
fonctionner les bandes de
DEL :
GPIO10, GPIO12,
GPIO18, GPI21

Connecteurs pour Bandes de DEL

Connecteur male pour le PI4

Nom de la feuille

Le GPIO26 sert à gérer l'état de la DEL (allumée ou
éteinte).

Cours associé au projet

247-67P-SH PROJET DE FIN D'ÉTUDES

Les broches 1-2 sont toutes deux utilisées pour le
fonctionnement de la DEL.

Le GPIO13 sert à détecter si le bouton est actuellement
appuyé.

Les broches 2-3 sont toutes deux utilisées pour le
fonctionnement de l'interrupteur.

La résistance de 90 ohm est optionnel dépendant de la
DELutilisé

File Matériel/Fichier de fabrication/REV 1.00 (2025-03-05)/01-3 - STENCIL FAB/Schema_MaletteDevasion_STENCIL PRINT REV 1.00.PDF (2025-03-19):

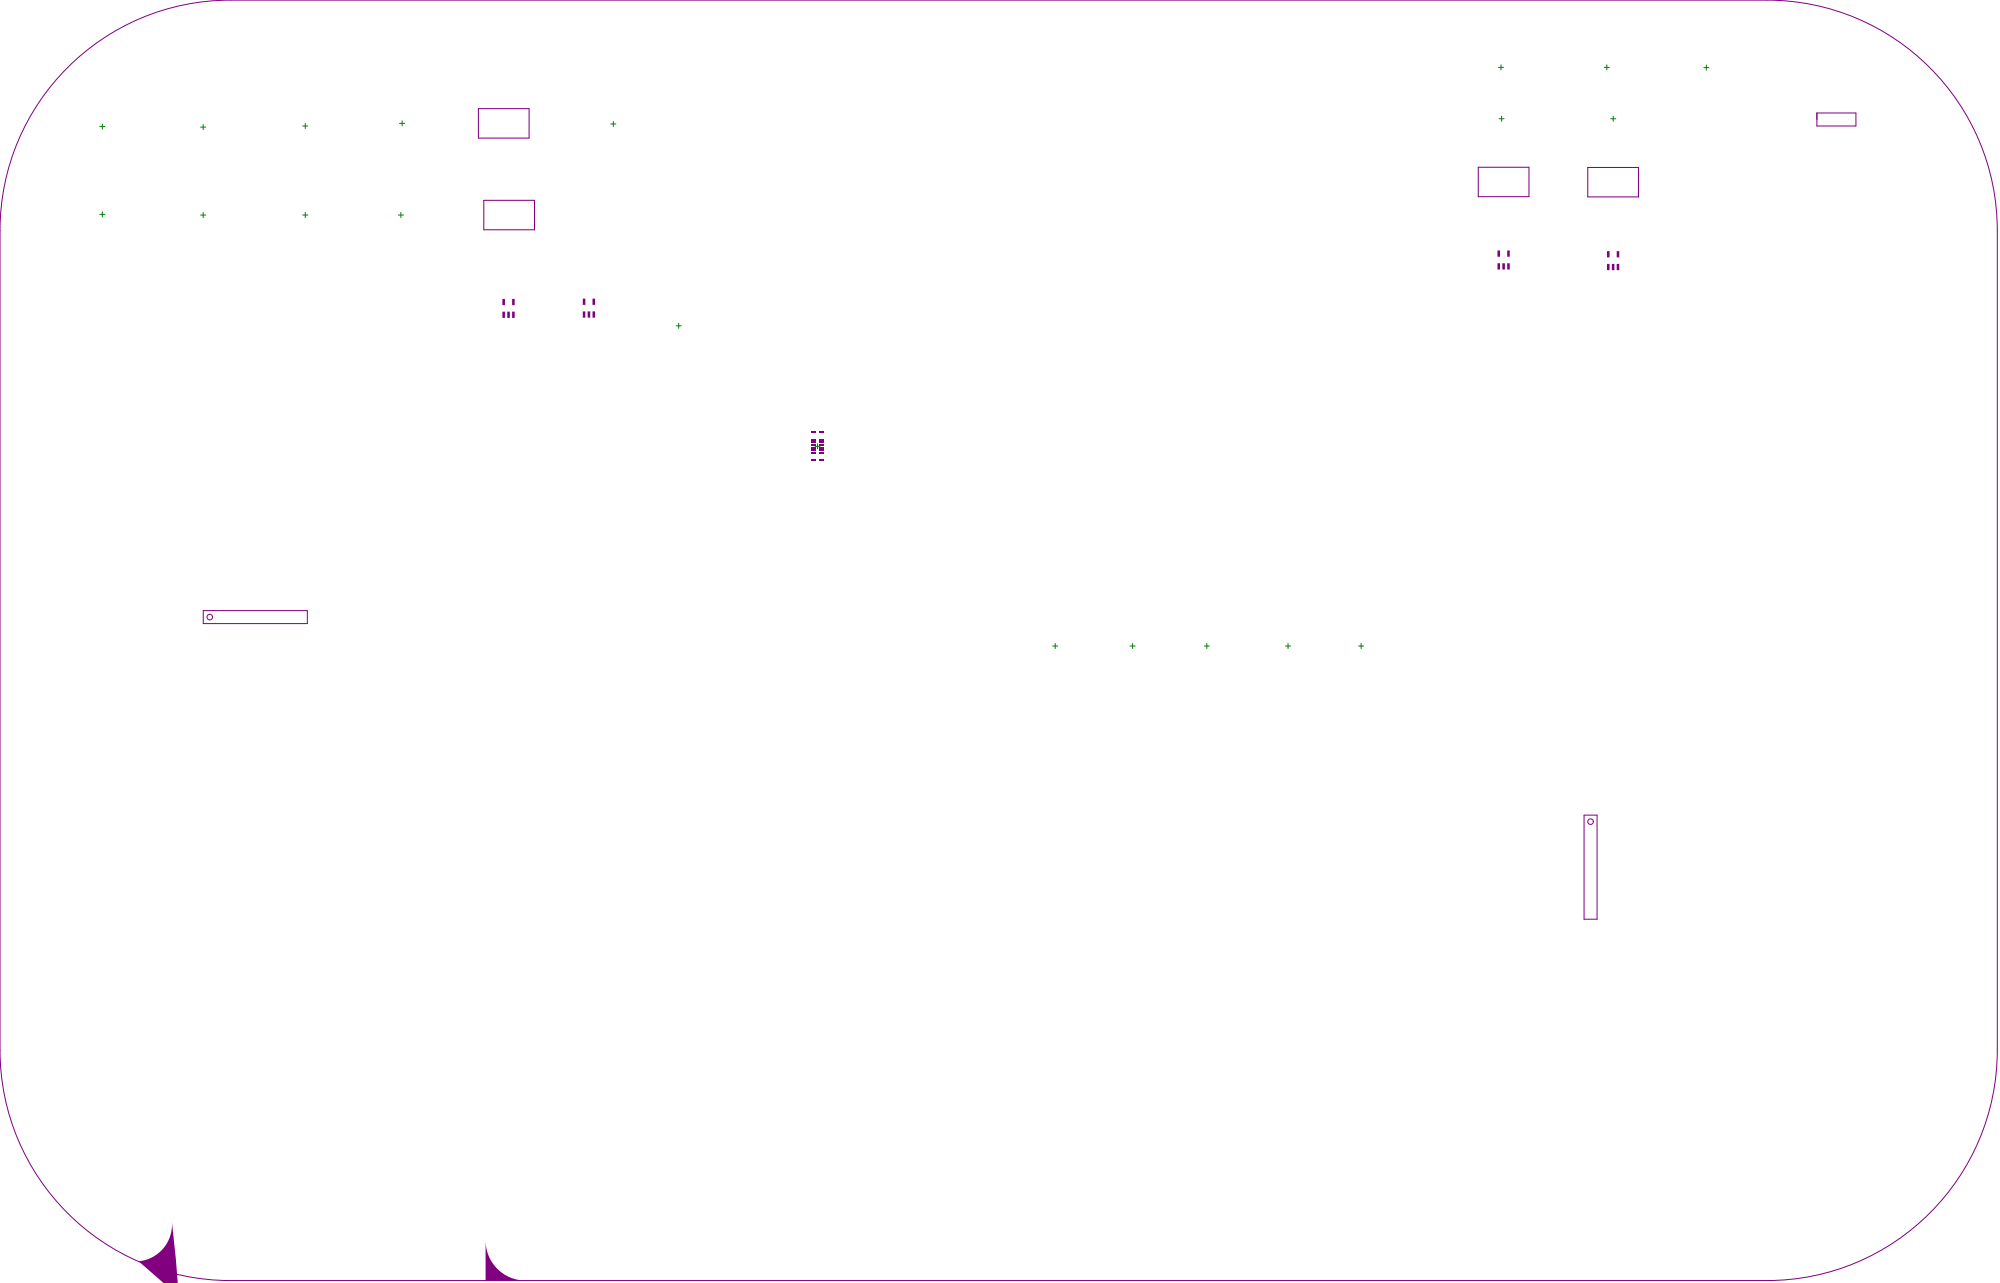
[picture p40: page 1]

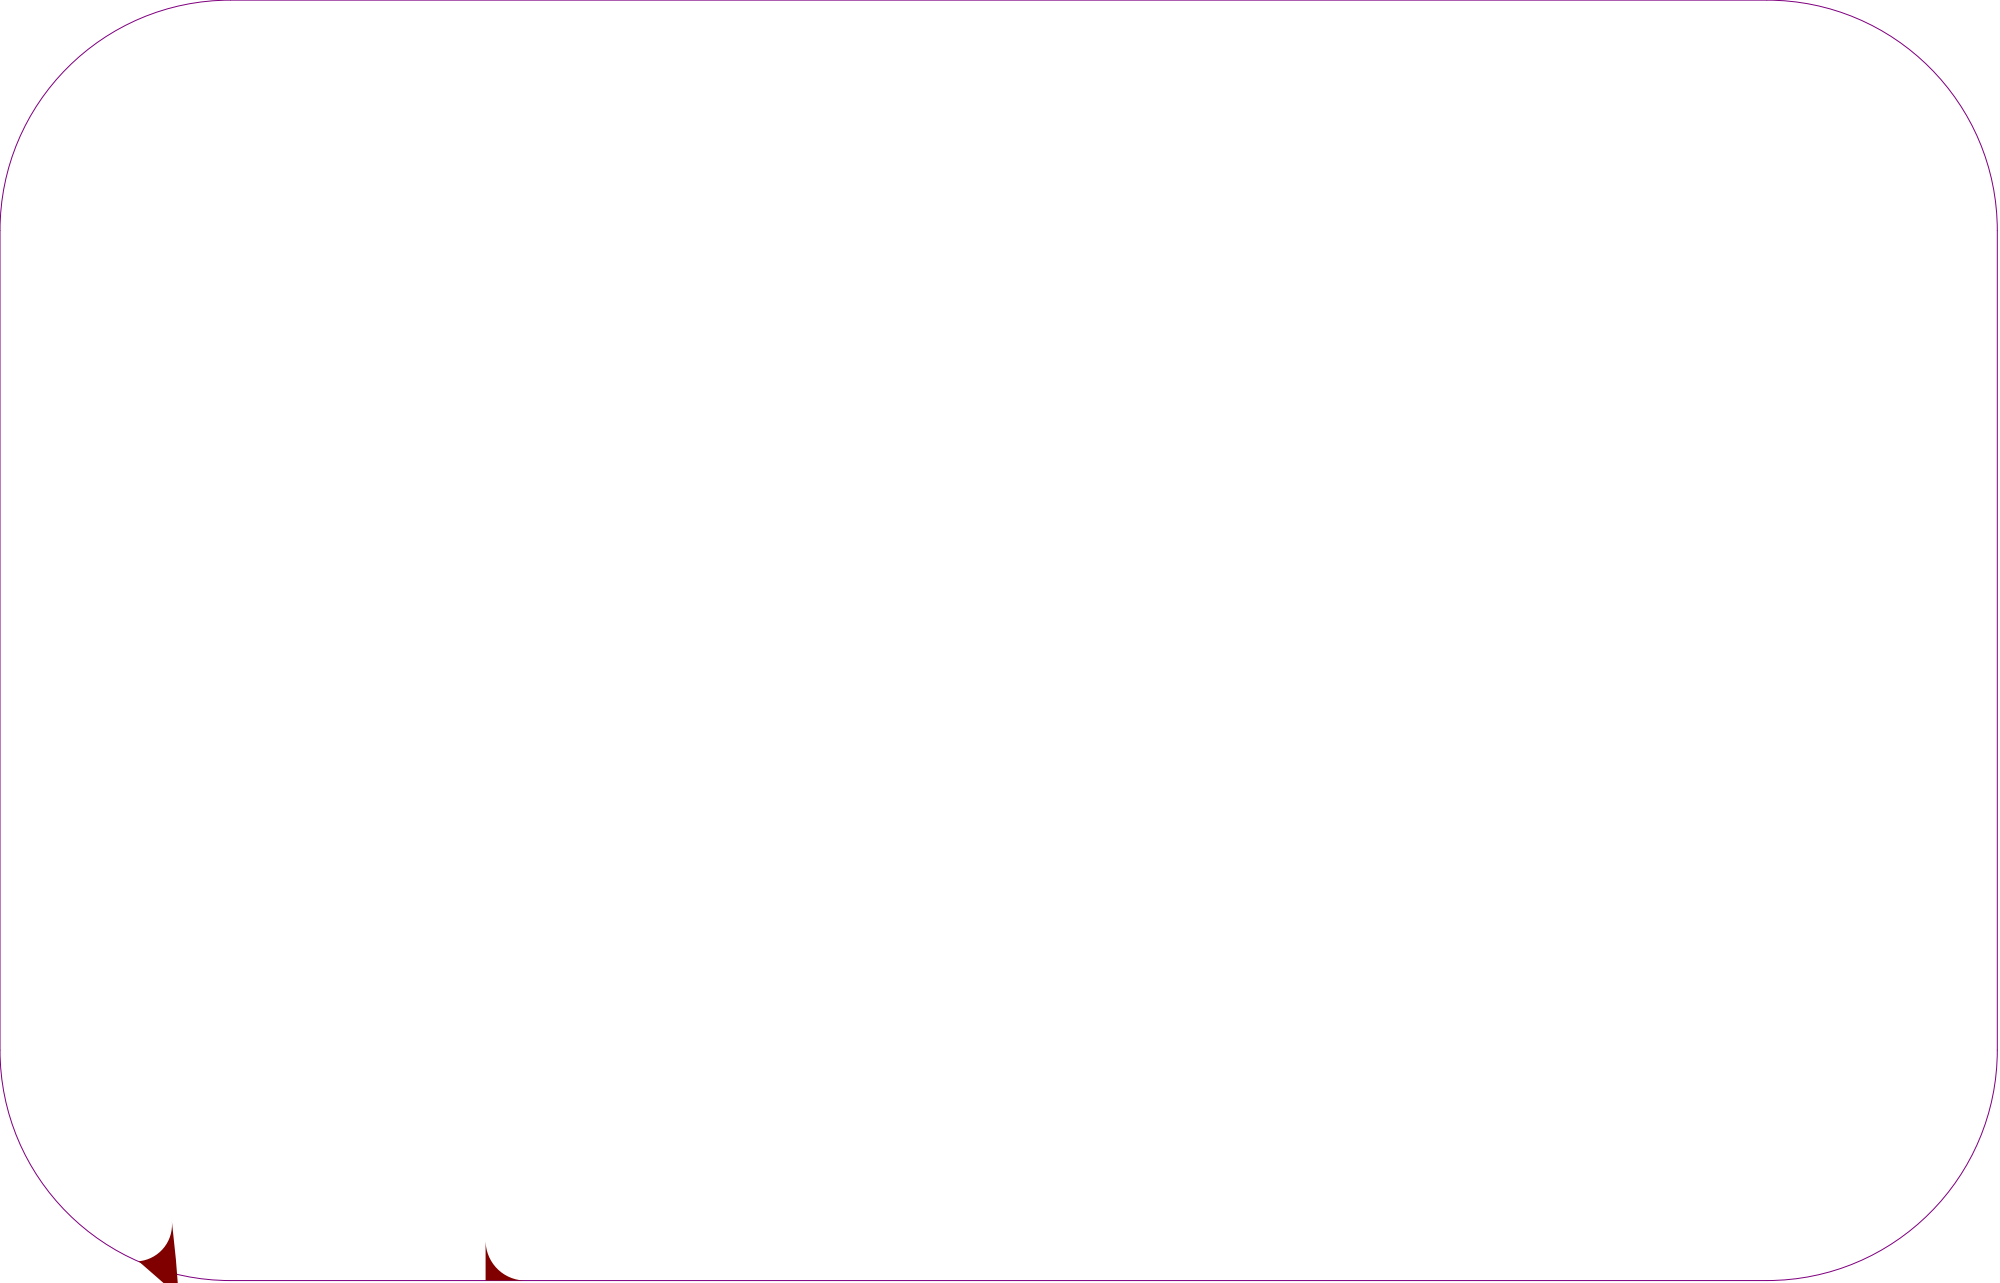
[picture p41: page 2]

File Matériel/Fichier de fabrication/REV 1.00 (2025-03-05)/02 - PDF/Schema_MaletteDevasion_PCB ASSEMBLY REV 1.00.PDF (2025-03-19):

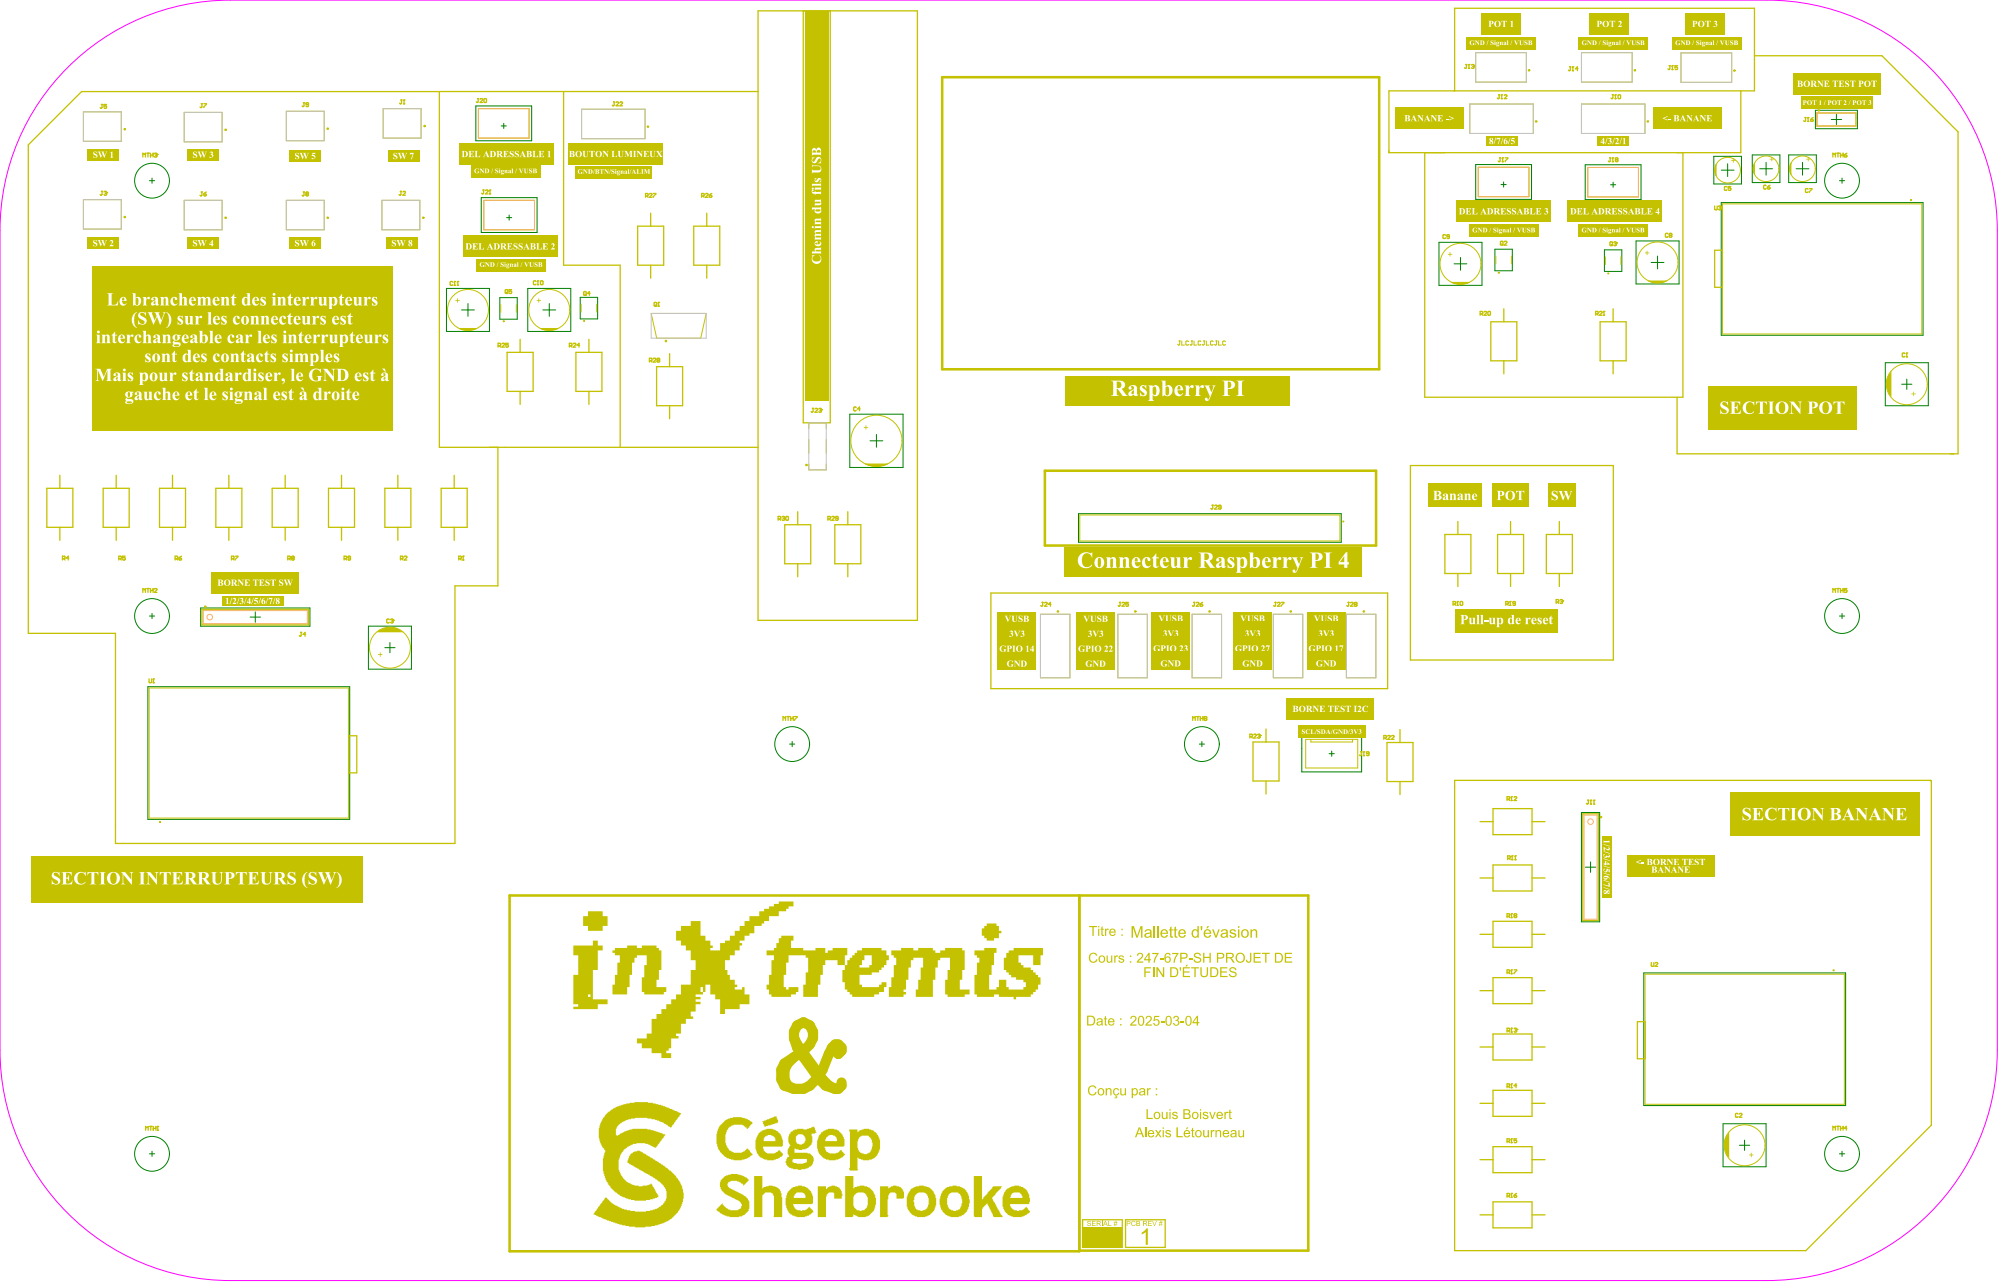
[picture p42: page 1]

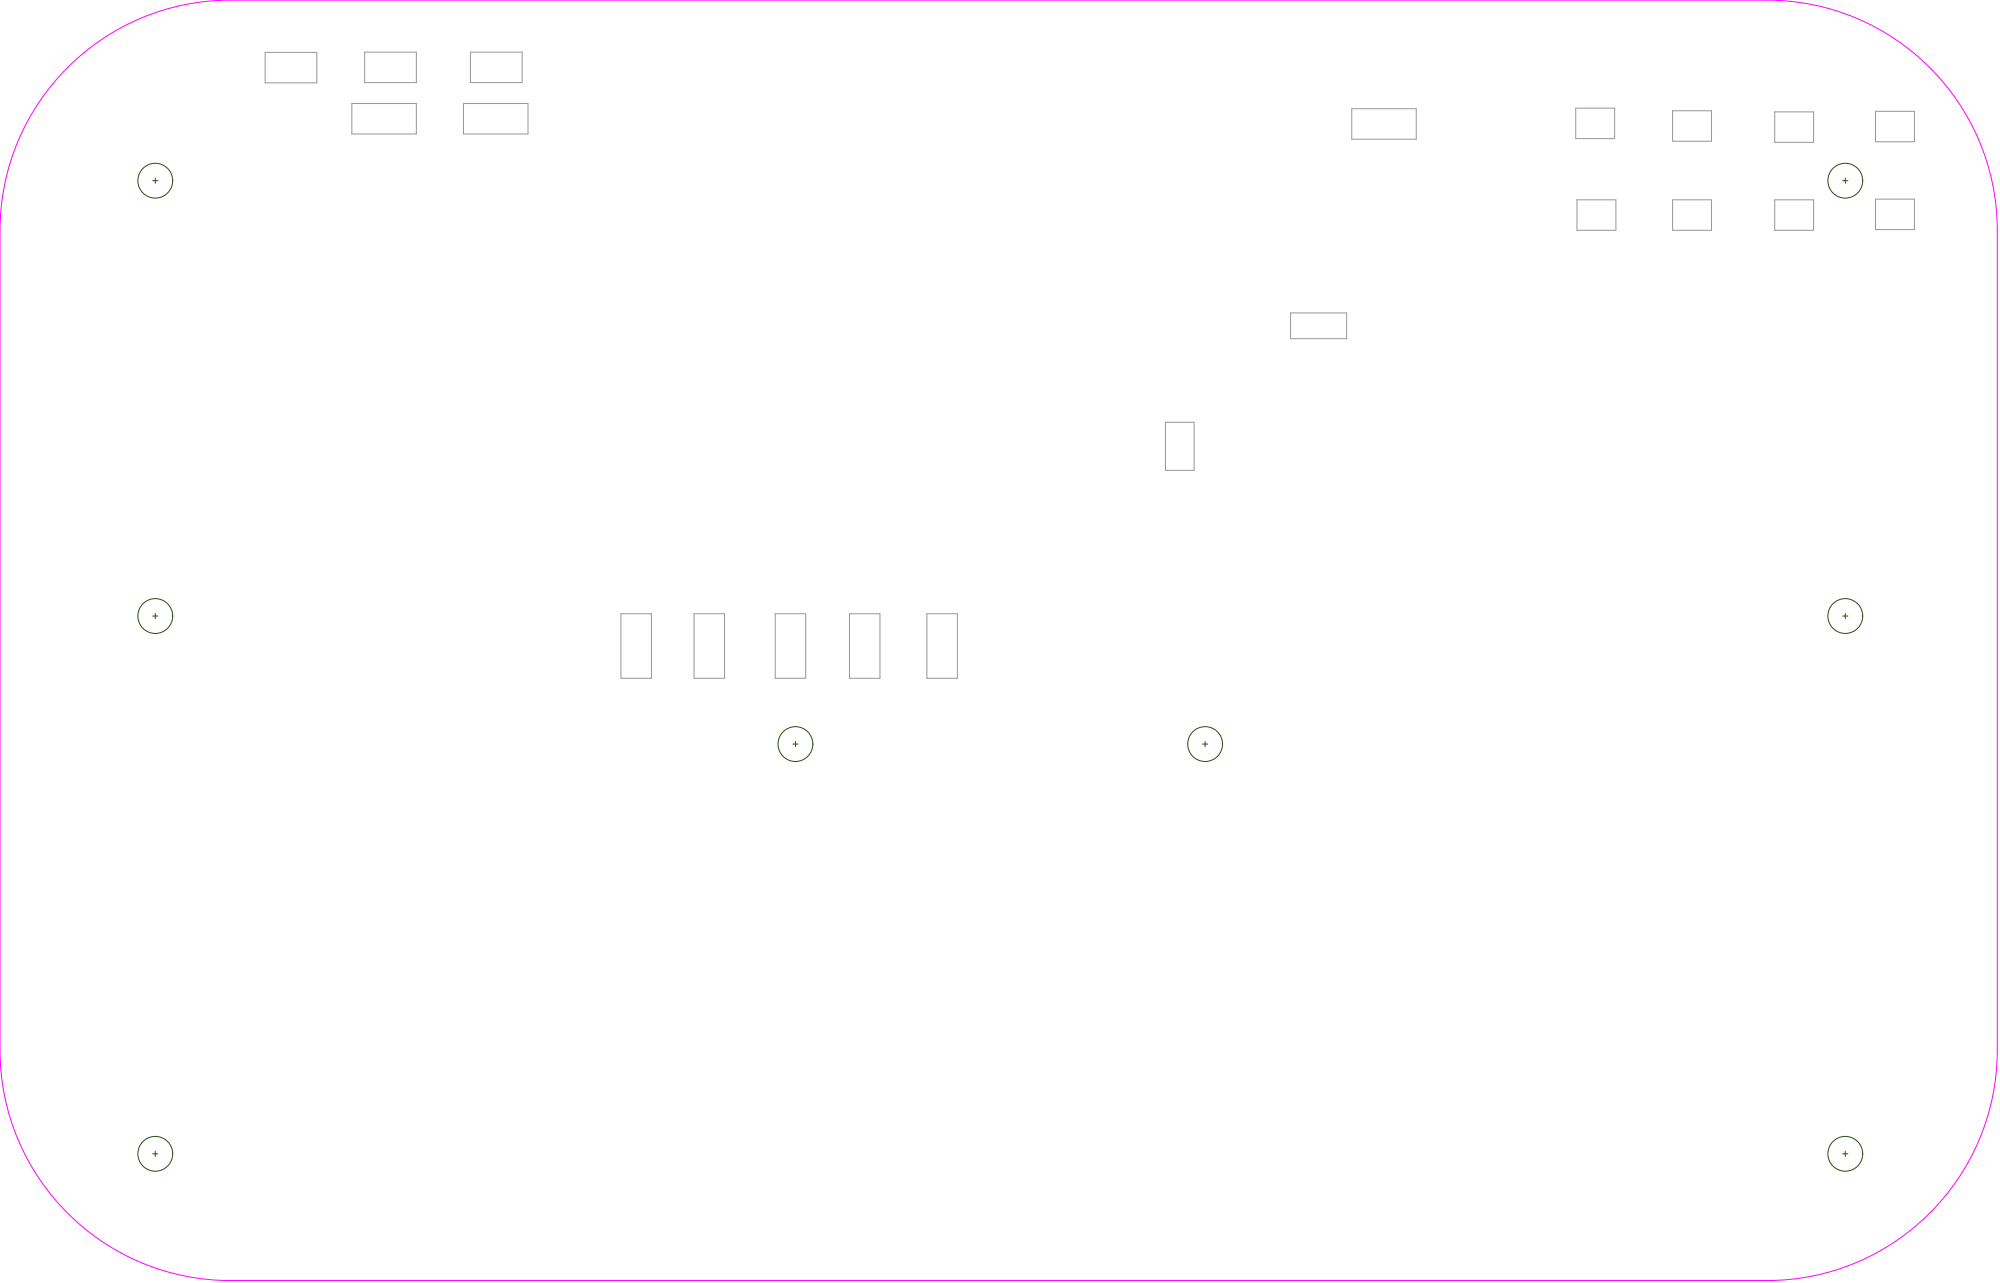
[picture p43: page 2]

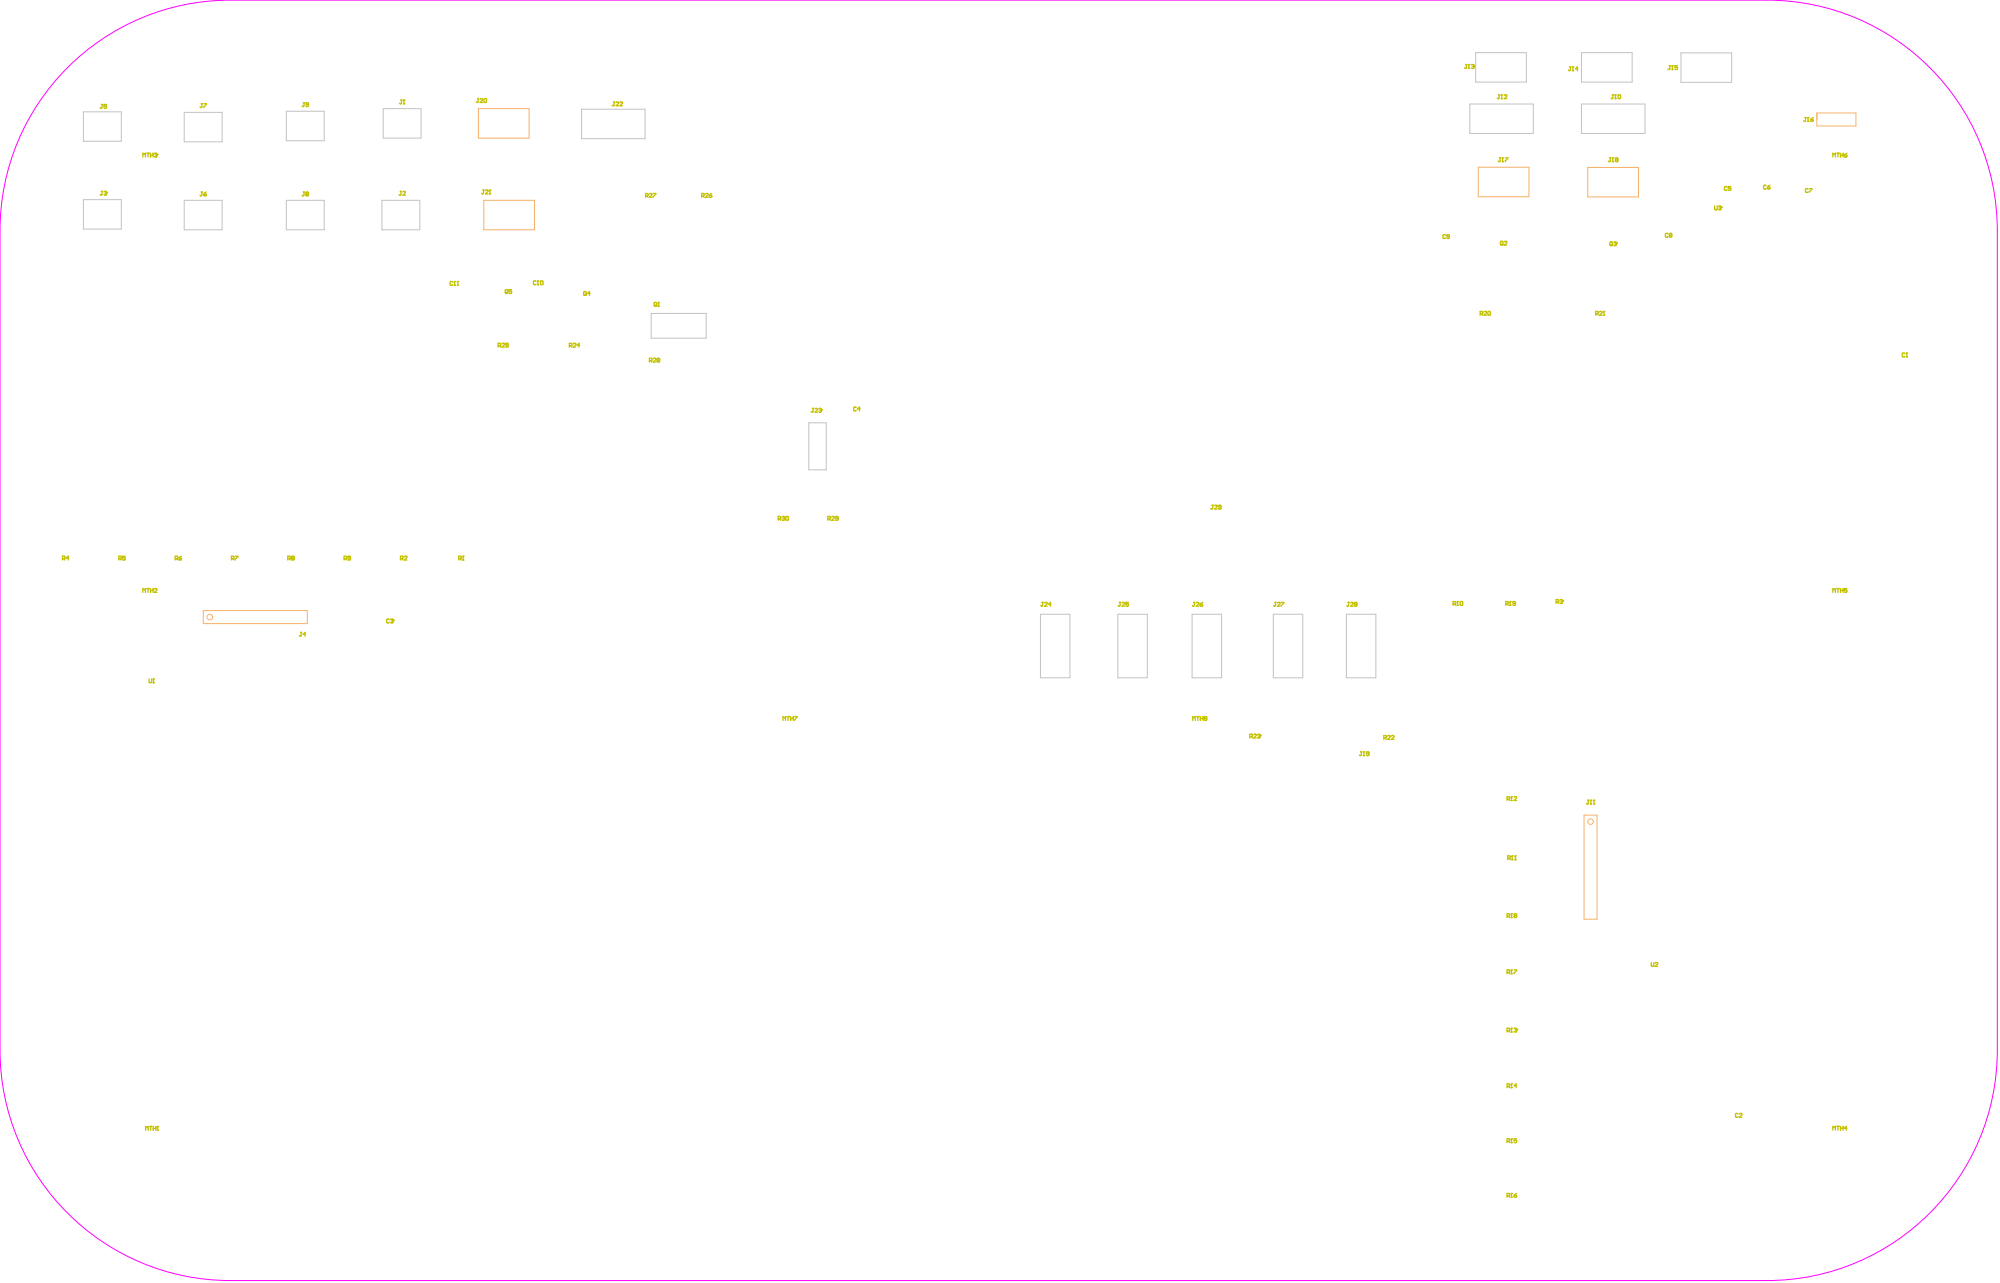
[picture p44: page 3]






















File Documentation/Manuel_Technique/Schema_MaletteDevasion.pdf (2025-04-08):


Nom de la feuille

Titredu projet
Mallette d'évasion Cours associé au projet

247-67P-SH PROJET DE FIN D'ÉTUDES

Date 2025-03-04 | Feuille 3 de Concepteurs 7

Louis Boisvert Alexis Létourneau


Titr
n Cours associé au projet

Date 2025-03-04 | F e uil l e 4 de Concepteurs 7

Lou i s Boi sv ert A l ex i s L é tourn ea u


Titr
n Cours associé au projet

Date 2025-03-04 | F e uil l e 5 de Concepteurs 7

Lou i s Boi sv ert A l ex i s L é tourn ea u


Titr
n Cours associé au projet

Date 2025-03-04 | F e uil l e 6 de Concepteurs 7

Lou i s Boi sv ert A l ex i s L é tourn ea u


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

Connecteurs pour Bandes de DEL

Connecteur male pour le PI4

Nom de la feuille

Titredu projet
Mallette d'évasion Cours associé au projet

Le GPIO26 sert à gérer l'état de la DEL (allumée ou
éteinte).

Les broches 1-2 sont toutes deux utilisées pour le
fonctionnement de la DEL.

247-67P-SH PROJET DE FIN D'ÉTUDES

Le GPIO13 sert à détecter si le bouton est actuellement
appuyé.

Les broches 2-3 sont toutes deux utilisées pour le
fonctionnement de l'interrupteur.

La résistance de 90 ohm est optionnel dépendant de la
DEL utilisé


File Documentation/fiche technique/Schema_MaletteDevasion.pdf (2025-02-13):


Connecteurs pour Bandes de DEL

Il est décidé pour l'instant
de garder les jumpers J17 ,
pin. Ceci nous permettra
une plus grande
flexibilité dans le choix
des bandes de DEL.

Pour démontré que le
3V3 provient d'ici

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

Nom de la feuille

Titredu projet
Mallette d'évasion Cours associé au projet

Le GPIO26 sert à gérer l'état de la DEL (allumée ou
éteinte).

Cours: 247-67P-SH PROJET DE FIN D'ÉTUDES

Les broches 1-2 sont toutes deux utilisées pour le
fonctionnement de la DEL.

Le GPIO13 sert à détecter si le bouton est actuellement
appuyé.

Les broches 2-3 sont toutes deux utilisées pour le
fonctionnement de l'interrupteur.


Nom de la feuille

Titredu projet
Mallette d'évasion Cours associé au projet

Cours: 247-67P-SH PROJET DE FIN D'ÉTUDES

Date 2025-01-30 | Feuille 2 de Concepteurs 6

Louis Boisvert Alexis Letourneau


-SH PROJET DE FIN D

Titr
asion Cours associé au projet


Titr
n Cours associé au projet

Date 2025-01-30 | F e uil l e 5 de Concepteurs 6

Lou i s Boi sv ert A l ex i s Le tourn ea u


GPIO20/U0RXD 22 | 6

GPIO21/U0TXD 21 | 8

Titr
n Cours associé au projet

Date 2025-01-30 | F e uil l e 6 de Concepteurs 6

Lou i s Boi sv ert A l ex i s Le tourn ea u


Titr
n Cours associé au projet

Date 2025-01-30 | F e uil l e 7 de Concepteurs 6

Lou i s Boi sv ert A l ex i s Le tourn ea u

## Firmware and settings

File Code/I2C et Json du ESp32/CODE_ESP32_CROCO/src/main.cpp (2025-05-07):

/*
Auteurs : Alexis Létourneau et Louis Boisvert
Date : 2024-11-25
Nom du fichier : main.cpp
Environnement : ESP32-C3-WROOM-02 Devkit, Platformio, C++ arduino, raspberry pi 4
Brief : Un programme pour l'envoit un json d'information en I2C à un Master sur un Raspberry PI 4. 
Ce code prend 8 patte et détecte si cette patte est connectée avec une autre patte.
Le code prend cette l'information et on met cette pair dans une liste, l'index est la sortie et le numéro à l'index est l'entrée. 
Cette liste contient donc deux fois la même connections, mais inversée. Exemple {1,0,3,2}, 1 et 0 sont connecté et 2 et 3 sont connecté.
Finalement, on envoit cette liste au Raspberry PI 4 en forme de Json.

*/

#include <Wire.h> //Communication I2C entre les esp32 et le PI
#include <Arduino.h> //Pour la programmation arduino
#include <string.h> //Pour la manipulation des string
#include <Adafruit_NeoPixel.h> 

#define SLAVE_ADDR 0x0b  // Adresse de l'esclave 

#define SDA_PIN 6
#define SCL_PIN 7

#define PIN_CROCO_0 2
#define PIN_CROCO_1 3
#define PIN_CROCO_2 18
#define PIN_CROCO_3 19
#define PIN_CROCO_4 1 
#define PIN_CROCO_5 0 
#define PIN_CROCO_6 4 
#define PIN_CROCO_7 5 
 

#define NB_CROCO 8 

#define noConnectionFound NB_CROCO //Si on ne trouve pas de connection, on met un nombre qui est plus que le nombre total de Croco

#define BRIGHTNESS 50 

void requestData(); //Prototype de fonction de réception du i2c 

String const ESP32_NAME = "I2C_Croco"; //L'ID du ESP 32

int g_listDeCrocoPin[NB_CROCO] = {PIN_CROCO_0, PIN_CROCO_1, PIN_CROCO_2, PIN_CROCO_3, PIN_CROCO_4, PIN_CROCO_5, PIN_CROCO_6, PIN_CROCO_7};
int g_pairDeCroco[NB_CROCO] = {};

String g_stringOfAllData = "";

Adafruit_NeoPixel uniDEL(1, 8, NEO_GRBW + NEO_KHZ800);

void setup() { 

  for(int curCroco = 0; curCroco < NB_CROCO; curCroco++)   //Mettre toutes les pattes "Croco" en entrée avec une pull-down
      pinMode(g_listDeCrocoPin[curCroco], INPUT_PULLDOWN);

  // Initialisation du port série pour le debug 
  Serial.begin(9600); 

  uniDEL.setBrightness(BRIGHTNESS);
  uniDEL.begin();
  uniDEL.show(); // Initialize all pixels to 'off' only run once, it runs right when you turn it on

  // Initialisation de l'I2C en tant qu'esclave avec l'adresse définie 
  Wire.setPins(SDA_PIN, SCL_PIN);
  Wire.begin(SLAVE_ADDR); 

  // Attacher une fonction de demande (request) pour le maître 
  Wire.onRequest(requestData); 

  Serial.println("Slave prêt, en attente de requêtes du maître..."); 

  //Hearbeat qui indique que le esp32 à bien démarré
  for (int i = 0; i < 3; i++)
  {
    uniDEL.setPixelColor(0, 0, 0, 255);
    uniDEL.show();
    delay(250);
    uniDEL.setPixelColor(0, 0, 0, 0);
    uniDEL.show();
    delay(250);
  }
} 
 
void loop() 
{ } 

/*
Brief : Fonction appelée lorsque le maître fait la demande des données. 
Renvoit un JSON contenant les paires de connection sur les pattes "Croco" connectées au esp32 sur la ligne i2c.
*/
void requestData() { 
  //Indique avec la DEL que le esp32 est entrain de résoudre une requête, s'éteint à la fin de la requête
  uniDEL.setPixelColor(0, 0, 0, 255);
  uniDEL.show();
  bool foundConnection = false; //Flag si on a detecte une connection

  //Chaques pattes "Croco" va être mit en sortie pour sondées les autres pattes en entrée
  for(int curOut = 0; curOut < NB_CROCO; curOut++) 
  { 
    pinMode(g_listDeCrocoPin[curOut], OUTPUT); //Patte "Croco" en sortie pour envoyer un signal
    digitalWrite(g_listDeCrocoPin[curOut], HIGH); //Le signal haut à détecter

    //Tout les autre pattes "Croco" en entrée vont être lu pour savoir s'ils ont reçu un signal
    for(int curIn = 0; curIn < NB_CROCO; curIn++)
    { 
      if(curIn != curOut)  //Si c'est pas la patte "Croco" en sortie
      {
        pinMode(g_listDeCrocoPin[curIn], INPUT_PULLDOWN); //On met la patte "Croco" en mode entrée
        if (digitalRead(g_listDeCrocoPin[curIn])) //Si on détecte le signal haut du "Croco" en OUTPUT
        {
          g_pairDeCroco[curOut] = curIn; //On enregistre la pair dans une liste, l'index est la sortie et le numéro à l'index est l'entrée. 
          foundConnection = true; 
        }
      }      
    }
    if (!foundConnection) //Si on trouve pas de connection, on met un nombre qui est plus grand que le nombre de "Croco" dans la liste pour indiquer aucune connection
      g_pairDeCroco[curOut] = noConnectionFound;
      
    digitalWrite(g_listDeCrocoPin[curOut], LOW); //On remet la patte "Croco" sortie en mode entrée
    foundConnection = false;
  }

  //Crée une string json pour contenir les paires de patte croco
  String stringOfInteractable = "[\"" + String(g_pairDeCroco[0]) + "\",\"" + String(g_pairDeCroco[1]) + "\",\"" 
                                      + String(g_pairDeCroco[2]) + "\",\"" + String(g_pairDeCroco[3]) + "\",\""
                                      + String(g_pairDeCroco[4]) + "\",\"" + String(g_pairDeCroco[5]) + "\",\"" 
                                      + String(g_pairDeCroco[6]) + "\",\"" + String(g_pairDeCroco[7]) +"\"]";

  //Crée une string json pour contenir le nom du esp32 et les objets
  g_stringOfAllData = "{\"NomEsp32\":\"" + ESP32_NAME 
                   + "\",\"JsonData\":" + stringOfInteractable + "}";

  // Envoyer les données du tableau `dataToSend` au maître 
  for (int i = 0; i < g_stringOfAllData.length(); i++)
    Wire.write(g_stringOfAllData[i]);  // Envoyer chaque caractère en byte
  
  Wire.write(0x00);  // Le Master repete le dernier byte recu, donc le dernier byte est NULL pour signaler la fin de la string
  uniDEL.setPixelColor(0, 0, 0, 0);
  uniDEL.show();
} 

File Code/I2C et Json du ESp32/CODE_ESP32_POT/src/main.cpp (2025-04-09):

/*
Auteurs : Alexis Létourneau et Louis Boisvert
Date : 2024-11-25
Nom du fichier : main.cpp
Environnement : ESP32-C3-WROOM-02 Devkit, Platformio, C++ arduino, raspberry pi 4
Brief : Un programme pour l'envoit un json d'information en I2C à un Master sur un Raspberry PI 4. 
Ce code prend l'état de 3 potentiomètres et le met dans un dictionnaire.
Finalement, on envoit ce dictionnaire au Raspberry PI 4 en forme de Json.

CE CODE A UN AJUSTEMENT TEMPORAIRE À CAUSE D'UN PROBLÈME DE PCB
Il faut rerouter les pin 9, 8 et 5 à 0, 1 et 2, donc il faut désactiver les pattes 9, 8 et 5 comme décrit à la ligne 57
*/

#include <Wire.h> //Communication I2C entre les esp32 et le PI
#include <Arduino.h> //Pour la programmation arduino
#include <string.h> //Pour la manipulation des string
#include <Adafruit_NeoPixel.h> 

#define SLAVE_ADDR 0x09 

#define SDA_PIN 6
#define SCL_PIN 7

#define NUM_POT 3  

#define BRIGHTNESS 50 

#define DEBUG true

void requestData(); //Prototype de fonction

const int POT_PINS[NUM_POT] = {0, 1, 2}; // Pins des pot en ordre
const String POT_NAMES[NUM_POT] = {"Pot1", "Pot2", "Pot3"}; // Noms des interrupteurs dans le meme ordre que POT_PINS

const String ESP32_NAME = "I2C_Pot"; //L'ID du ESP 32
  
int potStates[NUM_POT] = {0};  //Init toutes les valeurs à 0

String stringOfAllData = "";

Adafruit_NeoPixel uniDEL(1, 8, NEO_GRBW + NEO_KHZ800);

void setup() { 

  // Initialisation du port série pour le debug 
  Serial.begin(115200); 

  // Initialisation de l'I2C en tant qu'esclave avec l'adresse définie 
  Wire.setPins(SDA_PIN, SCL_PIN);
  Wire.begin(SLAVE_ADDR); 

  // Attacher une fonction de demande (request) pour le maître 
  Wire.onRequest(requestData); 

  Serial.println("Slave prêt, en attente de requêtes du maître..."); 

  //Hearbeat qui indique que le esp32 à bien démarré
  for (int i = 0; i < 3; i++)
  {
    uniDEL.setPixelColor(0, 0, 255, 0);
    uniDEL.show();
    delay(250);
    uniDEL.setPixelColor(0, 0, 0, 0);
    uniDEL.show();
    delay(250);
  }
  //Initialise les pattes en entrée
  for (int i = 0; i <NUM_POT; i++)
  {
    pinMode(POT_PINS[i], INPUT);
  }
  /*TEMPORAIRE, parce que le PCB est mauvais, il faut rerouter les pin 9, 8 et 5 à 0,1 et 2, donc il faut désactiver ces pattes*/
  pinMode(9, INPUT);
  pinMode(8, INPUT);
  pinMode(5, INPUT);
} 
 
void loop() 
{} 
 
/*
Brief : Fonction appelée lorsque le maître fait la demande des données. 
Renvoit un JSON contenant les état des interrupteurs et des potentiomètres connectés au esp32 sur la ligne i2c.
*/
void requestData() { 
  //Indique avec la DEL que le esp32 est entrain de résoudre une requête, s'éteint à la fin de la requête
  uniDEL.setPixelColor(0, 0, 0, 255);
  uniDEL.show();
  for (int i = 0; i < NUM_POT; i++)
    potStates[i] = analogRead(POT_PINS[i]);

  //cette boucle crée une string json pour contenir les interrupteurs et potentiomètres
  String stringOfInteractable = "{";
  for (int i = 0; i < NUM_POT; i++) 
  {
    if( i == NUM_POT-1) //permet de ne pas avoir de virgule à la fin du json
    {
      stringOfInteractable += "\"" + POT_NAMES[i] + "\":\"" + potStates[i] +"\"";
    }
    else
    {
      stringOfInteractable += "\"" + POT_NAMES[i] + "\":\"" + potStates[i] +"\",";
    }
  }

  //Crée une string json pour contenir le nom du esp32 et les objets
  stringOfAllData = "{\"NomEsp32\":\"" + ESP32_NAME 
                   + "\",\"JsonData\":" + stringOfInteractable + " } }";

  if (DEBUG)
    Serial.print(stringOfAllData);
    
  // Envoyer les données du tableau `dataToSend` au maître 
  for (int i = 0; i < stringOfAllData.length(); i++)
    Wire.write(stringOfAllData[i]);  // Envoyer chaque caractère en byte
  
  Wire.write(0x00);  // Le Master repete le dernier byte recu, donc le dernier byte est NULL pour signaler la fin de la string
  uniDEL.setPixelColor(0, 0, 0, 0);
  uniDEL.show();
} 

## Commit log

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2024-10-29 Add files via upload
    version beta du système de communication
2024-10-31 Add files via upload
    Code pour la réception et l'envoie de donnée analogique sur le bus I2C
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2024-11-21 I2c entre Pi et E32 fonctionnel mais lent
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2024-11-25 Commentaire sur le code du slave I2C esp32
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2024-12-03 Nettoyage des fichier en enlevant "Code gui dans PI"
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2024-12-11 Correction Ben code final
    [main.cpp]
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2025-01-29 Ajout de commentaire dans les code ESP32 et Pi
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2025-02-04 correction des erreurs précédentes
    [main.cpp]
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2025-02-06 Ajout de Update all window et try catch dans le GUI
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2025-02-13 nouvelle branche github
    la partie conception/pcb de notre projet
    [74HC1G125-Q100.SchLib, 74HC1G125GV-Q100H.STEP, ESP32-C3-DEVKITC-02.SchLib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]
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2025-02-13 ajout d'une page qui va servir à l'alimentation
    [TEMPLATE_Connectors.SchDoc, Title_Page.SchDoc]
2025-02-18 pcb changes
    [Alimentation.SchDoc, Alimentation_USB_Header.SchDoc, Raspberry_Pi_4_ModelB.SchDoc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]
2025-02-18 léger changements
    [Alimentation_USB_Header.SchDoc, Raspberry_Pi_4_ModelB.SchDoc, Schema_MaletteDevasion.PrjPcb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]
2025-02-18 pcb alim
    [Raspberry_Pi_4_ModelB.SchDoc, TEMPLATE_PCB_2L.PcbDoc]
2025-02-20 changement du code du ESP32 POT pour 3 pot
    [Alimentation_USB_Header.SchDoc]
2025-02-20 pcb module d'énigme placer en majorité
    [Raspberry_Pi_4_ModelB.SchDoc, Schema_MaletteDevasion.PrjPcb, TEMPLATE_PCB_2L.PcbDoc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]
2025-02-22 conception du PCB terminer
    théoriquement le PCB devrait désormais être terminer, je demanderais tout de même un petit review pour s'assuré que se soit correcte. je lui ai fait vérifier si il respectait les règles, il est bon malgré qu'il y a des erreurs qui semble être fausse. J'ai waive et corriger les erreurs qui étais réelle , puis j'ai laisser les erreurs que je voudrais avoir un deuxième avis. Il restera par la suite de créer les fichiers de fabrications
    [Schema_MaletteDevasion.PrjPcb, TEMPLATE_PCB_2L.PcbDoc]
2025-02-24 changement mineur pcb
    encore besoin de révision
    [Schema_MaletteDevasion.PrjPcb, Schema_MaletteDevasion.xlsx, TEMPLATE_PCB_2L.PcbDoc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]
2025-02-26 PCB manque headers
    [Alimentation_USB_Header.SchDoc, MalletteV2_PCB_2L.PcbDoc, Raspberry_Pi_4_ModelB.SchDoc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]
2025-03-04 version 2 du pcb avec MTH et bonne dimension
    [74HC1G125-Q100.SchLib, 74HC1G125GV-Q100H.STEP, Alimentation.SchDoc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]
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2025-03-05 Un autre push parceque altium me laisse pas faire les output files sans avoir commit
2025-03-11 Ajout du plan de test
    [74HC1G125-Q100.SchLib, 74HC1G125GV-Q100H.STEP, Alimentation.SchDoc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]
2025-03-11 code pour la library et optimisation
    énigme Croco, Del et I2c sont terminer et commenter avec un brief
    il me reste énigme Pot et Switch
    Del va être obselète
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2025-03-12 division de code est terminer
    les 3 énigmes sont tester et commenter.
    il ne reste plus qu'a modifier la library des dels
2025-03-13 ajout de commentaire, nouveau del fonctionne
    le code de del d'Alexis est désormais intégré au main du code divisé
2025-03-19 Ajout de Gerber Files
    [74HC1G125-Q100.SchLib, 74HC1G125GV-Q100H.STEP, Alimentation.SchDoc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]
2025-03-31 Update plan de test
    [Schema_MaletteDevasion_BOM REV 1.00.xlsx, Schema_MalletteDevasion_BOM REV 1.00.xlsx, plan de test PCB mallette (1).xlsx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]
2025-03-31 Update plan de test PCB mallette (1).xlsx
    [plan de test PCB mallette (1).xlsx]
2025-03-31 Nettoyage des fichiers
    [plan de test PCB mallette (1).xlsx]
2025-04-01 changements pins pour bananes
    l'ordre des bornes bananes ont été rétabli à un ordre croissant
2025-04-02 Ajout reset esp32 et heartbeat
    [Raspberry_Pi_4_ModelB.SchDoc, plan de test PCB mallette (1).xlsx, Énigme1_Switch.SchDoc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]
2025-04-02 Update README.md du fichier matériel
    ajout d'un début de description pour le matériel
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2025-04-07 modif RasPi
    ce sont les dernières modification effectuer avant que je commence à travailler sur le Raspberry Pi
2025-04-07 test pour mettre plusieurs énigmes dans un écran
    le code est fonctionnel avec notre Raspberry PI, mais ne sera pas fonctionnel sur github, car il y a quelques éléments à changer dans les énigmes
2025-04-08 Avancement sur le MAN, manque développement
    [!EvaluationCouts_malette&accessoire.xlsx, Exemple_EvaluationCouts.xlsx]
2025-04-09 Avancement du MAN
    [Exemple_EvaluationCouts.xlsx]
2025-04-14 ajout des autres type d'interfaces
    ATTENTION!!!
    il faut que les interrupteurs donnent leur layout aulieu de leur fenêtre qui est normalement donner par le code Class_SW
2025-04-14 test de couleur et légère modification
    comme indiquer dans le code color_change, il est uniquement possible de changer les couleurs des objets après la création de la fenêtre
2025-04-15 update du plan de test
    un bug à été découvert en rapport avec les dels
    [plan de test PCB mallette (1).xlsx]
2025-04-16 Correction readme clavier et update MAN
    [Exemple_EvaluationCouts.xlsx]
2025-04-16 update MAN et ajout stl equerre
    [Equerre_2_inserts.stl, Exemple_EvaluationCouts.xlsx]
2025-04-22 MAN fini sans correction et formatage
    [Exemple_EvaluationCouts.xlsx, Raspberry_Pi_4_ModelB.SchDoc, Énigme3_Potentiomètres.SchDoc]
2025-04-23 code de l'interface plus esthétique
    peut uniquement rouler test_main.py, toutes les énigmes sont dans la même fenêtre, mais est plutôt lent
2025-04-30 update pi code
    [plan de test PCB mallette (1).xlsx, plan de test PCB mallette.xlsx]
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2025-05-05 correction Main.py
    j'ai rendu l'accès au labyrinthe modulable pour éviter de future problème
    [main.py]
2025-05-05 unifformation des clavier esp32
    section mélangeante, car il y avait un main.py qui ne servait à rien, un code.py et un code.py qui n'était pas à jour
2025-05-07 léger changement dans les pins des esp32
    j'ai changer les pins de certains esp32 pour qu'il puisse mieux s'adapté à la mallette
2025-05-07 update de code des énigmes
    gestion des dels et ajout de fonctionnalité de DEBUG (le bouton "exit" n'est pas présent si la variable DEBUG est fausse
2025-05-07 MAN v2
    [EvaluationCouts.xlsx, Exemple_EvaluationCouts.xlsx]
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2025-05-12 Update README.md
    test numéros 3 et correction de fautes d'orthographe
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2025-05-13 Update README.md
    modification de la méthode d'installation de PysimpleGUI et test pour le formatage de la page
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
